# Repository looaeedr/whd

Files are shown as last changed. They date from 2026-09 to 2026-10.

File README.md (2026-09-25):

---
whd_doc_role: REFERENCE
whd_contract: repo-overview
whd_canonical: null
whd_schema: WHD_DOC_META_V1
---
<!-- WHD_DOC_ROLE role=REFERENCE contract=repo-overview -->
> **[REFERENCE]** 本 README 只提供專案概覽；其中既有架構描述保留作歷史背景，不擁有 current manufacturing contract。
> Current authority pointers：
- `個人AI檔案庫/第二層_專案與SOP/09_WHD_Canonical_Authority_Map.md` — contract/role ownership map。
- `個人AI檔案庫/第二層_專案與SOP/04_WHD鈑金展開幾何引擎規範.md` — 現行 `ae_engine` 製造架構、公開 API 與 Certified Registry boundary。
- `AGENTS.md` — Agent 啟動、Preflight、派工與驗收流程入口。

# WHD 板金展開自動化系統 (Sheet-Metal Unfolding Geometry Engine)

WHD 鈑金展開自動化系統是一套專為鈑金箱體加工設計的 2D 自動展開與 DXF 生成引擎。本系統已全面揚棄傳統「硬編碼頂點陣列 (Hardcoded Vertex Arrays)」與「單一零件獨立座標演算法」的舊式做法，採用現代幾何拓撲 (Topology) 與布林運算 (Shapely Polygon Boolean) 的核心架構。

---

## 💡 核心設計理念與架構宣告

> **「告別『新增零件 = 新寫一套外框公式』的傳統思維！」**

在全新幾何引擎中，所有零件外形皆收斂為以下核心公式：

Material Polygon = Base Polygon - Relief Polygon

1. **Topology (拓撲結構) 與 Factory Policy (製造規範) 徹底分離**：
   - **Topology**：定義板材的物理折彎結構（如四邊折彎 FourSideFlange、連續展開條帶 StripFoldChain）。
   - **Factory Policy**：定義各廠牌或特定箱體類型的裝配退讓（Relief）、過切 clearance 與缺角規則（如金庫型封頭尾裝配插入退讓）。
2. **新增零件極簡化**：
   - 未來新增任何新零件類型時，**嚴禁**重新手算 12 點、16 點或 17 點頂點陣列。
   - 只要既有的 Topology 與 Factory Policy 能描述該結構，新零件**僅需傳入折邊尺寸與裝配扣量**即可自動計算出 100% 精準的 2D 展開幾何。
3. **Geometry 是唯一真相來源 (Single Source of Truth)**：
   - GUI 預覽（Canvas）與 DXF 檔案導出統一呼叫 sheetmetal_geometry.py 幾何結果，確保「畫面所見即為 DXF 所出」。

---

## 🛠️ 系統分層架構

- **Layer A (sheetmetal_geometry.py)**：純 2D 板金幾何引擎。獨立於 DXF 與 GUI，只負責 Polygon 算術與 Bend 計算。
- **Layer B (ae.py)**：參數轉接層。讀取 config.ini / CSV 並呼叫幾何引擎生成各加工圖層（CUTTING, BEND, MARKING, CHECK 等）。
- **Layer C (gui.py / batch_unfolder.py)**：GUI 操作介面與自動化批次處理產線。

---

## 📦 目前已涵蓋的零件拓撲

- Door / Stretched Door (門板 / 延伸門板)
- Box Body / Stretched Box Body (箱身 / 延伸箱身)
- End Cap / Tail (金庫型封頭 / 封尾)
- Indicator Box (指示燈盒子 / 小門)
- Base Plate (底板)

---

## 🚀 快速開始

### 環境需求
- Python 3.8+
- Shapely
- ezdxf

### 安裝依賴
`ash
pip install -r requirements.txt
`

### 執行 GUI 計算器
`ash
python gui.py
`

### 執行完整測試套件 (TDD Baseline)
`ash
pytest
`

---

## 📖 系統文件與交接指南

更詳細的開發規格與金庫型製造規範請參考專案文件：

- AGENTS.md — 專案核心精神與 AI 開發總覽。
- handoff/ 目錄：
  - 00_AI_HANDOFF_README.md — 快速接手說明
  - 01_ARCHITECTURE.md — 幾何與拓撲分層架構
  - 02_VAULT_FACTORY_RULES.md — 金庫型製造規範細節
  - 03_PART_TOPOLOGY_MAP.md — 零件與拓撲對照表
  - 04_DEVELOPMENT_RULES.md — 開發規範與 TDD 驗證

---

## 📄 授權與維護
© WHD Sheet Metal Automation System. All rights reserved.

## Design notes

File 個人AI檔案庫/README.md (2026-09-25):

---
whd_doc_role: REFERENCE
whd_contract: ai-library-reference
whd_canonical: null
whd_schema: WHD_DOC_META_V1
---

# 個人 AI 檔案庫

本 README 是 **AI Library 的導覽入口**，不是 WHD production、幾何、UI、release、remote QA 或 executable process 的 CURRENT authority。

AI Library 的用途是保存長期背景、協作偏好、專案 SOP、canonical authority 導覽，以及事故／踩坑 REFERENCE。任何規則若已有 CURRENT owner，README 只指向該 owner，不複製第二份 current prose。

## 目錄導航

目前頂層結構：

```text
個人AI檔案庫/
├── README.md
├── 第一層_核心檔案/
├── 第二層_專案與SOP/
└── 踩坑庫/
```

### 第一層_核心檔案

- `01_個人背景與身份.md`：長期背景與角色資訊。
- `02_溝通風格與輸出偏好.md`：溝通與輸出偏好。
- `03_核心目標與近期重點.md`：核心目標與近期重點。
- `04_全域AI協作規則.md`：跨任務 AI 協作 REFERENCE；不擁有 executable/process/domain CURRENT authority。
- `05_反饋學習與自我演化機制.md`：反饋與知識沉澱機制。

### 第二層_專案與SOP

主要入口包含：

- `01_DXF與CAD自動化全域規範.md`
- `02_通用任務SOP模板.md`
- `03_常用Prompt指令庫.md`
- `04_WHD鈑金展開幾何引擎規範.md`
- `05_CAD批次拆圖與特徵萃取規範.md`
- `06_踩坑記錄與防錯經驗庫.md`
- `07_Phase6尺寸語意與標準截角母規則.md`
- `07_WHD技能發現與掃描深模組規則.md`
- `08_WHD截角資料與2D入口收斂規則.md`
- `08_WHD技能建立與修改規則.md`
- `09_WHD_Canonical_Authority_Map.md`

第二層也可能包含日期化 verification、專案交接或其他 REFERENCE 文件；**檔名看起來較新不代表它是 CURRENT owner**。

### 踩坑庫

`踩坑庫/` 保存事故、反例、踩坑與復原經驗。這些資料可協助診斷與避免重犯，但不得因內容較詳細就覆蓋 CURRENT spec、Skill、registry 或 executable authority。

## Authority 規則

唯一的 canonical authority 導覽入口是：

`個人AI檔案庫/第二層_專案與SOP/09_WHD_Canonical_Authority_Map.md`

使用順序固定為：

```text
先找 Authority Map
→ 找到該 contract 的 CURRENT owner
→ 讀 CURRENT owner
→ 再用 REFERENCE / pitfall / historical evidence 補充背景
```

角色語意：

- `CURRENT`：該 contract 唯一現行 owner。
- `REFERENCE`：背景、方法、事故或延伸說明；不得覆蓋 CURRENT。
- `MIRROR`：相容入口／導覽，只能 pointer 到 canonical owner。
- `HISTORICAL`：歷史證據，不得進 current routing。

若 README、REFERENCE 或歷史文件與 Authority Map 指向的 CURRENT owner 衝突，以 CURRENT owner 為準；不要在 README 裡再建立平行規格。

## 使用方式

開始 WHD 任務時：

1. 先依 `09_WHD_Canonical_Authority_Map.md` 找到 contract owner。
2. 若屬 startup / process routing，依 `AGENTS.md` 與 required Skill 執行。
3. 若屬 manufacturing / geometry / UI / DXF / persistence 等 domain 行為，讀 Authority Map 指向的 CURRENT owner，不從 README 猜規格。
4. 需要事故背景時再讀 `06_踩坑記錄與防錯經驗庫.md` 或 `踩坑庫/`。
5. 驗證結果只能判斷實作是否符合 authority，不能反過來成為 production 或文件真值來源。

一般原始碼與文件修改以 **Git branch / commit** 為主要 rollback authority，不為每個檔案自動建立額外實體備份。只有下列情況才另外建立實體備份：

- 使用者明確要求；
- Git 無法保存或還原的外部資產；
- 高風險二進位資產。

本 README 不保存日期型 UI 狀態、Assembly layout、EndCap positioning、release 細節或其他產品 CURRENT 規格；這些內容應由各自 CURRENT owner、REFERENCE/HISTORICAL 文件、verification、Git history 或 GitHub Issue 保存。

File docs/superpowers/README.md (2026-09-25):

---
whd_doc_role: REFERENCE
whd_contract: superpowers-history-index
whd_canonical: null
whd_schema: WHD_DOC_META_V1
---
<!-- WHD_DOC_ROLE role=REFERENCE contract=superpowers-history-index -->
> **[REFERENCE / HISTORY INDEX]** 本目錄 README 索引 dated Superpowers/spec/verification evidence，不是 current manufacturing 或 project roadmap authority。
> Current authority：`個人AI檔案庫/第二層_專案與SOP/09_WHD_Canonical_Authority_Map.md`；製造架構/API：`個人AI檔案庫/第二層_專案與SOP/04_WHD鈑金展開幾何引擎規範.md`。

# Superpowers 接手說明 — 2026-08-21 截角類型／裝配語意

任何接手這次修改的代理或開發者，請依序閱讀：

1. `specs/2026-08-21-corner-type-semantic-assembly-design.md` — 已確認的工廠規則、資料責任與不可回退決策。
2. `plans/2026-08-21-corner-type-semantic-assembly-implementation.md` — 實作任務、修改檔案、介面與已完成項目。
3. `verification/2026-08-21-corner-type-semantic-assembly-verification.md` — 測試、DXF 製造驗證、原始 renderer 不變與行尾注意事項。
4. `../../修改日誌/20260821.md` — 人員可快速閱讀的修改摘要。

## 語言規則

- **使用者可見介面一律使用繁體中文。**
- 新增或修改的操作說明、錯誤訊息、固定截角摘要與交付文件應優先使用繁體中文。
- **程式內部識別字**（Python 類別、函式、enum、欄位、API 參數與相容代碼）為避免破壞相容性可保留英文，例如 `CornerTypeId`、`CrossCornerMode`、`INSERT_OVERLAY`。
- 文件若必須提到英文識別字，需同時用繁體中文說明其製造意義，不能只留下英文名稱讓操作人員自行猜測。

## 不可回退的關鍵決策

- 截角類型本身就是裝配關係；不要再新增另一套可獨立修改的裝配旗標。
- 新 GUI 禁止回到 `C01~C04` 或 `0°/90°` 的截角操作方式。
- 嵌入貼外型第二級參數在 UI 仍叫「嵌入留肉」，但**正確二級 CUTTING = 側折 + 嵌入留肉量**；`FW - 嵌入留肉量` 只是兩級切線之間剩下的材料寬度，不是切線座標。
- 純嵌入會讓箱身高度由 `H-2T` 變成 `H-T` 或 `H`；孔位與特徵基準必須同步。
- `fold_designer_original.py` 的製造幾何與操作模型保持不動；本次只允許為「全域文字縮放」增加字級倍率。
- 型號 UI 使用「自訂」；它是目前已知資料的可編輯副本，不是另一套空白預設。舊「未知類型」只做相容讀取。
- 指示燈盒與指示燈小門是共享固定板件，截角類型唯讀。

## 2026-08-21 晚間修正

- 已撤銷先前錯誤的 `39mm` 二級截角規格。`側折=15、T=2、嵌入留肉=0.5T` 時，正確二級 CUTTING 為 `16mm`、深度 `4mm`。
- 新增全域 **文字大小：小 / 中 / 大**。現有字級定義為「小」；中為 `1.2×`、大為 `1.4×`。
- 文字縮放只改 Tk/ttk/Canvas/Matplotlib 文字，不改 CAD 幾何、畫布座標、DXF 尺寸或折彎數值。
- 交付與 patch 不覆蓋現場 `config.ini`；使用者切換文字大小時才由程式寫入 `[UI] text_size`。
## 2026-08-23：Phase6 截角／貼外型後續修正

本輪接手時，除上列既有文件外，必須再遵守以下已確認規則：

- **上方 CornerType 是封頭／封尾裝配語意真值。** `assembly_type` 只能作 UI／相容 mirror，不得在載入時反向覆寫上方 CornerType。
- **貼外型（`OVERLAY`）的封頭／封尾沒有左右 X 向折彎。** 因此 2D／3D 不生成這些 X 向 BEND，Fold Designer 的 Head/Tail 不顯示 X 軸折彎頁。
- **OVERLAY 的 X 材料外框同樣沒有舊折邊寬。** Head/Tail flat span = `W`；不得保留 `W-4T+yl1+yr1` 的舊 INSERT 型材料寬。下方 `WIDTH+1.5T` 只屬角落 CUTTING。
- **使用者明確選擇 `OVERLAY` 時，下方截角帶入既有 CROSS 多切預設：`EXTRA_CUT + WIDTH + 1.5T`。** 這只是本次選擇時的初始值；之後使用者仍可改成高、寬＋高或其他既有 CROSS 設定。普通 refresh/load 不得把人工修改洗回預設。
- `CROSS + EXTRA_CUT` 是通用幾何手段，不等同單一機械目的；可用於避讓自身折邊，也可用於避讓組裝後另一片板金。不得因此新增重複 CornerType。
- 自訂模式不載基準 DXF，因此基準檔專屬開孔／固定孔設定不得在自訂模式顯示；也不得從「進階設定」繞路重新出現。
- 箱身「對稱折彎」入口放在 Fold/BEND 編輯區；對稱模式下刪除可刪折段時，鏡像段必須交易式同步刪除。
- 3D Fold Designer 是 modal transaction：開啟期間主 2D 不得同時修改；確定才提交，取消／關閉丟棄草稿。
- 2D CornerType 縮圖方向依 active target：上方維持垂直翻轉，下方恢復原始方向；只改 preview canvas，不改製造幾何。
- UI 數值不得露出 `400.0000000000006` 類浮點尾差；近整數只做文字正規化，合法小數保持。
- **不得碰 `config.ini`，除非使用者明確要求。** 交付固定提供完整包與只含本次變更檔的更新包，FULL/UPDATE 檔名共用 Asia/Taipei `YYYYMMDD_HHMMSS` 時間戳。

詳細截角層級與 OVERLAY 規則見 `specs/2026-08-21-corner-type-semantic-assembly-design.md` 的 2026-08-23 補充。

## 操作員使用說明書

- `../../使用說明書.md` — 使用者操作手冊；現已包含正式截角類型、十字截角模式、方向、xT、封頭／封尾上下截角用途與舊 C01~C04 對照。

- **板件存在狀態全鏈規則**：`existing_parts` 是 physical presence 單一真值；輸出 checkbox 不得決定存在性。刪除板件要同步從左側尺寸、右側 2D、3D、FinalScene、保存/重載與 DXF/NC/批次輸出消失，profile stash 只供重新新增恢復。
- **除錯範圍規則**：修一個症狀必須主動追完整資料鏈，不等待使用者逐層提醒相依問題。

## 2026-08-23：全域專案檔案操作（取代舊 3D Footer 讀／存入口）
- `.p6fold` 是**整個專案**；主視窗左上角固定提供「開啟專案 / 儲存專案 / 另存新檔」。3D 是 modal，因此 3D 視窗左上角也提供同一組全域入口；不得綁在某一板件頁或 3D Footer。
- 各板件頁／3D 編輯器只負責自己的 draft 交易：`套用 / 確定 / 取消`；不得把局部交易按鈕命名或實作成全專案存檔。
- `開啟專案` 與 Windows 雙擊 `.p6fold` / argv 共用主 GUI 的 authoritative `load_phase6_project()`；不得建立第二套 restore 邏輯。
- `儲存專案`：已有目前路徑時直接覆存完整 `.p6fold`；無路徑時轉入「另存新檔」。`另存新檔` 才詢問新路徑。
- GUI 全域「開啟專案」只還原主專案，不強迫跳進 3D；雙擊 `.p6fold` 的啟動流程可依既有 argv 行為開到保存的 active part。
- 讀檔後 `existing_parts`、2D/3D、輸出資格、CornerType/Fold/features 與全域尺寸必須同步來自同一 snapshot。

## 2026-08-23：CornerType 細參數鎖
- CornerType 細參數預設 **鎖定並真正隱藏**；2D/3D 都必須有明確 `參數鎖定 / 參數解鎖` 文字。鎖定時細節 frame 與 `左右相同` 等進階控制零佔位，只保留 CornerType/摘要供辨識。
- 鎖只是 UI 防誤觸，不是製造資料；鎖定／解鎖不得修改 `CornerTypeSelection`，也不保存成 `.p6fold` 機械狀態。載入專案後 UI 一律回到鎖定。
- 自訂盤型：CornerType 類型照既有規則可選；細參數需解鎖才可改。
- 已知盤型：factory CornerType **類型固定不可改**，但同一類型的細參數可解鎖微調；人工細參數必須走完整 Save/Load、2D/3D、baseline manufacturing 鏈而保留。
- 已知盤型細參數覆寫不得讓板件退化成自訂 builder；基準 DXF、固定孔、MARKING 等 secondary entities 必須保留，只替換由 Corner policy 決定的 structural outline / BEND。
- `indicator_box` / `indicator_door` 是固定共享板件：維持真正唯讀，不提供解鎖。

## 2026-08-23：ProjectSession 專案交易所有權
- `phase6_project_session.py` 是 `.p6fold` 專案交易生命週期的唯一協調層，正式區分 `project_path / loaded_baseline / committed / draft`。
- `loaded_baseline` 只代表最近一次成功載入的原始 snapshot；主 GUI 後續修改與 3D 確定不得反向改寫它。
- `committed` 是正式專案 Source of Truth；全域 Save / Save As 只可保存 committed 機械狀態。
- `draft` 是 3D transaction 的隔離種子／生命週期標記，不是每個 Tk 欄位的 live mirror。Fold Designer 在自己的 defensive copy 編輯；取消丟棄，確定後先套回 main GUI，再以 canonical main snapshot commit。
- active draft 存在時 `capture_committed()` 必須拒絕，防止 caller 繞過 transaction；明確的 `load_project()` 才能取代舊交易並清除 draft。
- main-connected 3D `儲存專案 / 另存新檔` 必須委派 main GUI committed save；不得由 Bridge 把 staged 3D workspace 直接寫成正式 `.p6fold`。
- `active_part` 是純導航 metadata：3D Save 時可保存目前板件位置，但僅限該板件已存在於 committed `existing_parts`；尺寸、CornerType、Fold Profile、開孔與板件增刪仍不得從未確定 draft 滲入。
- `_runtime_project_path` 只屬執行期資訊，不得持久化進 `.p6fold`。
- 詳細設計：`specs/2026-08-23-phase6-project-session-design.md`；驗證：`verification/2026-08-23-phase6-project-session-verification.md`。

## 2026-08-23：Settings 單一 Runtime 狀態來源
- `phase6_settings_center.py` 的 `SettingsService` 是 Phase6 **已確認 Runtime Settings** 唯一所有者；`Phase6Settings` 提供 immutable / defensive snapshot。
- `config.ini` 只代表**下次啟動的 persisted defaults**，不是目前 Runtime Source of Truth；寫入預設值不得順便提交目前 Runtime。
- `ae.default_config` 繼續是「還原初始值」唯一 Factory Defaults 來源，不受目前 Runtime 或 `config.ini` 後續變更影響。
- Main GUI 的 Tk 變數只是 UI mirror；主畫面設定變更必須經 `SettingsService.update()` 正規化並同步 AE compatibility globals。
- Fold Designer `_settings_values` 保留為 3D transaction-local draft；取消不提交，確定後才由 main GUI 經 `SettingsService.update()` 成為 committed runtime。
- 3D「儲存為預設值」使用 `SettingsService.persist_defaults(...)`：可把 draft 寫入 `config.ini` 供下次啟動使用，但當下 service 與 AE runtime 必須保持原 committed 值。
- `save_defaults_to_ini(..., apply_runtime=True)` 僅保留舊 caller 相容；新 production ownership 路徑由 service 以 `apply_runtime=False` 呼叫。
- 詳細設計：`specs/2026-08-23-phase6-settings-single-source-design.md`；驗證：`verification/2026-08-23-phase6-settings-single-source-verification.md`。

## 2026-08-23：GUI Project Controller seam
- `phase6_project_controller.py` 是主 GUI 的**專案 use-case Controller**；它隱藏 `.p6fold` 持久化與 ProjectSession ordering，GUI 不得重新實作 active-draft Save 判斷。
- `ProjectSession` 仍是交易 Source of Truth；Controller 不得保存另一份 committed/draft/path mirror。
- GUI 是 View adapter：`_compose_phase6_project_snapshot_from_main_gui()` 負責 View → canonical snapshot，`_apply_phase6_project_snapshot()` 負責 snapshot → View；不要把 Tk widget 或 renderer 搬進 Controller。
- Controller 的 `snapshot_provider` 是刻意的 interface：active draft Save 時 provider 不會被呼叫，讓「未確認資料不得進正式檔」成為模組 invariant，而不是 caller 默契。
- `active_part` 仍是導航 metadata，只有 committed `existing_parts` 內既有板件可覆寫；不得擴張成提交機械 draft 的旁路。
- 詳細設計：`specs/2026-08-23-phase6-gui-project-controller-design.md`；驗證：`verification/2026-08-23-phase6-gui-project-controller-verification.md`。

## 2026-08-23：Workspace Controller seam
- `phase6_workspace_controller.py` 是主 GUI committed workspace 的唯一狀態模組，擁有 `existing_parts / active_part / part_profiles / box_body_profile` 與其 invariant。
- `box_body` 永遠存在；authoritative workspace 建立後，export checkbox 或 legacy indicator fallback 只能影響顯示／輸出選擇，不能反向改寫 physical presence。
- 刪除板件只改 presence，不刪除 profile stash；重新新增可復用原 profile。若刪到 active part，Controller 自動回退到合法板件。
- `fold_designer_part_bundle / _phase6_existing_parts / _fold_designer_last_part_key / fold_designer_box_body_profile` 只保留 compatibility property，不能再有 backing state；production method 不得依賴這些 alias。
- Head/Tail linked profile 的幾何推導仍在既有 geometry resolver；Workspace Controller 只保存最終結果，不得 import Tk 或 AE。
- 專案 workspace replacement 要區分：`box_body_profile` 欄位存在且為 `None` = 明確清除舊 Fold Chain；欄位不存在 = partial update，保留現況。
- 詳細設計：`specs/2026-08-23-phase6-workspace-controller-design.md`；驗證：`verification/2026-08-23-phase6-workspace-controller-verification.md`。

## 2026-08-23：Fold Designer Bridge domain ownership seam
- `phase6_endcap_semantics.py` 是 EndCap assembly/FW/raw CornerType 狀態的 owner；`assembly_type` 仍只是由 Head/Tail 上方 CornerType 推導出的相容／顯示 mirror。
- `phase6_fold_profiles.py` 是 BoxBody/EndCap Fold Profile 與 linked mating chain 的 owner；profile build/read/merge 與 outside-dimension compensation 不再實作在 Bridge。
- `fold_designer_bridge.py` 保留 Fold Designer/Tk transaction、View/Scene adapter 與 compatibility re-export；不得重新實作已移出的 domain 規則。
- `gui.py` 直接 import 真正 owner，不能把 Bridge 當成 domain facade 再把所有規則集中回同一大檔。
- Compatibility re-export 必須是同一 function object，不可新增 wrapper 或 alternate branch。
- 詳細設計：`specs/2026-08-23-phase6-fold-designer-bridge-slim-design.md`；驗證：`verification/2026-08-23-phase6-fold-designer-bridge-slim-verification.md`。

- 2026-08-23：FinalScene 3D View ownership → `phase6_final_scene_view.py`；Bridge 只保留 query/request adapter。詳見 `specs/2026-08-23-phase6-final-scene-view-design.md`。

## 2026-08-23：診斷快照所有權接縫
- `phase6_diagnostics.py` 是 Phase6 診斷 schema、JSON-safe、Scene／Material／FoldGuide 序列化與 all-part Final Geometry diagnostics 的 owner。
- `fold_designer_bridge.py` 只保留 Designer state → diagnostic context、manufacturing payload/provider adapter 與 Tk 檔案對話框；不得重新實作 diagnostics serializer。
- standalone diagnostic 與 `.p6fold.final_geometry` 共用同一序列化規則，避免 schema／error handling 雙軌漂移。
- Diagnostics 不擁有 ProjectSession、Settings、CornerType、Fold Profile 或 manufacturing build；診斷資料不能反向成為機械 Source of Truth。
- 詳細設計：`specs/2026-08-23-phase6-diagnostic-snapshot-design.md`；驗證：`verification/2026-08-23-phase6-diagnostic-snapshot-verification.md`。

## 2026-08-23：3D Designer 草稿工作區所有權
- `phase6_designer_workspace.py` 是 Fold Designer 內部草稿工作區的唯一生命週期 owner，集中管理板件 presence、active/selected、profile/feature stash、dirty 與 switching 狀態。
- `fold_designer_bridge.py` 保留 Tk／Editor／manufacturing adapter：從 Bend UI、孔位 editor 與 Settings draft 收集資料後寫入 Workspace；Workspace 不得 import Tk、AE、renderer、ProjectSession 或 SettingsService。
- `available_parts / active_part_key / selected_part_key / _phase6_part_profiles / _phase6_part_features / _phase6_part_face_features / _phase6_workspace_dirty / _phase6_switching_part` 僅保留 compatibility property，禁止形成第二份 backing state。
- 板件切換 ordering 固定為：先保存 outgoing draft，再 `begin_switch(target)`，最後完成 target UI／holes／settings／FinalScene 同步後 `finish_switch()`；Workspace 不負責任何 UI 副作用。
- 刪除板件只移除 presence，不刪 profile／feature stash；重新加入時優先恢復 stash。`box_body` 永遠不可刪。
- Project snapshot、Diagnostics 與 Scene query 的 presence／active／profile／features 必須從同一 `designer_workspace.snapshot()` 或同一 owner 取得，不可重新手拼 legacy state。
- 詳細設計：`specs/2026-08-23-phase6-designer-workspace-design.md`；驗證：`verification/2026-08-23-phase6-designer-workspace-verification.md`。

## 2026-08-23：統一開孔編輯器交易狀態機
- `phase6_hole_editor_session.py` 的 `Phase6HoleEditorSession` 是統一開孔編輯器 transaction state 的唯一 owner，集中管理 context、selection、active edit before snapshot、Undo 與 Confirm/Cancel ordering。
- Tk/Canvas 仍只負責事件、顯示與幾何 candidate 計算；孔位 surface、hit-test、reference distance、round-fill、Indicator geometry 仍由既有幾何 owner 負責。
- transient edit 使用整個 active context 的 before snapshot，因此插入、拖曳、旋轉、十字基準、reference distance、圓孔排列 preview 共用同一 Cancel/Undo 語意。
- process toggle、delete 是 immediate committed action；Session 先處理未完成 active edit，再推 Undo snapshot，禁止 caller 各自維護第二份 `active_snapshot / undo_history`。
- context switch 一律先取消未確認 transient edit，切換後 selection 與 Undo scope 重置；Cancel All 恢復所有已登錄 context 的 original snapshot，Confirm All 保留現況。
- `_open_unified_hole_editor()` 不得再直接 `append/del/item assignment` 修改 `feature_list`；mutation 必須經 Session action。
- 詳細設計：`specs/2026-08-23-phase6-unified-hole-editor-session-design.md`；驗證：`verification/2026-08-23-phase6-unified-hole-editor-session-verification.md`。

## 2026-08-23：統一開孔編輯器 Canvas View ownership
- `phase6_hole_editor_canvas_view.py` 的 `Phase6HoleEditorCanvasView` 是統一開孔編輯器 Canvas transform、resolved-feature cache、hit-test 與浮動參考框 placement 的唯一 View owner。
- `Phase6HoleEditorSession` 仍是開孔 transaction Source of Truth；Canvas View 只讀 feature list，不得修改孔位資料。
- `_open_unified_hole_editor()` 保留 Tk 組裝、domain adapter、Door/Indicator extension 與 event orchestration，但不得再自行維護 `transform_box`、重做 `resolve_surface_features()` 或 hit-test。
- Door enclosure／indicator manufacturing preview 透過 `draw_extra` callback 注入，View 不 import `manufacturing_api`，避免顯示層變成第二個製造幾何 owner。
- mouse event 固定走 `canvas_view.canvas_to_world()`／`canvas_view.hit_test()`，因此 redraw 與點擊命中共用同一 transform／resolved cache。
- 詳細設計：`specs/2026-08-23-phase6-hole-editor-canvas-view-design.md`；驗證：`verification/2026-08-23-phase6-hole-editor-canvas-view-verification.md`。

## 2026-08-27：Shared Assembly World Geometry 與最新 3D Designer 導航
- `ae_engine/assembly_geometry.py` 是 Folded Mesh 與 Assembly Placement 的共同 Source of Truth；`phase6_final_scene_view.py` 與 `ae_engine/assembly_collision.py` 都委派同一套 world geometry。
- 第一階段 assembly scene 僅包含 `box_body / head / tail`，不混入 door / base plate。
- 最新 UI 不再使用獨立 `單件 / 組合體` 模式按鈕：`組合體` 直接是左側 `板件選擇` 第一項，第一次進 3D 預設顯示組合體；選實際板件自動切 single-part editor。
- 最上列固定：檔案、3D 顯示（文字大小/折彎透視/面板透視）、全螢幕、還原初始值/取消/確定。全域設定固定兩行：基準型號/參數鎖定/儲存預設值；W/H/D/T/結構/組合方式。
- 右側不再有 duplicate control bar；只保留解鎖後板件設定／組合體診斷與 3D canvas。組合體模式不顯示一般板件設定；解鎖時顯示組合體診斷。
- UI 驗收使用真 Tk，檢查 menu 第 0 項、初始 assembly mode、widget master/grid row 與切換實際板件後 single mode。
- 詳細驗證：`verification/2026-08-27-3d-layout-assembly-entry-verification.md`。
- 2026-08-28 組合體接合／實體板最新語意：assembly placement 必須消費 `組合方式 -> CornerType -> resolved Fold Profile`；EndCap local `z=0` 是板厚**中心面**、local `+z` 是折邊朝箱內方向。Head +Z 向下；Tail 保持 authoritative native X/Y orientation（禁止二次上下鏡射），+Z 向上。組合體以真實 `T` 將 mid-surface 生成內外兩個 skin；中心面向箱外偏移 T/2，使內側 skin 貼箱身、外側成型面位於箱外。`OVERLAY` X flat、`INSERT / INSERT_OVERLAY` X folded。viewer 與 collision 共用 `ae_engine.assembly_geometry` physical-sheet geometry；不得再把零厚度 z=0 中心皮當 mating face。另保留 `組合體 -> 箱身` 不得 early-return 的 UI 切換規則。詳細驗證：`verification/2026-08-27-assembly-semantic-mating-and-switch-verification.md`、`verification/2026-08-28-endcap-physical-sheet-assembly-verification.md`。

- 2026-08-28：EndCap physical-sheet 組合體孔／折彎稜線顯示回歸已修正；closed solid 不再被誤當唯一 edge source，孔輪廓與真實 crease 從 folded mid-surface 抽取。驗證：`verification/2026-08-28-endcap-assembly-edge-visibility-verification.md`。
- 2026-08-28 06:49：EndCap 孔口顯示再修正：mid-surface hole outline 會被 physical skin 遮蔽，因此組合體改由 thickened solid 的非共面 physical feature edges 顯示真正位於 ±T/2 skin 的 through-hole rim；3D BEND guide 全部改為 solid `-`。同一 verification 文件已追加 RED/GREEN 與真 GUI 驗證。

- 2026-08-28 08:00：組合體參數解鎖新增診斷面板；固定截角診斷的碰撞 probe 已收斂為 `restored - production` relief delta，禁止整片 EndCap surface crossing，避免正常 mating seam 整圈誤紅。標準金庫型由早期無效的 947 段整圈交線收斂為 454 段局部角落交線（Head/Tail 各 227）；命中的 delta triangles 可畫半透明紅面並疊紅色實線。關閉忽略固定截角時不執行此 probe。正式 CUTTING/DXF 暫不刪固定截角；renderer 不得依賴 `assembly_collision` solver，純診斷 geometry 位於既有 `assembly_geometry.py`。AI 交付前須自行檢查 Head/Tail 視角。驗證：`verification/2026-08-28-assembly-interference-diagnostic-verification.md`。

## 2026-08-28：3D 干涉反投影正式截角
- 設計：`specs/2026-08-28-assembly-relief-backprojection-design.md`
- 實作計畫：`plans/2026-08-28-assembly-relief-backprojection.md`
- 驗證：`verification/2026-08-28-assembly-relief-backprojection-verification.md`
- 固化結論：固定截角只保留作 corner topology/search domain；正式 Head/Tail CUTTING 尺寸由 world-space physical interference 反投影 flat UV 後求得，加入 A 後再折回 3D，零材料穿透才可 verified。verified cut 進 `EndCapPartSpec` / Manufacturing API，2D/3D/DXF 共用；BEND 依新 material 重新 clip。

## 2026-08-28 19:00 組合體介面同步修正
- Verification: `docs/superpowers/verification/2026-08-28-assembly-scene-contract-sync-verification.md`
- 重點：UPDATE 必須成對同步 `fold_designer_bridge.py` caller 與 `phase6_final_scene_view.py` 的 `AssemblySceneRenderData` contract；交付前必須用舊 FULL 疊 UPDATE 的真主 GUI 路徑驗證。

## 2026-08-28 參數解鎖面板可見性
- 組合體/單件右側可切換設定面板必須透過 `_phase6_pack_right_panel_above_canvas()` 插在 Matplotlib canvas 前方；`winfo_manager()==pack` 不足以證明可見。
- 真 Tk 回歸必須 `parameter_lock_button.invoke()` 後驗 `winfo_viewable()==1` 且高度 > 1。
- 驗證：`verification/2026-08-28-parameter-lock-panel-visibility-verification.md`。

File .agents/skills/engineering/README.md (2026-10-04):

---
whd_doc_role: REFERENCE
whd_contract: skill-navigation
whd_canonical: null
whd_schema: WHD_DOC_META_V1
---
# Engineering

Engineering skills used for code, design, QA, specs and delivery.

> Navigation only. This README is not Skill existence or active-status authority. Filesystem scanning provides inventory evidence; `.agents/skills/skill_catalog.json` provides WHD classification. Only `canonical` entries are active WHD canonical Skills.

## User-invoked navigation

- **[flow-v2-execution](./flow-v2-execution/SKILL.md)**: WHD execution/control-plane 唯一 CURRENT runtime contract；ExecutionRecord、atomic transaction、lease/YIELD、scheduler、handoff、recovery 與 closure 都以此為準。
- **[root-local-first](./root-local-first/SKILL.md)**: 互動式／預設 repository content work 的 root-first gate；root 測綠與 diff freeze 後才解鎖 Git work branch。

- **[ask-matt](./ask-matt/SKILL.md)**: Router over engineering/productivity flows.
- **[拷問邊建立文件](./拷問邊建立文件/SKILL.md)**: 深度質詢並同步維護 `CONTEXT.md` / ADR。
- **[triage](./triage/SKILL.md)**: Move issues through triage roles.
- **[掃描深模組](./掃描深模組/SKILL.md)**: WHD 深層架構掃描；使用者點名時讀此 Skill。
- **[驗證板件與DXF](./驗證板件與DXF/SKILL.md)**: 驗 current/resolved physical parts、DXF reopen、multipart、Save→Reload 與 remote QA。
- **[setup-matt-pocock-skills](./setup-matt-pocock-skills/SKILL.md)**: Upstream/reference setup material；classification 由 catalog 決定，不是 WHD governance owner。
- **[寫成規格書](./寫成規格書/SKILL.md)**: 從 grounded conversation/code/AI Library 產生工程規格。
- **[拆解任務工單](./拆解任務工單/SKILL.md)**: Requirement RED-first，經核准後拆 tracer-bullet tickets。
- **[執行開發任務](./執行開發任務/SKILL.md)**: 依核准 spec/ticket 實作，遵守 TDD、checkpoint、派工與 QA gate。
- **[寫技能](./寫技能/SKILL.md)**: 建立、修改、驗證與改善 Skill。
- **[派工](./派工/SKILL.md)**: Flow v2 dispatch bridge；explicit READY ingress → native ExecutionRecord。
- **[工作槽](./工作槽/SKILL.md)**: Flow v2 slot projection/routing bridge；固定 /工作0～/工作3，/工作0 為預設互動入口；無獨立 slot state。
- **[wayfinder](./wayfinder/SKILL.md)**: Plan large multi-session work as decision tickets。

## Model- or user-reachable navigation

- **[prototype](./prototype/SKILL.md)**
- **[monitoring-remote-qa](./monitoring-remote-qa/SKILL.md)**
- **[deterministic-repo-migration](./deterministic-repo-migration/SKILL.md)**: authority-driven repository migration；先 inventory，再 deterministic apply、strict validation、idempotence 與 drift audit，validator 不得成為 authority。
- **[long-log-context-safe-execution](./long-log-context-safe-execution/SKILL.md)**: 超長 pytest/Xvfb/remote CI 輸出的落檔、bounded tail、failure slice、cursor 與 Runtime-cut 續接規則。
- **[diagnosing-bugs](./diagnosing-bugs/SKILL.md)**
- **[research](./research/SKILL.md)**
- **[tdd](./tdd/SKILL.md)**
- **[Python測試實務](./Python測試實務/SKILL.md)**
- **[性質導向測試](./性質導向測試/SKILL.md)**
- **[尺寸語意分析](./尺寸語意分析/SKILL.md)**
- **[UI設計與去AI味](./UI設計與去AI味/SKILL.md)**
- **[領域建模](./領域建模/SKILL.md)**
- **[程式碼庫設計](./程式碼庫設計/SKILL.md)**
- **[code-review](./code-review/SKILL.md)**
- **[resolving-merge-conflicts](./resolving-merge-conflicts/SKILL.md)**
- **[wizard](./wizard/SKILL.md)**
- **[截角資料入口收斂](./截角資料入口收斂/SKILL.md)**
- **[issue-closure-gate](./issue-closure-gate/SKILL.md)**
- **[phase6-corner-3d-model-integrity](./phase6-corner-3d-model-integrity/SKILL.md)**
- **[phase6-release-packaging](./phase6-release-packaging/SKILL.md)**
- 其他 internal Phase6 Skills 即使本 navigation 未逐一列出，也不因此消失；以 filesystem inventory + catalog classification 判定。

## Canonical identity rule

中文 Skill 資料夾的 frontmatter `name` 必須與資料夾 basename 完全相同。舊英文 identity 只能作 migration/history；是否 active 仍由 `skill_catalog.json` classification 決定。

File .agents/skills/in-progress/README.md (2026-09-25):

---
whd_doc_role: REFERENCE
whd_contract: skill-navigation
whd_canonical: null
whd_schema: WHD_DOC_META_V1
---
# In Progress — upstream-beta

Classification: `upstream-beta`.

These Skills are intentionally experimental/upstream Beta. Their `SKILL.md` files remain repository inventory, but **file presence does not make them active WHD canonical Skills**. They may change or disappear without warning and are excluded from WHD current routing unless explicitly reclassified through `.agents/skills/skill_catalog.json`.

Examples currently kept in this bucket include `loop-me`, `writing-beats`, `writing-fragments`, `writing-shape`, `claude-handoff`, `setup-ts-deep-modules`, and `implement-spec`.

Promotion rule: moving or copying a Skill into a stable bucket is not enough by itself. Graduation requires an explicit catalog classification change plus the normal WHD Skill governance, Preflight and regression checks.

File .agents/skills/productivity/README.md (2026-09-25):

---
whd_doc_role: REFERENCE
whd_contract: skill-navigation
whd_canonical: null
whd_schema: WHD_DOC_META_V1
---
# Productivity

General workflow tools, not code-specific.

> Navigation only. Filesystem `SKILL.md` proves inventory; `.agents/skills/skill_catalog.json` decides WHD classification. Only `canonical` is active WHD canonical.

## User-invoked navigation

- **[handoff](./handoff/SKILL.md)**: Compact the current conversation into a handoff document.
- **[teach](./teach/SKILL.md)**: Teach a skill or concept over multiple sessions using the current directory as state.
- **[to-questionnaire](./to-questionnaire/SKILL.md)**: Turn an external decision gap into a Markdown questionnaire.
- **[wait-what](./wait-what/SKILL.md)**: Re-pitch a message with missing context in plain language.
- **[深度質詢](./深度質詢/SKILL.md)**: canonical WHD deep-interview / design-tree Skill. Legacy `grill-me` 已 retired，不再是 current invocation entry。

## Model- or user-reachable navigation

- **[MCP工具操作](./MCP工具操作/SKILL.md)**: 依目前 runtime 真實能力操作 MCP。
- **[找技能](./找技能/SKILL.md)**: 搜尋、驗證、比較外部 Skill；外部 Skill 不會自動納入 WHD。
- **[深度質詢](./深度質詢/SKILL.md)**: 逐輪釐清 plan / decision / idea。
- **[writing-for-agents](./writing-for-agents/SKILL.md)**: Writing documents for agents。

## Canonical identity rule

中文 Skill 資料夾的 frontmatter `name` 必須等於資料夾 basename。`grill-me` / `grilling` 只保留 retired/history mapping，不得再競爭 routing；replacement 是 `深度質詢`。

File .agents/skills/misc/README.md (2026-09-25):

---
whd_doc_role: REFERENCE
whd_contract: skill-navigation
whd_canonical: null
whd_schema: WHD_DOC_META_V1
---
# Misc

Tool-specific or rarely used helpers.

> Navigation only. `.agents/skills/skill_catalog.json` owns classification. `misc/**` defaults to `tool-specific`; an explicit higher-priority catalog rule is required to promote a WHD canonical exception.

## tool-specific navigation

- **[git-guardrails-claude-code](./git-guardrails-claude-code/SKILL.md)**: Claude Code-specific git hooks; not WHD canonical governance.
- **[migrate-to-shoehorn](./migrate-to-shoehorn/SKILL.md)**: TypeScript migration helper.
- **[scaffold-exercises](./scaffold-exercises/SKILL.md)**: Exercise scaffolding helper.
- **[setup-pre-commit](./setup-pre-commit/SKILL.md)**: JS/Husky pre-commit setup helper.

## WHD canonical override

- **[git-remote-sync-fallback](./git-remote-sync-fallback/SKILL.md)**: WHD project-local remote sync fallback；catalog 明確 override 為 `canonical`。

檔案存在不代表 active canonical；以 catalog classification 為準。

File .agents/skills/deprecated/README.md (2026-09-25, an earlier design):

---
whd_doc_role: HISTORICAL
whd_contract: retired-skill-provenance
whd_canonical: null
whd_schema: WHD_DOC_META_V1
---
# Deprecated — retired

Classification: `retired`.

Skills in this bucket are not active WHD canonical and must not participate in current routing. Historical identity/replacement mapping belongs in `.agents/skills/skill_catalog.json` under `retired_aliases` when a retired name still matters for migration or audit.

A retired Skill may be physically deleted while its catalog alias record remains, so historical names stay explainable without remaining invokable.

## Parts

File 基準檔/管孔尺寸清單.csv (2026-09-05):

圖塊代號 | 加工孔徑尺寸
*D1 | Ø 116.0000
*D2 | Ø 92.0000
*D3 | Ø 77.0000
*D4 | Ø 63.0000
*D5 | Ø 51.0000
*D6 | Ø 45.0000
*D7 | Ø 35.5000
*D8 | Ø 27.5000
*D9 | Ø 23.0000
*D10 | Ø 20.0000
*D11 | Ø 26.0000
*D12 | Ø 34.0000
*D13 | Ø 40.0000
*D14 | Ø 52.5000
*D15 | Ø 64.5000

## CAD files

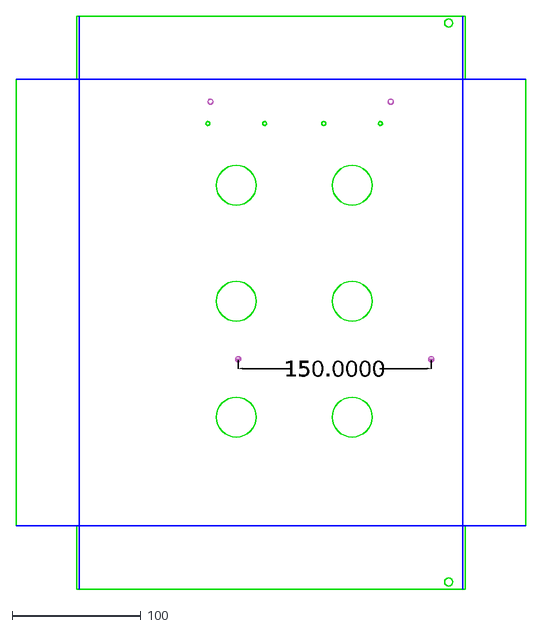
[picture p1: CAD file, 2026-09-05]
基準檔/指示燈/盒子.dxf
150.0000

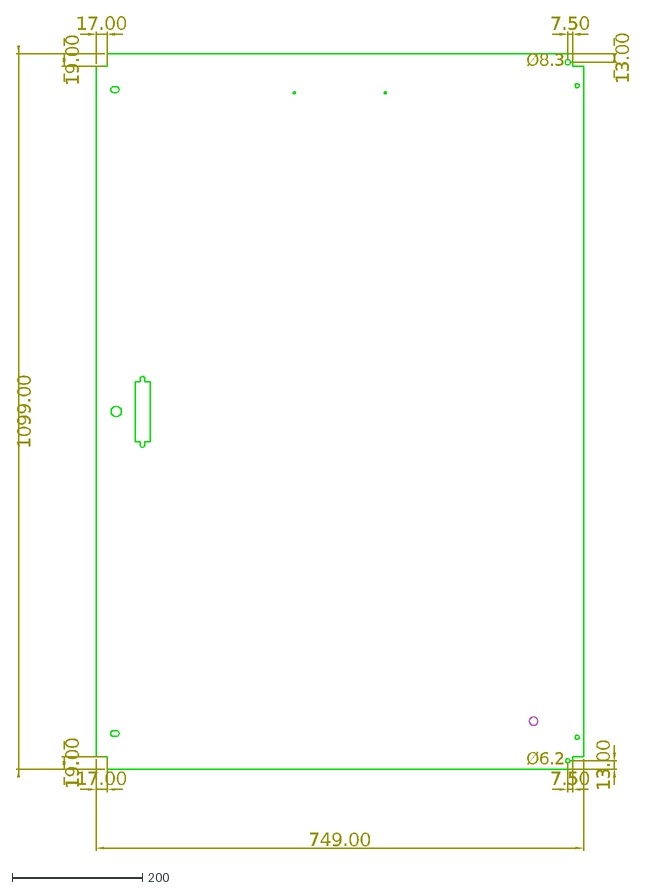
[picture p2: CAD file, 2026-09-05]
基準檔/通用/19門.dxf
1099.00
749.00
17.00
19.00
7.50
13.00
Ø8.3
Ø6.2

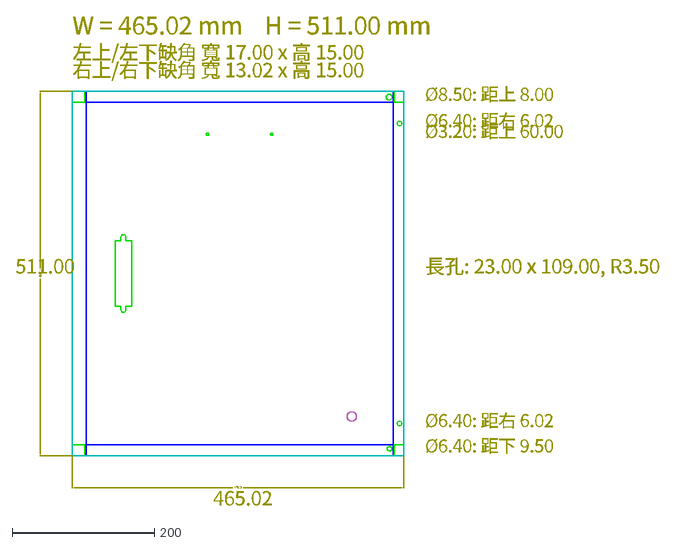
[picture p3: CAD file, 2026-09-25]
基準檔/金庫型/門.dxf
465.02
511.00
W = 465.02 mm H = 511.00 mm
左上/左下缺角 寬 17.00 x 高 15.00
右上/右下缺角 寬 13.02 x 高 15.00
長孔: 23.00 x 109.00, R3.50
Ø6.40: 距下 9.50
Ø6.40: 距右 6.02
Ø3.20: 距上 60.00
Ø8.50: 距上 8.00

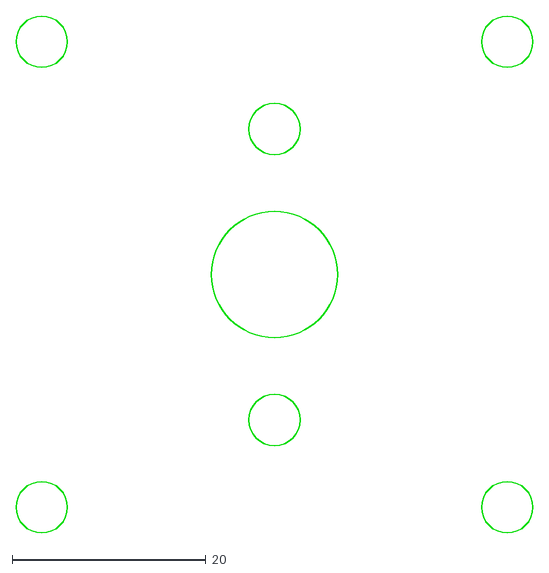
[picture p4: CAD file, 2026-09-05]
基準檔/開孔/AS&VS.dxf
53.3 x 53.3

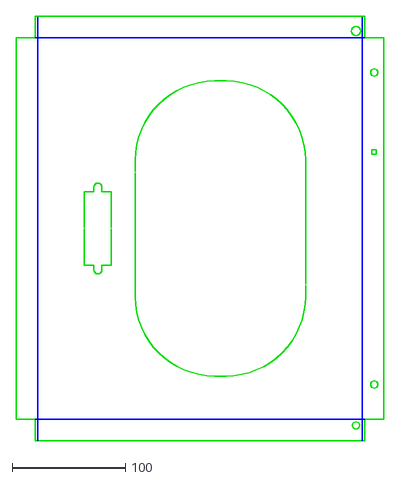
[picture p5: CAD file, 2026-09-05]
基準檔/指示燈/小門 - 複製.dxf
324.0 x 374.0

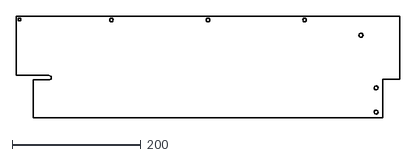
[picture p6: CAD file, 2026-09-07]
基準檔/金庫型/中隔.dxf
596.0 x 158.0

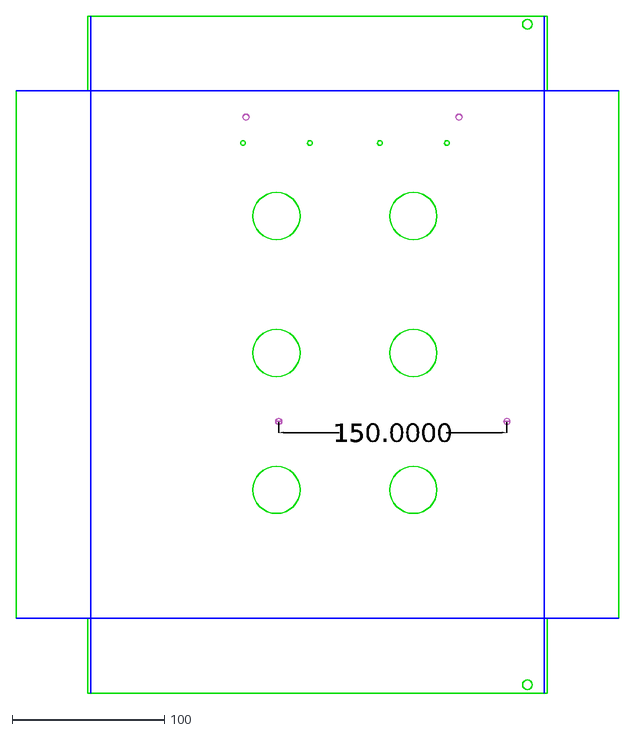
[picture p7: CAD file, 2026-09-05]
基準檔/指示燈/123.dxf
150.0000

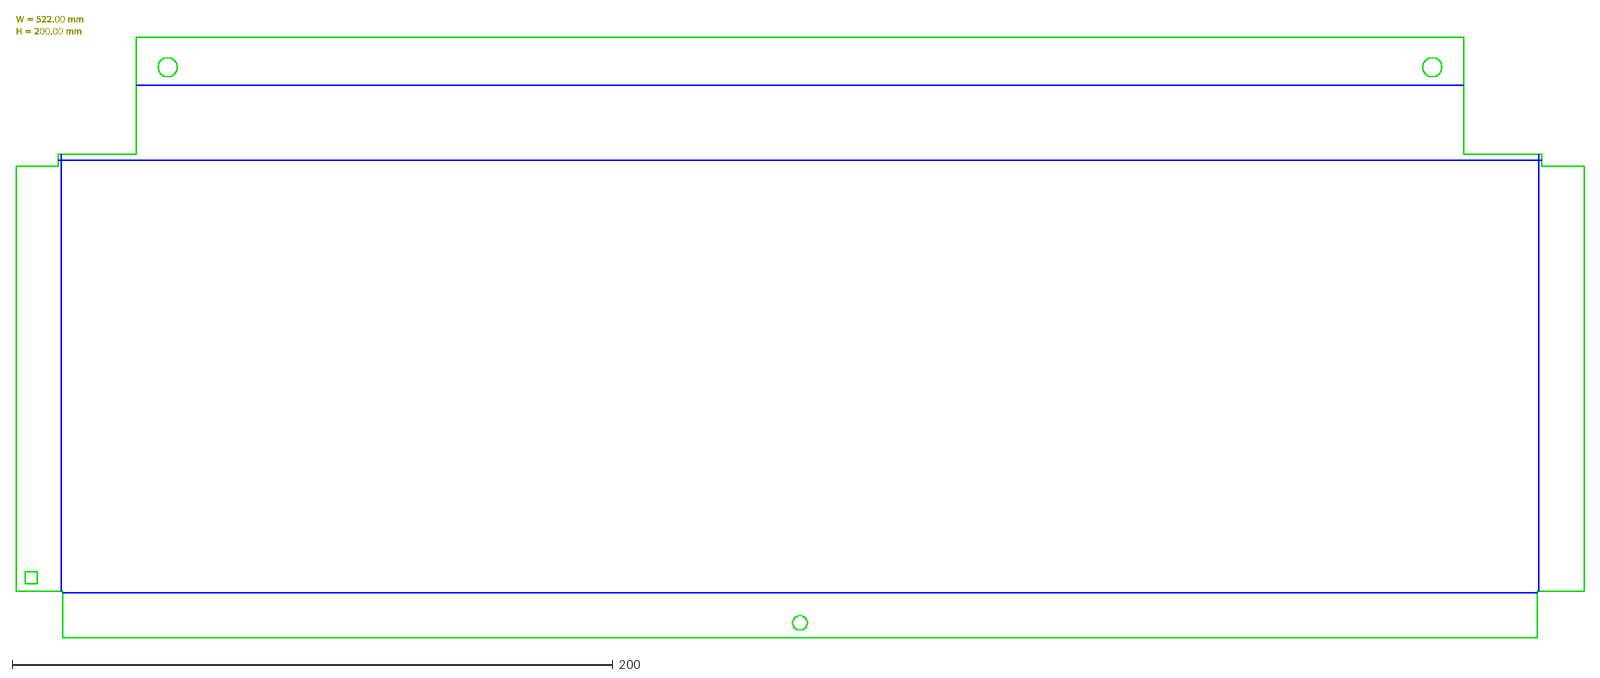
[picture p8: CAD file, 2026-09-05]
基準檔/金庫型/封頭尾.dxf
W = 522.00 mm
H = 200.00 mm

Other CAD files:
基準檔/金庫型/箱身.dxf

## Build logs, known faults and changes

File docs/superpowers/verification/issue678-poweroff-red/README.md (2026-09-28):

---
whd_doc_role: HISTORICAL
whd_contract: verification-provenance
whd_canonical: null
whd_schema: WHD_DOC_META_V1
---
# Issue #678 — Power-Off Requirement RED Durable Anchor

Status: repository-owned evidence candidate for WI-0.

Baseline authority:
`cleanup/2d-3d-sync @ 87eb35b3f5ae5211673c941cb56c4c4343fa5405`

This directory preserves the exact approved local probe sources/raw outputs/manifests from the
human-approved RED gate and adds a portable reproduction wrapper.

Approved surface:
- v4 gap characterization: R0, R0A, R1, R2, R7, R8, R9, R11.
- v5 behavioral coverage: 28 nodeids covering T3=5, T4=6, T5=3, T6=8, T10=6.
- Adversarial sentinels: always-SAFE and always-NOT-SAFE.

The files under `approved/` are preserved evidence bytes. Their original hashes are recorded in
`provenance.json`.

Portable replay:

```bash
python docs/superpowers/verification/issue678-poweroff-red/reproduce.py
```

Optional explicit repository root:

```bash
python docs/superpowers/verification/issue678-poweroff-red/reproduce.py --repo-root /path/to/whd
```

`reproduce.py` runs only against the immutable baseline SHA embedded in the approved probes. It
copies the preserved probes into a temporary directory, patches only machine-local path bindings,
runs the v4/v5 matrix runners, and exits non-zero unless all intended RED and adversarial failures
are reproduced. It performs no production mutation.

WI-0 changes evidence only; it must not change WHD production behavior.

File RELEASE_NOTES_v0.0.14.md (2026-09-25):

---
whd_doc_role: REFERENCE
whd_contract: project-reference
whd_canonical: null
whd_schema: WHD_DOC_META_V1
---
# WHD 板金展開自動化系統 Release Notes (v0.0.14)

**發布日期**：2026-08-11
**版本號**：`v0.0.14`
**Git 標籤**：`v0.0.14`
**分支**：`new-engine`

---

## 🌟 核心更新重點 (Highlights)

### 1. 幾何引擎與拓撲拆分 (`sheetmetal_geometry.py`)
- **全面淘汰硬編碼 12/16/17 點主外框**：轉為 Shapely 2D Polygon 布林運算（Base Polygon − Relief Polygon = Material CUTTING）。
- **Topology 與 Factory Policy 徹底分離**：
  - `FourSideFlange` 通用四折邊拓撲：適用於 Door、Indicator Box、Base Plate、End Cap / Tail。
  - `StripFoldChain` 單向連續折彎拓撲：適用於 Box Body。
  - 金庫型封頭尾裝配退讓（Assembly Insertion Relief）收斂為專用 Factory Policy，不污染宇宙通則。
- **幾何成為唯一真相來源**：GUI 預覽與 DXF 匯出統一存取同份 Geometry Result。

---

### 2. GUI 結構預覽與畫布繪圖重構 (`sheetmetal_drawing.py`, `gui.py`)
- **DrawingScene 繪圖語意層**：建構 `DrawingScene` 與 `SceneData`，將 `CUTTING`、`BEND`、`CHECK`、`STOCK`、`DATUM` 幾何圖元統一封裝。
- **完全同步**：畫布看到的 2D 展開形狀與最終輸出的 DXF 檔案 100% 精確對齊。
- **支援全螢幕模式**：新增 `F11` 鍵與 ToolBar 按鈕無縫切換原生全螢幕/視窗還原。

---

### 3. 統一開孔編輯器與圖冊升級 (`hole_catalog.py`, `sheetmetal_features.py`)
- **跨 7 大零件統一編輯器**：Box Body、Door、Base Plate、Indicator Box、Indicator Door、Head、Tail 統一採用此編輯器介面。
- **雙目錄載入**：同時支援 `一般開孔`（`開孔.csv`）與 `管孔清單`（`管孔尺寸清單.csv`，自動解析 `Ø` 圓形規格）。
- **九宮格參考基準點 (Crosshair Anchor)**：
  - 支援 `中心`、`中上`、`中下`、`中左`、`中右`、`左上`、`左下`、`右上`、`右下` 九位基準。
  - 右鍵選單精確定位，懸浮面板緊隨游標避讓外框。
- **成品邊界參考 (Finished Boundary)**：
  - 外框測量顯示真實成型/裝配尺寸（非純展開折彎線距），直覺提供工程師依據裝配邊界定位孔位。
- **圓孔陣列與對齊工具 (Round Hole Pattern)**：
  - 提供 6 方向延伸、`孔心距` 與 `間距` 動態雙向同步。
  - 支援多孔時 `孔心齊`、`管頂齊`、`管底齊` 等快速對齊功能。
- **復原與撤銷 (Undo/Redo)**：
  - 內建 `EditorUndoHistory` 支援最多 50 步撤銷 (`Ctrl+Z` / `↶ 回上一步`)。

---

### 4. 專案工程化與測試套件 (`tests/`)
- **測試架構遷移**：所有 `test_*.py` 單元測試檔收合至 `tests/` 目錄並建立 `conftest.py`。
- **測試全數通過**：全套 211 項測試通過驗證（`211 passed in 2.29s`）。
- **正式建立自動發布腳本**：新增 `deploy_release.bat`，內建單元測試自動驗證與發布。

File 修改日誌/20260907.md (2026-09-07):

# 2026-09-07

## Receiving Door FW semantic correction

- Root cause: Receiving `FW=29` is already the formed outside occupation, but the shared Door engine treated it as material FW and added `2T` again, producing a false 33 mm frame occupation at `T=2`.
- Fix: Cabinet Family policy converts Receiving Door FW from formed occupation to material space before entering shared Door geometry. Vault / 金庫型 keeps material `FW=25`, so its existing `25+2T=29` behavior is unchanged.
- Unified consumers: outer Door manufacturing/render/export, GUI legacy Door seams, Receiving inner-door derivation, and assembly placement now consume the same family-aware FW semantic.
- Correct default Receiving results:
  - upper Door 800×1100 -> finished 735×1064 -> blank 769×1098
  - lower Door 800×500 -> finished 735×435 -> blank 769×469
- TDD RED evidence: GitHub Actions run `34066578746` at `cc230fd68a568b49ff0e29fd969a4a750ea38274`: 30 passed / 3 failed / 4 skipped; all three failures were the expected old Receiving 2T double-compensation values.

- GREEN evidence: GitHub Actions run `34067119430` at `966b79f01916093978434054038844d8a431959c`: **38 passed / 7 skipped / 0 failed**.
- `config.ini` SHA256 before/after QA remained `980eab68d4a1732a5313b22329852dfc9691c83e4e2a64cccd18022afae4ee67`.
- 3D evidence artifact `9999289925` (`door_fw_3d_check.png`) was generated from authoritative outer/inner Door placement and manually inspected; inner panel is smaller and inward from the corrected outer Door plane as expected.
- One-shot QA workflow was removed after terminal GREEN; cleanup commit `a4b10dfc8191524ca00b93777c07540d35ed1412`.

## Receiving Door projection/snapshot single-source follow-up

- Root cause follow-up: Fold Designer still had two independent Door dimension calculations, and main GUI snapshot creation had a third. All accepted operator `FW=29` as if it were material FW and therefore re-created the false 33 mm frame occupation.
- RED run `34083065751`: 1 passed / 2 failed. Receiving upper/lower projections were 727×1060 and 727×427 instead of 735×1064 and 735×435; Vault guard passed.
- Fix: `fold_designer_bridge.py` and `gui.py` now resolve family-aware material FW and call the shared Door finished-size resolver rather than hand-writing `FW+2T`.
- GREEN run `34083409925` at `38dd8a4b2d76df82d7e7830503be53beaae506e0`: focused projection 3 passed; T25 Combined Acceptance 1 passed.
- `config.ini` before/after: `980eab68d4a1732a5313b22329852dfc9691c83e4e2a64cccd18022afae4ee67`.
- Production scan found no remaining caller-level Door `fw+2T` formula in `gui.py` or `fold_designer_bridge.py`; the remaining `frame_span = fw + 2T` is the generic material-space engine contract.

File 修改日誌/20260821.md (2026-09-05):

# 2026-08-21 修改日誌

## 截角類型／裝配語意整合

本次不是單純改 GUI 名稱，而是把截角類型提升成製造與裝配尺寸鏈的唯一來源。

### 幾何引擎

- 新增正式截角類型：十字截角、貼外型、嵌入型、嵌入貼外型。
- 十字截角支援標準／單邊留肉／多切與方向、`xT` 參數。
- 貼外型固定高方向留肉。
- 嵌入型固定高方向多切，預設 `1T`。
- 嵌入貼外固定二級截角：貼外留肉＋嵌入留肉＋深度。
- **修正先前誤判：** `C04`／嵌入貼外的實際二級 CUTTING 必須維持 `側折 + 0.5T`；先前把二級位置誤算成 `39mm` 的版本已撤銷。UI 仍顯示「嵌入留肉 0.5T」，兩級之間剩餘材料由程式推導。
- `C01~C04` 僅保留相容讀取，進入引擎後轉換成新的製造語意。

### 箱身裝配尺寸鏈

- 箱身高度不再永久寫死 `H-2T`。
- 封頭／封尾有貼外關係時各佔 `1T`；純嵌入佔 `0T`。
- 因此支援 `H-2T / H-T / H`。
- 箱身孔位、固定特徵與面特徵的 Y 基準同步使用相同封頭／封尾偏移。

### 資料契約與製造 API

- `BoxBodyPartSpec` 新增內部欄位 `head_corner_policy` / `tail_corner_policy`。
- 製造 API 與 AE exporter／場景建立器全程傳遞同一份 policy，不另外重算裝配狀態。

### GUI／3D 折彎設計器

- 新操作流程移除 `C01~C05` 與 `0°/90°` 截角 UI。
- 使用者畫面改用繁體中文製造語意名稱與參數欄位。
- 修正十字截角切到「多切」時沿用舊方向的問題：預設回到「寬＋高、0.5T」。
- 截角快照、Bridge 原始狀態、`config.ini` 來回保存全部保留參數。
- 已知固定板件以繁體中文顯示截角摘要但不可修改。
- 指示燈盒／指示燈小門維持共享固定板件，即使切到「自訂」也不可修改截角類型。
- `fold_designer_original.py` 的製造幾何／操作模型維持原版；因新增全域字級，僅加入文字倍率。

### 繁體中文規則

- 使用者可見介面一律使用繁體中文。
- Superpowers 規格、實作計畫、驗證紀錄、交付說明與修改日誌使用繁體中文。
- Python 類別、函式、enum、欄位名稱與舊相容代碼屬程式內部識別字，為避免破壞 API 保留英文；文件會附上繁體中文製造意義。
- 新增 `tests/test_traditional_chinese_handoff.py`，防止新截角 UI 與接手文件再退回英文操作名稱。

### 測試

- `tests/test_corner_semantics.py`
- `tests/test_corner_ui_integration.py`
- `tests/test_traditional_chinese_handoff.py`

完整設計與執行紀錄見：

- `docs/superpowers/specs/2026-08-21-corner-type-semantic-assembly-design.md`
- `docs/superpowers/plans/2026-08-21-corner-type-semantic-assembly-implementation.md`
- `docs/superpowers/verification/2026-08-21-corner-type-semantic-assembly-verification.md`

### 封頭尾截角修正

- `FW=25、T=2、側折=15、嵌入留肉=0.5T` 時，正確二級 CUTTING 為 `16mm`，深度 `4mm`。
- 新增回歸測試，禁止文件與測試重新把 `39mm` 當正確答案。

### 全域文字大小

- 新增 **文字大小：小 / 中 / 大**。
- 小為現有字級 `1.0×`，中 `1.2×`，大 `1.4×`。
- 主 GUI 與 3D 折彎設計器皆可選擇，切換後即時套用。
- Tk/ttk/Canvas/Matplotlib 文字共用同一倍率；CAD/DXF 幾何不縮放。
- 選擇保存於 `config.ini` 的 `[UI] text_size`，下次啟動沿用。
- 新增 `ui_text_scale.py` 作為 GUI 文字縮放單一責任模組。

### 自訂模式（原未知類型）

- 使用者可見名稱由「未知類型」改為 **「自訂」**。
- 舊資料／舊字串 `未知類型` 保留相容讀取，自動視為「自訂」。
- 修正原本切入手動模式會使用另一份預設截角狀態的問題。
- 現在從已知型號切到「自訂」時，尺寸、折彎、使用者孔位資料保持原狀，只把目前固定截角規則複製成可編輯狀態。
- 金庫型封頭／封尾複製後：上方嵌入貼外、下方十字多切 `0.5T`，因此箱身高度鏈不再因上方十字預設而拋出 GeometryError。
- 3D 折彎設計器使用相同繼承規則，不再恢復舊自訂截角草稿。

## 截角類型回退防護
- 修正後續 FIX13 四檔 overlay 將 semantic CornerType 降回 C01~C04 UI 的問題。
- 恢復已知→自訂時封頭尾固定截角繼承，避免封頭尾退回 CROSS/STANDARD。
- 恢復 BoxBody `head_corner_policy` / `tail_corner_policy` 資料鏈。
- 新增 `tests/test_corner_semantic_overlay_guard.py` 與 baseline resolver guard，實際驗證封頭 DXF 二級截角。

## 3D 首頁與指示燈盒狀態防護
- 指示燈盒／小門尺寸只在實際 `indicator_box` 模式顯示；未使用或直接指示燈模式顯示 `-`。
- 多門結果只跟目前選取 cell 的模式與 `layer_groups`。
- 盒體／小門 export 預設關閉，實際輸出再次檢查是否真的存在指示燈盒。
- 零件存在狀態與 export checkbox 分離；有盒子但未勾輸出時，3D 仍保留盒體／小門。
- 3D 板件列新增永久「首頁」，板件可回全域首頁而不等於確定／取消。
- 「進階設定」恢復為板件製造參數；RELIEF／舊 NOTCH 改列「截角底層相容參數」。
- 新增 `tests/test_phase6_ui_state_regressions.py`，包含實際 Tk smoke。

## 3D 視圖與截角來源整理

- 3D 首頁移除 RELIEF／舊 NOTCH 可編輯相容面板，避免和每角 CornerType 形成兩套截角參數來源。
- 下方舊 CAD 展開標註圖不再顯示，3D 視圖使用原本下方空間。
- 新增 3D 滑鼠滾輪縮放；只改視圖倍率，不改任何製造設定。
- 各板件設定標題列顯示真正展開尺寸；箱身寬度包含補料，高度依 CornerType 裝配語意優先計算。
- 新增 `tests/test_phase6_3d_view_regressions.py`。

## 三維真實開孔截角與視野填滿

- 三維預覽改用正式 `DrawingScene.CUTTING` 建立 material polygon，不再以完整矩形板面冒充製造輪廓。
- 圓孔、封閉 Profile 孔、指示燈孔、指示燈盒開口、盒體固定孔與小門視窗會在三維 mesh 中真正挖空。
- CornerType 截角直接使用現有製造引擎結果；三維層不另建截角公式。
- FoldChain 將同一份展開 CUTTING 分區後映射到折彎三維位置，保留實際缺料／孔洞。
- 視野由 mesh 實際 X/Y/Z bbox 各自 fit，移除舊 `max_b` 立方體限制。
- 只在 Phase6 bridge 的三維 axes 實例解除 Matplotlib `apply_aspect()` 強制正方形 viewport，避免左右大面積留白；不修改 Matplotlib 全域行為。
- 直接指示燈與指示燈盒模式所產生的 Door CUTTING 也帶入三維預覽。
- 新增 `tests/test_phase6_3d_cutting_mesh.py` 防止真洞、截角、折彎映射、非 cube fit 與寬 viewport 回歸。

## 三維留肉與基準檔孔修正

- 修正 `CROSS / 留肉` 小段材料在三維被 X/Y 兩個折彎同時帶走的錯誤。
- 留肉方向「寬」只跟上／下板面；留肉方向「高」只跟左／右板面，三維 mesh 以 fold-exemption region 決定折面歸屬。
- 三維 material 新增目前選定型號基準檔 secondary `CUTTING` 孔，基準孔不再只出現在二維預覽。
- 基準 `CIRCLE`、封閉輪廓與炸開 LINE 迴路都可成為三維真洞。
- 排除 stretched baseline scene 中重複的結構外框，避免誤判成超大孔。
- 新增 `tests/test_phase6_3d_retain_and_baseline.py`。

## 3D 基準孔定位與打標製程修正

- 修正門板基準 Ø13 MARKING 圓被誤當 CUTTING 真孔。
- 明確 operation layer 優先於 color；211 僅保留舊檔 fallback。
- MARKING / BLIND_HOLE 不再進 3D material subtraction，改為折後表面線條。
- 基準 secondary geometry 依目前 BEND anchors 重定位，孔徑/輪廓尺寸不縮放。
- 門板 blank bounds 不再被板外 MARKING 污染。
- 封頭 3D baseline 改用方向正規化 scene。
- 新增 tests/test_phase6_baseline_operation_alignment.py。

## 3D 單一製造來源重構（取代前述 3D 二次開孔／baseline 解析方案）

- 確認前一版架構錯誤：Phase6 3D 曾重新解析 baseline、重判孔、重建 CornerType CUTTING，造成孔位偏移、MARKING 被挖穿、把手孔漏失與開啟延遲。
- 新增 `manufacturing_api.PartRenderData(scene, material)` 與 `build_part_render_data()`；材料面在製造邊界一次定案。
- 3D bridge 不再讀 baseline、不再判孔、不再重算截角，也不再 polygonize CUTTING 推測材料。
- 已直接刪除 `_phase6_current_cutting_scene`、`_phase6_current_baseline_cutting_scene`、`_phase6_material_with_baseline_holes`、`_phase6_align_baseline_scene_to_current`、`_phase6_retained_fold_exemptions`、`_phase6_cutting_contours_from_scene`、`_phase6_cutting_polygon_from_scene` 等第二套製造 helper。
- 3D render path 只消費 `render_data.material` 與同一份 `render_data.scene`，做 triangulate、fold 與 BEND/MARKING 投影。
- GUI 對相同 PartSpec payload 快取 render data，避免單純 redraw 重跑製造／基準載入。
- 新增 `tests/test_phase6_3d_single_source_renderer.py`，並將既有 3D 測試遷移到單一來源契約。

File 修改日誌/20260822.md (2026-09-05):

# 2026-08-22

## 3D Final Part Geometry direct render

- 移除 Phase6 3D 對 legacy Renderer 的執行與 fallback。
- 移除 3D 由 scene BEND 二次反推 fold profile 的路徑。
- 3D 直接折疊 authoritative PartRenderData.material，折向/角度使用 Fold Designer 現有 X/Y profile。
- Final geometry 失敗時顯示錯誤，不再顯示另一套舊模型。
- display mesh 採 0.05 mm topology-preserving simplify，降低高密度圓弧 triangulation 成本，不修改 authoritative material。
- 新增 3 個 regression tests。

## 封尾 native orientation / 門把 baseline / 折彎診斷存檔

- 修正 head/tail 只應共用製造尺寸，不應直接複製同一 Y profile；封尾改用 native `ybottom1 -> D core -> FW -> ytop1`。
- 標準四段的舊封尾工作區會安全遷移；含額外自訂折段時不強制重排。
- 門基準 LWPOLYLINE 不再以 `len(points) > 10` 判定舊外框；只排除真的跨整張板材 bounds 的結構輪廓。
- 門基準 `INSERT` 會展開 virtual entities，再按原 operation layer 規則映射，避免 block 內把手 CUTTING 消失。
- 3D 設定 footer 新增「存檔」，輸出 `phase6-fold-diagnostic-v1` JSON；不等同主 GUI 確定。
- JSON 保存全部 fold profiles / settings / CornerType / active payload，以及目前 Final Part Geometry scene/material。
- 新增 `tests/test_phase6_tail_native_orientation_and_save.py`。
- 完整 Xvfb pytest：109 passed。

## 3D core 主面 / 有限 BEND ownership / 操作尺寸 / `.p6fold` 專案檔

- 3D 折疊主面不再用 profile 中間索引猜測；改以 segment 的 `core` 語意選擇主面。箱身多個 core 取中央 W core，封頭/封尾均以 `endcap_d_core` 為主面。
- `PartRenderData` 新增 `fold_guides`；由 final scene 的 BEND LinePrimitive 產生有限長度 FoldGuide，包含 axis / position / span_start / span_end。
- 3D 每一道折只作用於實際 BEND 線覆蓋範圍；留肉若位於某條 BEND span 外，只略過該一道折，後續有效折彎仍正常套用。
- 使用使用者提供的封頭/封尾診斷 JSON 驗證：修正後兩者外部折疊 span 均為 392 × 244 × 25，差值為 0；原生 CUTTING/孔位差異保留。
- 3D 關閉 X/Y/Z 軸、ticks、grid、pane，改顯示操作員成品尺寸與折邊摘要；門顯示成品 335 × 535，而非引擎補償 core 331 × 531。
- 預設相機改為 W 水平、H 垂直的操作視角，避免門看起來寬高顛倒；使用者旋轉後維持其視角。
- 3D 開窗不再重新對整個主 GUI 執行 TextScaleController.apply()。
- 第一個板件預覽先完成 Tk/Matplotlib viewport resize，再進行 authoritative model render；抑制 resize 的空/舊畫面 repaint，使首次選門由 3 次 draw 降為 1 次。
- 同環境實測：上一包 open 0.2477 s / activate door 0.2056 s / draw 3；本版 open 0.1306 s / activate door 0.0742 s / draw 1。
- 新增 `phase6_project_file.py` 與 `.p6fold` 專案格式（UTF-8 JSON，schema `phase6-fold-project-v1`）。一次保存全域設定、全部現有板件、全部 X/Y profiles、CornerType、features、face features、workspace，以及每片 authoritative scene/material/fold_guides 診斷資料。
- 主 GUI 可從 `.p6fold` 還原工作區並自動開啟存檔時 active part 的 3D 工作區。
- Windows 使用 HKCU `Software\\Classes` 註冊 `.p6fold` 開啟命令，不需管理員權限；frozen EXE 使用 `"<exe>" "%1"`，script 模式使用 `"<python>" "<gui.py>" "%1"`。
- 使用使用者閉合後的門診斷 JSON 驗證 material `interior_count=7`，門把已成為 material 真孔。
- 新增 `tests/test_phase6_core_fold_ownership.py`、`tests/test_phase6_3d_operator_view.py`、`tests/test_phase6_project_file.py`。
- 完整 Xvfb pytest：124 passed。
- `fold_designer_original.py` SHA256 維持 `f30b5e790efe2b4bd91d689735ce4fd2dd8f59f276c299f71043ef8ee93cb4de`。

## 箱身 Fold Chain / 封頭尾連動 / 2D handoff / 板件刪除

- `BoxBodyPartSpec` 新增 authoritative arbitrary `fold_profile`，manufacturing box scene/BEND/material 改直接使用目前 Fold Chain；3D 中新增/刪除折段按「確定」後真正進入主 GUI 2D，不再被舊 9 段公式重建。
- `build_linked_endcap_xy_profiles()` 以 D-W-D semantic core 與外側 ordered chain 推導封頭/封尾 mating 折法；不依賴固定段數，回歸涵蓋 3/5/9/12/20 段。
- `.p6fold` 載入與 3D transaction commit 都以箱身 Fold Chain 為 source of truth，舊 head/tail profile 只作診斷/暫存，不覆蓋 derived mating topology。
- 封尾維持 native orientation；封頭/封尾 2D 與 DXF export 改由相同 Final Scene 的 BEND primitives 輸出。
- 修正自訂/無 baseline 封頭尾 structural outline 未 closed，material resolver 可能把小 CUTTING feature 認成主材料的問題。
- 已知型號箱身在 arbitrary Fold Chain 下仍保留基準固定孔/標記；基準 feature 以 face-local 座標映射到新 D/W/D 核心。
- 主 GUI 箱身結果欄與 face hit-zone 改讀 authoritative Fold Chain；使用上傳 `自訂.p6fold` 驗證 5 段箱身結果為 938.00 × 596.00 mm。
- `existing_parts` 正式控制主 GUI 2D/export presence；箱身不可刪除，其他板件可刪除/加回，2D tab 與 export flag 隨 transaction 同步。
- 刪除非 linked 板件只移除 presence，不清除 stashed local profile；重新加入可恢復原折法。
- 修正 derived 封頭/封尾重新加入後再次「確定」會套用 legacy 四鍵 Y parser 並失敗；任意 linked Y profile 現只保留 end-cap 獨立 X flange 值，Y 永遠重新由箱身 Fold Chain 推導。
- 20 段端蓋 mating span 使用總量守恆整數配額，避免逐段 round 造成 blank size 漂移。
- 新增 `tests/test_phase6_linked_fold_chain_and_parts.py`，包含使用者實際 `自訂.p6fold` 回歸。
- 最終乾淨 ZIP 解壓驗證：149 passed；上傳 `自訂.p6fold` 實檔 delete/add-back transaction smoke 通過。

## 2D/3D 共用 FinalScene / 組合方式 / FW override / 折後包外

- 新增箱體層級 assembly type：INSERT / OVERLAY / INSERT_OVERLAY；同一狀態驅動封頭/封尾上方 CornerType 與箱身 finished-height occupancy。
- 修正 FW 語意：FW 是 Frame Width，不可被 arbitrary fold allocator 合併。5 段 linked end-cap 改為 Head `16 -> FW25 -> D244 -> 15`、Tail native `15 -> D244 -> FW25 -> 16`。
- 封頭/封尾 FW 預設跟隨箱身但可各自解除連動；override 不反寫 global FW，並保存/還原於 `.p6fold`。
- 主 2D 與 Phase6 3D 共用 `_authoritative_render_data` cache；相同 PartSpec/context 返回同一 `PartRenderData`。
- DXF export 新增 `save_part_render_data_dxf()`，直接序列化既有 FinalScene，不再由 GUI 再跑 `generate_part()`。
- 3D 尺寸改量實際折後 triangles 的 outside envelope；`自訂(1).p6fold` 箱身實測 400 × 596 × 250，2D 展開仍為 938 × 596。
- 板件 selection 與 activation 分離；optional part 可選中後直接刪除/Delete，不必先進編輯頁。
- 完整工作目錄 Xvfb pytest：173 passed；實檔 smoke 驗證同一 box-body state 的 2D→3D→DXF manufacturing build 次數為 1。

## Phase6 封頭尾跟隨箱身刪折與 90 度修正
- 修正 5 段 `FW-D-W-D-FW` 箱身時，封頭/封尾仍被硬補 `ytop1` 外側折的錯誤。箱身外側折不存在時，封頭/封尾對應折現在會自動刪除。
- EndCap 2D blank 尺寸改由同一份 Fold Profile 聚合 legacy structural scalar；5 段案例由 422×300 正確縮為 422×284，BEND 由 5 條降為 4 條。
- `read_endcap_xy_profiles()` 不再要求 `ytop1` 必須存在；缺少代表 0，任意額外 mating rows 僅聚合供 legacy adapter 使用，完整 BEND 仍由 Fold Profile authoritative。
- 修正 3D payload 因缺 `ytop1` 讀取失敗而退回舊 300/5-BEND geometry 的問題；2D/3D 現在使用同一 EndCap PartSpec/FinalScene。
- `自訂(2).p6fold` 實檔：Head/ Tail 均為 422×284、4 BEND；Y 相鄰折後夾角 90° / 90°。

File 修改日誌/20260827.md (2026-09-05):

### [20:35:03] 變更紀錄
- **變更檔案**：`docs/superpowers/specs/2026-08-27-boxbody-endcap-collision-relief-design.md`, `修改日誌/20260827.md`
- **備份檔名**：`無（新增檔案）`
- **修改摘要**：新增 Box Body 與 EndCap/Tail 第一階段 3D 干涉退讓設計規格，明確定義 Box Body RETAIN、EndCap/Tail CUT、solver 所屬 module seam、驗證策略與不做事項。

### [20:36:33] 變更紀錄
- **變更檔案**：`docs/superpowers/plans/2026-08-27-boxbody-endcap-collision-relief.md`, `修改日誌/20260827.md`
- **備份檔名**：`BACKUP/20260827-203633-20260827.md`
- **修改摘要**：新增 Box Body 與 EndCap/Tail collision relief 實作計畫，拆分 contracts、relief projection、PartRenderData 套用、manufacturing_api opt-in integration、renderer ownership guard 與驗證紀錄任務。

### [20:36:33] 變更紀錄
- **變更檔案**：`docs/superpowers/plans/2026-08-27-boxbody-endcap-collision-relief.md`, `修改日誌/20260827.md`
- **備份檔名**：`BACKUP/20260827-203633-2026-08-27-boxbody-endcap-collision-relief.md`, `BACKUP/20260827-203633-20260827-plan-fix.md`
- **修改摘要**：修正實作計畫 self-review 文字，移除容易被 placeholder 掃描誤判的禁用字樣。
### [20:42:28] 變更紀錄
- **變更檔案**：`.superpowers/sdd/2026-08-27-boxbody-endcap-collision-relief/progress.md`
- **備份檔名**：`BACKUP/20260827-204217-progress.md`
- **修改摘要**：補充 SDD 執行規則，明確記錄 AGENTS 的備份與修改日誌規範優先於單一任務檔案清單。

### [20:43:55] 變更紀錄
- **變更檔案**：`tests/test_assembly_collision.py`, `ae_engine/assembly_collision.py`, `.superpowers/sdd/2026-08-27-boxbody-endcap-collision-relief/task-1-report.md`, `修改日誌/20260827.md`
- **備份檔名**：`BACKUP/20260827-204355-20260827.md`
- **修改摘要**：依 SDD Task 1 以 TDD 新增 Box Body / EndCap assembly collision contracts、預設 RETAIN/CUT ownership 與 planar intersection detection；指定測試 3 項通過，完整 suite 受既有 pytest import mismatch 阻擋。

### [20:44:52] 變更紀錄
- **變更檔案**：`.superpowers/sdd/2026-08-27-boxbody-endcap-collision-relief/task-1-report.md`, `修改日誌/20260827.md`
- **備份檔名**：`BACKUP/20260827-204440-task-1-report.md`, `BACKUP/20260827-204452-20260827.md`
- **修改摘要**：補充任務報告的 commit 嘗試結果；Git 因無法建立 `.git/index.lock` 而未產生 commit。

### [20:46:05] 變更紀錄
- **變更檔案**：`ae_engine/assembly_collision.py`, `tests/test_assembly_collision.py`, `.superpowers/sdd/2026-08-27-boxbody-endcap-collision-relief/progress.md`
- **備份檔名**：`BACKUP/20260827-204528-assembly_collision.py`, `BACKUP/20260827-204528-test_assembly_collision.py`, `BACKUP/20260827-204528-progress.md`, `BACKUP/20260827-204528-20260827.md`
- **修改摘要**：完成 Task 2 Relief Candidate Projection，新增 ownership 驅動的 EndCap relief candidate 反投影與對應測試，並更新 SDD 進度。

### [20:48:15] 變更紀錄
- **變更檔案**：`ae_engine/assembly_collision.py`, `tests/test_assembly_collision.py`, `.superpowers/sdd/2026-08-27-boxbody-endcap-collision-relief/progress.md`
- **備份檔名**：`BACKUP/20260827-204633-assembly_collision.py`, `BACKUP/20260827-204633-test_assembly_collision.py`, `BACKUP/20260827-204633-progress.md`, `BACKUP/20260827-204633-20260827.md`
- **修改摘要**：完成 Task 3 Relief Candidate 套用流程，將 collision candidate 從 EndCap material 移除、重建主要 CUTTING polyline，保留 fold guides；並修正測試期望為真實 collision 最小切除面積。

### [20:50:10] 變更紀錄
- **變更檔案**：`ae_engine/assembly_collision.py`, `tests/test_assembly_collision.py`, `.superpowers/sdd/2026-08-27-boxbody-endcap-collision-relief/progress.md`
- **備份檔名**：`BACKUP/20260827-204747-assembly_collision.py`, `BACKUP/20260827-204747-test_assembly_collision.py`, `BACKUP/20260827-204747-progress.md`, `BACKUP/20260827-204747-20260827.md`
- **修改摘要**：完成 Task 4 端到端 BoxBody/EndCap relief solver，串接 collision detection、ownership projection、EndCap material cutting 與二次干涉驗證。

### [20:51:45] 變更紀錄
- **變更檔案**：`ae_engine/contracts.py`, `ae_engine/manufacturing_api.py`, `tests/test_assembly_collision_integration.py`, `.superpowers/sdd/2026-08-27-boxbody-endcap-collision-relief/progress.md`
- **備份檔名**：`BACKUP/20260827-204937-contracts.py`, `BACKUP/20260827-204937-manufacturing_api.py`, `BACKUP/20260827-204937-test_assembly_collision.py`, `BACKUP/20260827-204937-progress.md`, `BACKUP/20260827-204937-20260827.md`
- **修改摘要**：完成 Task 5 manufacturing API opt-in integration，新增 EndCapAssemblyReliefRequest，讓 EndCapPartSpec 可選擇以 BoxBody PartRenderData 進行 assembly relief solver，未啟用時維持既有 render data。

### [20:52:20] 變更紀錄
- **變更檔案**：`tests/test_phase6_final_scene_view_ownership.py`, `.superpowers/sdd/2026-08-27-boxbody-endcap-collision-relief/progress.md`
- **備份檔名**：`BACKUP/20260827-205132-test_phase6_final_scene_view_ownership.py`, `BACKUP/20260827-205132-progress.md`, `BACKUP/20260827-205132-20260827.md`
- **修改摘要**：完成 Task 6 renderer ownership guard，新增 final scene view 不得引用 assembly collision solver 的測試，確保 assembly relief 留在 AE/manufacturing boundary。

### [20:54:05] 變更紀錄
- **變更檔案**：`docs/superpowers/verification/2026-08-27-boxbody-endcap-collision-relief-verification.md`, `.superpowers/sdd/2026-08-27-boxbody-endcap-collision-relief/progress.md`
- **備份檔名**：`BACKUP/20260827-205301-progress.md`, `BACKUP/20260827-205301-20260827.md`
- **修改摘要**：完成 Task 7 驗證與文件化，記錄 focused verification、py_compile、focused baseline slice 通過結果，以及 broader legacy slice 的既有環境/測試失敗。

### [20:58:20] 變更紀錄
- **變更檔案**：`個人AI檔案庫/第二層_專案與SOP/04_WHD鈑金展開幾何引擎規範.md`, `個人AI檔案庫/第二層_專案與SOP/06_踩坑記錄與防錯經驗庫.md`
- **備份檔名**：`BACKUP/20260827-205756-04_WHD鈑金展開幾何引擎規範.md`, `BACKUP/20260827-205756-06_踩坑記錄與防錯經驗庫.md`, `BACKUP/20260827-205756-20260827.md`
- **修改摘要**：依個人 AI 檔案庫規則補寫 Box Body / EndCap assembly collision relief 正式規範與踩坑防錯條目，固化先由真實 Collision Region 與 ownership 反投影 2D CUTTING 的架構。

### [21:52:26] 變更紀錄
- **變更檔案**：`fold_designer_bridge.py`, `tests/test_phase6_assembly_3d_view.py`
- **備份檔名**：`BACKUP/20260827-215226-fold_designer_bridge.py`, `BACKUP/20260827-215226-test_phase6_assembly_3d_view.py`
- **修改摘要**：修正「底層已有 assembly mode 但使用者看不到組合體入口」的 UI 交付缺口。依 TDD 先新增會失敗的可見控制測試，再將 3D 顯示模式由 Menubutton 改為置頂列固定可見的 `單件 / 組合體` 兩顆按鈕，並加入目前模式 disabled 狀態與即時 preview refresh。真 Tk 驗證兩顆按鈕均 `winfo_viewable()==1`，invoke 組合體後 mode 為 `assembly`。

### [21:55:23] 變更紀錄
- **變更檔案**：`個人AI檔案庫/README.md`, `個人AI檔案庫/第二層_專案與SOP/04_WHD鈑金展開幾何引擎規範.md`, `個人AI檔案庫/第二層_專案與SOP/06_踩坑記錄與防錯經驗庫.md`, `docs/superpowers/README.md`, `docs/superpowers/verification/2026-08-27-shared-assembly-world-geometry-verification.md`
- **備份檔名**：`BACKUP/20260827-215523-README.md`, `BACKUP/20260827-215523-04_WHD鈑金展開幾何引擎規範.md`, `BACKUP/20260827-215523-06_踩坑記錄與防錯經驗庫.md`, `BACKUP/20260827-215523-20260827.md`
- **修改摘要**：同步 AI 檔案庫與 Superpowers 文件，固化 shared assembly world geometry、組合體 UI 必須直接可見、第一階段只組箱身+封頭+封尾，以及 ZIP 中文路徑不得被打成 literal `#Uxxxx` 的防錯規則。

### [21:58:00] 變更紀錄
- **變更檔案**：`BACKUP/20260819-205910-FIX13_折彎尺寸與封頭尾定義_20260818.md`, `BACKUP/20260819-205910-更新說明_FIX13_20260818.md`
- **原錯誤檔名**：`BACKUP/20260819-205910-FIX13_#U6298#U5f4e#U5c3a#U5bf8#U8207#U5c01#U982d#U5c3e#U5b9a#U7fa9_20260818.md`, `BACKUP/20260819-205910-#U66f4#U65b0#U8aaa#U660e_FIX13_20260818.md`
- **修改摘要**：依使用者「不要有亂碼」要求，將專案內僅存的兩個 literal `#Uxxxx` 舊備份檔名還原為真正繁體中文檔名；內容未改。

### [22:03:27] 變更紀錄
- **變更檔案**：`tests/test_phase6_assembly_3d_view.py`, `docs/superpowers/verification/2026-08-27-shared-assembly-world-geometry-verification.md`
- **既有備份**：`BACKUP/20260827-215226-test_phase6_assembly_3d_view.py`
- **修改摘要**：補上真 Tk 組合體可見性回歸測試，驗證 `單件` / `組合體` 兩顆按鈕均實際 viewable，且按下組合體後切成 `assembly`。另外暫時還原使用者原始 `fold_designer_bridge.py` 進行 regression RED 驗證，測試如預期因只有 `display_3d_choice_button` 而失敗；恢復修正版後 PASS。

### [22:44:01] 變更紀錄
- **變更檔案**：`fold_designer_bridge.py`, `phase6_settings_panel.py`, `tests/test_phase6_latest_layout_contract.py`, `tests/test_phase6_assembly_3d_view.py`, `個人AI檔案庫/README.md`, `個人AI檔案庫/第二層_專案與SOP/04_WHD鈑金展開幾何引擎規範.md`, `個人AI檔案庫/第二層_專案與SOP/06_踩坑記錄與防錯經驗庫.md`, `docs/superpowers/README.md`
- **備份檔名**：`BACKUP/20260827_224400-個人AI檔案庫-README.md`, `BACKUP/20260827_224400-06_踩坑記錄與防錯經驗庫.md`, `BACKUP/20260827_224400-20260827.md`，以及本輪既有 22:20 / 22:32 程式備份。
- **修改摘要**：依最新 3D Designer 版面定稿：最上列加入全螢幕；全域設定固定兩行；`組合體` 改為左側板件選擇第一項且第一次進 3D 直接顯示組合體；選實際板件自動回單件編輯；移除舊的獨立單件/組合體模式入口。同步清理 AI 庫內舊「頂部兩顆模式按鈕」規則，明確標記已廢止，避免後續 AI 回復舊版面。
## 23:00 組合體封頭／封尾方向與貼合基準修正
- `ae_engine/assembly_geometry.py` 新增 `place_endcap_against_box_body()`：保留 EndCap Fold Profile 的 local `z=0` 核心面，不再用整體 Z bbox 中心重置。
- 封頭：組合體內繞 world X 180°，核心面貼箱身實際 world bbox 上緣。
- 封尾：組合體內繞 world Y 180°，核心面貼箱身實際 world bbox 下緣。
- `ae_engine/assembly_collision.py` 與 `phase6_final_scene_view.py` 共用同一 mating transform，確保顯示與後續 collision 座標一致。
- 新增方向與貼合回歸測試，使用非對稱 mesh 防止 180° 方向測試失真。

## 23:34 組合體語意接合與板件切換修正
- `fold_designer_bridge.py`：修正 `組合體 -> 箱身` 真實 Menu 路徑。assembly mode 可保留 `box_body` 作幾何 backing，但 `activate_part()` 先保存 `was_assembly`；只要是 assembly -> single，即使 active part 已同 key 也不得 early-return，必須恢復 Fold Editor/板件設定。
- `ae_engine/assembly_geometry.py`：23:34 曾改成 Tail local Y 反向，但 23:42 實機確認這會與 Tail native Fold Profile 形成二次鏡射。最新規則為 Tail local X / local Y 都保持，local `z=0` 留肉/core 貼 box-body 下緣，local `+z` 折邊往 world-Y 上方插入箱身；Head 維持 `z=0` 貼上緣、`+z` 往下插箱。
- 組合類型語意：`INSERT / INSERT_OVERLAY` 由既有 resolver 產生 folded X（`yl1/endcap_w_core/yr1`）；`OVERLAY` 產生 `endcap_w_flat`，assembly transform 不建立第二份組合類型公式，只消費 authoritative Fold Profile。
- TDD：先確認 Tail 舊方向與真 Tk Menu 切換測試皆 RED，再修 production。新增真 profile 回歸，逐一驗證 `INSERT / OVERLAY / INSERT_OVERLAY` 的留肉/core 接合平面與折邊 inward。
- 備份：`BACKUP/20260827_233033-*`（程式/測試）與 `BACKUP/20260827_233406-*`（AI/Superpowers/日誌）。
## 23:42 組合體封尾上下方向修正
- 根因：Tail Fold Profile 與 AE final scene 本來就是 native orientation；共享 assembly transform 又額外把 local Y 反向，形成二次鏡射，導致組合體封尾上下顛倒。
- 修正：Tail assembly 保留 local X / local Y；僅把 local `z=0` 接合平面貼箱身下緣，local `+z` 映射為 world-Y 向上，使折邊繼續插入箱身內。
- 不影響：封頭方向、單件 2D/3D、DXF、CornerType/Fold Profile Source of Truth。
- 回歸：新增非對稱 Tail 測件，鎖住「native 上下不二次鏡射」行為。

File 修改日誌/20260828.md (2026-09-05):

# 2026-08-28 修改日誌

## EndCap 組合體 3D 實體板成型
- 使用者指出標準金庫型封頭／封尾看起來不是「少折」，而是成型外側板面沒有出來，折邊像由箱內往外插。
- 根因：EndCap assembly 只使用 `folded_mesh_from_polygon()` 的零厚度 mid-surface，`T` 未進入 3D 成型；舊 placement 直接把 z=0 中心面當 mating face。
- 新增 `ae_engine.assembly_geometry.thicken_triangle_surface()`：由折後 mid-surface 建立 ±T/2 內外 skin、材料外周側壁與非共面 fold-edge bridge。
- `place_endcap_against_box_body()` 新增 `sheet_thickness`：Head 中心面向上外移 T/2、Tail 向下外移 T/2，使內側 skin 貼箱身、外側成型面位於箱外，折邊仍朝箱內。
- `phase6_final_scene_view.py` 組合體 Head/Tail 改渲染 physical sheet solid。
- `ae_engine/assembly_collision.py` shared world mesh API 同步支援 physical EndCap sheet，避免 viewer/collision 分叉。
- 標準金庫型 Fold Profile、5 道 BEND、2D、DXF 均不改。
- AI 庫與 Superpowers verification 同步更新。

## EndCap 組合體孔／折彎稜線可視化回歸修正
- 使用者回報 physical-sheet 版本中封頭／封尾孔消失，留肉那條折彎線與上面第一折也看不到。
- 調查確認：標準金庫型 `PartRenderData.material` 仍含 baseline 孔；Head/Tail Fold Profile 仍完整 X 2 + Y 3 = 5 道 BEND；folded mid-surface 亦存在 `ytop1` 第一折 crease。
- 根因為 physical thickening 後 viewer 只畫 closed-solid open boundary。封閉 solid 的孔 tunnel 與折彎 crease 都不是 open boundary，因此視覺消失。
- `phase6_final_scene_view.py` 新增 folded mid-surface edge extraction：保留外輪廓／through-hole 邊界，並以相鄰面法向判斷非共面 formed crease；排除共面 triangulation diagonal。
- Assembly Head/Tail 維持 physical solid 主面，額外疊加 folded mid-surface 的真實特徵線；不改 Fold Profile、CUTTING、CornerType、2D、DXF 或 assembly placement。
- 新增永久回歸：physical EndCap 加厚後孔輪廓仍可見；第一折必須有跨板面的真實 crease，不得只剩板厚側邊。

## 06:49 封頭尾組合體孔口外皮化＋3D 折彎線實線
- 根因：前版 hole/crease overlay 畫在 folded mid-surface；EndCap 加厚後中心面會被 ±T/2 skin 遮住，貼箱身時孔後方又是 BoxBody，造成「孔仍看不到」。
- `phase6_final_scene_view.py` 新增 physical solid feature-edge extraction，從 thickened EndCap 真實非共面稜線顯示 outer/inner hole rim、外周與折彎/miter edge。
- 保留 folded mid-surface crease overlay 作 fallback，但不再作為孔口唯一顯示來源。
- 3D BEND guide 由虛線 `--` 改為固定實線 `-`，linewidth 1.15。
- 不改 CUTTING、Fold Profile、CornerType、Head/Tail assembly transform、2D/DXF。

## 07:07 組合體參數解鎖＋固定截角忽略＋干涉交線診斷
- 修正組合體模式下參數鎖 state 有切換、右側卻被 `assembly_selected` guard 強制隱藏的問題。
- 組合體解鎖後顯示獨立「組合體診斷」，預設勾選 `診斷時忽略固定截角`、`顯示干涉碰撞區`。
- 診斷忽略固定截角只補回 Head/Tail exterior relief，保留 material hole interiors；正式 CUTTING / DXF / CornerType 不動。
- `ae_engine/assembly_geometry.py` 新增純幾何 world-mesh 非共面穿越診斷；共面貼合與單點接觸不標紅。
- 3D 只畫實際 intersection segments 的紅色粗實線，不再整個 coarse triangle 染紅。
- 修正 ownership：FinalSceneView 不直接依賴 `assembly_collision` solver；assembly_collision 僅相容性 re-export shared geometry helper。
- 標準金庫型真 GUI 驗證：947 段干涉交線；單次重算約 0.9 秒。

## 08:00 固定截角干涉診斷收斂為 relief-delta 局部碰撞區
- AI 自行檢查 07:10 版實際組合體畫面後，判定「947 段干涉交線」不合格：紅線沿正常長接縫與插入位置擴散，不是真正局部截角碰撞。
- 根因不是 renderer 顏色，而是碰撞 probe 錯把整片補回後 EndCap 拿去與 BoxBody 做 surface crossing，正常 mating seam 也會被計為相交。
- 新增 `restored_endcap_relief_delta()`：固定截角診斷只取 `restored material - production material`，只折起／加厚這一小塊補回材料後與 BoxBody 求 world-space 穿越。
- 標準金庫型結果由 947 段整圈假紅收斂為 454 段局部交線（Head 227 + Tail 227），166 個命中 delta triangles；AI 已自行檢查 Head/Tail 視角，紅區只在固定截角角落。
- 視覺改為「命中的 relief-delta triangle 半透明紅面 + intersection segment 紅色粗實線」，因 target 已局部化，不會再把整片 EndCap 染紅。
- 關閉 `診斷時忽略固定截角` 時不再退回整片 production EndCap 做碰撞，右側提示先啟用固定截角診斷。
- 此診斷仍不修改正式 CUTTING / DXF / CornerType。

## 13:04 3D 干涉反投影 → 正式 2D 截角尺寸閉環
- 在 `assembly_geometry.py` 的 folded triangle 上保留 flat UV，physical ±T/2 skin 仍保留同一 UV mapping。
- `assembly_collision.py` 新增 world crossing → barycentric flat backprojection、角落 topology-band cut、迭代 refold verification、A clearance 與正式尺寸解析。
- 修正局部 relief probe 曾用自身 bbox 重新置中的問題：局部材料必須沿用完整 EndCap formed reference transform。
- 標準 W500/H600/D200/T2/FW24：A0 Head/Tail = `39×38 + 14×4`；舊固定第二級 `16×4` 實際多切 2 mm。A5 = `44×43 + 19×4`，回折零材料穿透。
- 真主 GUI 目前預設標準金庫型自動求得 Head/Tail = `40×39 + 14×4`，右側顯示 `3D驗證：封頭✓ 封尾✓（零材料穿透）`。
- `EndCapPartSpec` 新增 verified dynamic cut contract；主 GUI commit 後 2D/3D/DXF 由 Manufacturing API 套同一 cut。來源 W/H/D/T、組合方式或 Fold Profile 改變即自動失效。
- 新 CUTTING 後 authoritative BEND 重新依 material clip：標準測件左 X BEND start `42→38`、FW BEND left `16→14`，恢復新留肉，不沿用舊固定截角截短線。
- 修正數值穩定性：近似鏡像 cut 在嚴格 Hausdorff 容差內取 canonical union；A 改為正交軸向精確擴張，消除 `3.992 / 18.997` 類 tessellation/buffer 噪音。

## 19:00 組合體 AssemblySceneRenderData UPDATE 介面同步修正
- 使用者實機回報：組合體第一次進 3D 顯示 `AssemblySceneRenderData.__init__() got an unexpected keyword argument 'show_interference'`，3D 畫布完全無法建立。
- 已以 `065113 FULL + 130705 UPDATE` 重建同一混版狀態，主 GUI 可穩定重現完全相同錯誤。
- 根因：130705 UPDATE 更新了 `fold_designer_bridge.py`，開始傳入 `show_interference / ignore_fixed_corner_relief`，但 UPDATE 沒有同步包含介面擁有者 `phase6_final_scene_view.py`；從較舊 FULL 疊更新時會形成「新 caller + 舊 dataclass constructor」。
- `fold_designer_bridge.py` 新增 `_phase6_make_assembly_scene_render_data()`，依 live constructor signature 只傳支援的 optional fields；混版安裝不再因 unexpected keyword 直接炸掉。
- 新 UPDATE 強制包含最新 `phase6_final_scene_view.py`，不再假設使用者一定從指定中間 FULL 逐版更新。
- 新增 backward-compat regression，模擬 legacy `AssemblySceneRenderData(assembly_parts, warnings=())` 仍可建立組合體 bundle。
- 真主 GUI 混版實測：修正前 `cutting_mesh_error = unexpected keyword...`；修正後 `cutting_mesh_error = None`、`part=組合體`、`mode=assembly`、組合 mesh 1438 triangles。

## 20:11 Dynamic relief 未求解角落誤補角片修正
- 使用者回報組合體封頭／封尾非接合側兩角多出實體片。
- 直接量測 `200245 FULL` 標準金庫型：Head/Tail solved material 各比 original 多 `528 mm²`；其中兩個錯誤角片各 `16×16=256 mm²`，另外兩個 `2×4` 為 3D solver 正確保留的材料。
- 根因：3D solver 最終直接採 `restored blank - dynamic cut`，把為探測而補回的四角全部當成 production material；但實際只重算其中兩個 mating corners。
- 修正：production solved material 改從 original EndCap material 出發，只 union 回本輪有 `raw_cut` 的 corner delta，再 subtract verified cut；未求解 legacy corners 維持原 CUTTING。
- 新增 regression：Head/Tail A=0 最終新增材料只允許總計 `16 mm²`，不得再出現對側 `16×16` tabs。

## 組合體箱身折彎線實線顯示修正
- 使用者回報：組合體中的箱身折彎線沒有像封頭／封尾一樣以實線顯示。
- 根因：assembly renderer 對 Box Body 只畫 folded mesh 外框，沒有將 authoritative `scene.BEND` 疊入組合 world-space。
- `ae_engine/assembly_geometry.py` 新增 `place_assembly_points()`，與 `place_assembly_triangles()` 共用完全相同的 reference-mesh placement。
- `phase6_final_scene_view.py` 新增 Box Body assembly BEND overlay：BEND 端點依 Fold Profile 折後，以完整箱身 local mesh 為 reference 放入 world-space，固定藍色實線。
- 真主 GUI 標準金庫型自檢：第一次進組合體時 `part=組合體`、`mode=assembly`，Box Body 可見 8 條 `#2563eb` 實線 BEND。
- focused regression：59 passed。

## 參數解鎖右側面板實際可見性修正
- 使用者回報 `參數鎖定` 仍無法打開。真 Tk `parameter_lock_button.invoke()` 調查確認：state 會切成 unlocked，diagnostics/settings 也被 pack，但因 3D canvas 先 `fill=BOTH, expand=True`，後 pack 的 panel 實際只有 1×1，肉眼等同沒反應。
- 新增 `_phase6_pack_right_panel_above_canvas()`，右側 diagnostics/settings 一律以 `pack(before=canvas)` 插到 3D canvas 前方。
- 修正 assembly -> box_body 解鎖切換時同樣使用共用 helper。
- 永久回歸改驗真按鈕 `invoke()`、`winfo_viewable()==1`、`winfo_height()>1`，不再只驗 `winfo_manager()==pack`。
- 驗證過程另抓到一處 helper 名稱 typo，已在回歸中修正；不使用截圖/mainloop 作驗收，避免 Tk/Matplotlib 在 headless 環境阻塞。

## 21:34 2D / 3D Live Canonical 同步＋Head/Tail 原子截角提交
- 依使用者決策移除 3D Fold Designer 頂列 `確定 / 取消`；不再建立 ProjectSession draft，3D production edit 即時同步主 GUI canonical state。
- 新增 `on_live_sync(payload)` 與 `_phase6_publish_live_state()`；沿用完整 transaction payload，不建立第二套欄位 mapping。W/H/D/T、基準型號、組合方式、Fold/Corner、結構、板件新增刪除、reset 都會即時 publish。
- 主 GUI 新增 `_apply_fold_designer_live_snapshot()`：一次套用 settings/corner/assembly/FW/workspace/relief，re-entrancy guard 後重建 main 2D Manufacturing state；關閉 3D 只 flush + force publish，不 rollback。
- Dynamic relief 改成 Head/Tail 原子提交：兩片都 verified 才 publish；任一失敗，兩片 3D 都重新 query canonical provider，禁止半套 solved material。
- 3D verified 後不再直接採 solver 私有 `solved_render_data`；將 verified cuts 回寫 canonical relief，再由主 2D/DXF 同一 Manufacturing provider replay。
- `apply_verified_endcap_relief_material()` 成為 solver/replay 共用 material helper，只 restore 本輪實際被 dynamic cut 取代的 legacy corner component，避免 512 mm² 角料復活。
- stale relief 加入 fingerprint 驗證／清除。使用者 `自訂(6).p6fold` 實測：當下 `INSERT_OVERLAY` 對舊 `INSERT` relief 自動失效；assembly Head/Tail material 與主 2D authoritative material symmetric difference <= 1e-6。
- 核心 live-sync / real-file / project save / assembly regression：77 passed / 0 failure。擴大 3D suite 106 passed，3 個既有紅燈與未修改 204426 FULL 相同；Manufacturing/Corner 舊批 58 passed + 18 個既有紅燈，未修改 204426 同樣 18 個。

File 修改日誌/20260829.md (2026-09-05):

# 2026-08-29 修改日誌

## 組合圖 Joint 診斷雜訊與 UPDATE 漏包修正（更正版）

### 根因
1. WRAP / Joint Registry 完成版把開發診斷資料直接接進正式組合圖，新增了 Joint selector、Registry 長狀態字串與診斷 overlay。
2. `金庫型.p6fold` 的 4 筆 `LEGACY_MIGRATED` Joint 是內部組合語意，不是板件，也不應成為操作員圖層。
3. 前一個 21:11 UPDATE 又錯用「上一版 FULL」做窄差異，只帶本輪少量檔案；若套在使用者既定基準上，就會缺少前面累積功能／依賴。
4. Door / Base Plate 單板若被強制拖進整櫃 assembly solve，會破壞單板 3D canonical FinalScene gate；因此此真值鏈修正保留，但與 Joint 畫面雜訊分開驗證。

### 更正修正
- 正式組合圖不傳 `joint_diagnostics` / `selected_joint_id`，Joint/WRAP 診斷仍留在 canonical resolved geometry。
- 移除本輪新加的正式操作畫面 Joint debug selector 與 debug status suffix，恢復到新增 Joint debug 前的操作 layout。
- `_phase6_query_final_render_data()`：箱身／封頭尾／USER_ADDED Joint 參與板件走 resolved assembly；Door / Base Plate 等獨立板件直接讀自身 canonical manufacturing FinalScene。撤回此修正會讓單板 3D gate 重現既有失敗，因此列為正式回歸修正。
- UPDATE 改為相對唯一累積基準 `PHASE6_FW_LINK_BUGFIX_FULL_20260823_212355(3).zip` 收集全部差異。
- `個人AI檔案庫/**` 每次 UPDATE 強制全收，即使未變；`config.ini` 永遠禁止進 UPDATE；`BACKUP/**` 與快取不進 UPDATE。
- 新增 `.agents/skills/engineering/phase6-release-packaging/SKILL.md` 與 machine-readable release policy，讓出包器自動 enforce，不再靠手工記憶。

### 防退化
- `test_public_assembly_adapter_keeps_joint_diagnostics_out_of_operator_scene`：正式組合 bundle 不得帶 Joint debug layer。
- `test_operator_assembly_diagnostics_does_not_expose_joint_debug_selector`：正式操作 layout 不得再長出本輪新加的 Joint selector。
- `test_phase6_release_packaging_policy.py`：鎖住累積基準、AI 全樹、禁止 `config.ini`。

## EndCap/Tail 單級 INSERT 上方截角 38×27 校正

### 使用者回報
- 同一封頭／封尾：單板 3D 顯示 `40×27`，組合圖／2D 顯示約 `39×27`；使用者確認正確製造尺寸是 `38×27`。

### 根因
1. 單板 3D 某些路徑會因 canonical relief source 驗證失效而退回 legacy fixed relief，形成 `40×27`。
2. backprojection solver 將 ±T/2 physical skins 的正常 mating contact 帶納入 crossing envelope，取到外側約 `38.98`，形成 `39×27`。
3. 真實折後 mating boundary 投回 EndCap flat UV 為 `38.00`；contact 不是 penetration。

### 程式修正
- `ae_engine/assembly_collision.py`
  - 單級 `INSERT` 維持單級 topology；迭代只收斂 primary 尺寸。
  - 排除正常 skin contact band，以實際 mating boundary 取得 relief。
  - 不對 `INSERT_OVERLAY` 等真正二級 topology 套單級規則。
- `fold_designer_bridge.py` / `gui.py` / `phase6_final_scene_view.py`
  - 延續上一輪 canonical 2D/3D/assembly 尺寸同步與板件 visibility UI。
  - 單板 3D、組合圖、2D 尺寸均消費 authoritative final material。
- 測試新增／更新：
  - `tests/test_assembly_collision_integration.py`
  - `tests/test_phase6_assembly_3d_view.py`
  - `tests/test_phase6_corner_dimension_controls.py`
  - `tests/test_phase6_latest_layout_contract.py`
  - `tests/test_phase6_return_2d_corner.py`

### 實檔驗證
`自訂(9).p6fold`：
- Head/Tail `verified=True`，`errors={}`。
- Head 左右角 = `38×27`；Tail 左右角 = `38×27`。
- 無 secondary stage。
- 組合診斷 = `封頭：38×27；封尾：38×27`。
- main 2D vs assembly material symmetric difference：Head `0.0`、Tail `0.0`。

### Focused regression
`46 passed / 0 failed`。

## 文件缺漏修正
上一個 `002730` 交付包雖已有程式／測試修正，但文件未跟同版更新，違反個人 AI 檔案庫的「程式修改即同步文件」規則。本輪把文件同步列為交付 completion gate，並將此失誤寫入踩坑庫，避免再犯。

## 組合碰撞顯示／OVERLAY／Registry 驗收閘門修正

### 使用者回報
- 組合圖顯示「未偵測到碰撞」，但實際 assembly solver 已經有切除結果。
- `INSERT_OVERLAY` 與 `OVERLAY` 都可遇到同類問題；不能再逐一由使用者人工試每一種組合。

### 根因
1. 組合圖的碰撞 overlay 拿「已完成 relief 的 final material」再做碰撞診斷，因此求解前真正的碰撞證據已被切掉，UI 會誤顯示 0 段。
2. `projection_has_material_penetration()` 對 inward tolerance 後已完全消失的微小薄片又 fallback 回原 material，會把純數值薄片重新判成穿透。
3. `OVERLAY` X profile 為 flat 時曾跳過 corner topology normalization，triangle-skin 交線會把合法單級角解成 `25×11.332 + 24.231×0.15` 之類假二級。
4. 對稱幾何的左右 raw crossing 可能因三角化漏採樣變成不同尺寸；不能把 tessellation 非對稱當成機械非對稱。

### 程式修正
- `fold_designer_bridge.py`
  - 組合 bundle 額外保存 `pre_solve_probe_parts`；display material 與 collision probe material 分離。
- `phase6_final_scene_view.py`
  - 組合圖紅色碰撞區改用求解前 EndCap probe，不再拿已切完的 final material 假裝重新偵測。
- `ae_engine/assembly_collision.py`
  - tolerance inward-buffer 已消失即視為 sub-tolerance sliver，不得復活原 material。
  - final refold 對 topology-normalized edge 只有同時符合「邊界帶 <= topology tolerance」且 semantic mid-surface 無 penetration 才可判為合法 contact。
  - 所有 assembly intent 都維持原合法 corner topology stage count；3D 只決定尺寸，不能憑空新增／刪除級數。
  - 若 Box Body X、EndCap X 與左右 corner component 都真正鏡像對稱，左右 collision evidence 取 canonical mirror union，消除 triangle tessellation 漏採樣；非對稱 profile 不強制對稱。

### Registry 驗收閘門
- 新增 `tests/test_phase6_assembly_intent_registry_matrix.py`：直接 parametrized `BOX_ASSEMBLY_TYPE_IDS`。
- 新增 `tests/test_phase6_assembly_registry_gui_matrix.py`：每個已註冊 assembly intent 必須自動驗證：
  - Head + Tail 都有求解前 collision evidence；
  - 求解後 `verified=True`；
  - corner topology stage count 不被 solver 改寫；
  - 對稱測件左右結果必須 mirror-equal；
  - 2D / 單板 3D / 組合圖 material 一致；
  - collision overlay 實際有紅區段；
  - Save / Reload 後 material 不變。
- 未來新增新的 `BOX_ASSEMBLY_TYPE_IDS` 項目會自動增加測試案例；沒有通過 registry gate 不得交付。

### 實檔驗證
- `自訂(9).p6fold` / INSERT：Head/Tail verified；碰撞顯示 170 段；38×27 保持；2D=single3D=assembly；reload diff=0。
- `自訂(10).p6fold` / INSERT_OVERLAY：Head/Tail verified；碰撞顯示 198 段；`40×23 + 16×4` 保持；2D=single3D=assembly；reload diff=0。
- OVERLAY 對稱 GUI 測件：Head/Tail verified；碰撞顯示 122 段；假二級已消失；左右單級尺寸一致為 `25×11.482`（此數字僅為該測件 3D regression evidence）。

### 驗證結果
- collision / backprojection / registry core：`80 passed, 2 skipped`。
- registry GUI matrix：`3 passed`（INSERT / OVERLAY / INSERT_OVERLAY）。
- shared assembly + dimension：`33 passed`。
- corner dimension controls：`7 passed`。
- return-to-2D：`1 passed`。
- 3D cutting mesh：`8 passed`。
- 3D view regressions：`5 passed`。
- 專案舊完整 tests 仍含既有 stale tests；已抽查 `test_gui_production_imports_ae_engine_not_legacy_core_modules` 與舊 corner-lock test，在 `064513` 基準包同樣失敗，未為湊綠燈而修改既有正確 UI/幾何。

### 最終封包
- FULL：`PHASE6_ASSEMBLY_COLLISION_REGISTRY_GATE_FULL_20260829_075946.zip`
- UPDATE：`PHASE6_ASSEMBLY_COLLISION_REGISTRY_GATE_UPDATE_20260829_075946.zip`
- Fresh gate：core `80 passed, 2 skipped`；dimension/3D `51 passed, 2 skipped`；return-to-2D `1 passed`；registry GUI 三種 intent 獨立 xvfb smoke 全部 PASS。
- UPDATE 僅收錄相對 `064513` 基準差異檔，且不得包含 `config.ini`。

### [07:56] 已認證截角資料庫第一階段實作
- 新增 `ae_engine/certified_relief_registry.py`，建立 CERTIFIED / PROVISIONAL_3D / CERTIFIED_FROM_3D / ENGINE_CONFLICT / FAILED 信任狀態。
- 新增首筆已認證規則 `ENDCAP_TOP_INSERT_STRUCTURAL_CONTACT_V1`。
- 規則保存公式，不保存單一輸出尺寸：`X = EndCap side fold + (effective FW - T)`、`Y = EndCap FW + INSERT amount_t*T`。
- 限定適用於已確認的 linked-FW INSERT 拓撲；仍有獨立 `ytop1` row 的拓撲不套用本公式，避免把 38×27 錯套到未認證幾何。
- `solve_world_backprojected_endcap_relief()` 新增 `assembly_intent`，先查 CERTIFIED registry；命中後 3D 只做 shadow validation，不得覆蓋公式結果。
- `fold_designer_bridge.py` 已把目前組合方式傳入 solver。
- 新增 `tests/test_certified_relief_registry.py`，並通過相關 user8/user10/registry 回歸。

## [12:50+] 已認證截角資料庫完整化

### 架構完成
- `ae_engine/certified_relief_registry.py` 升級為正式 Certified Relief Registry owner。
- 金庫型固定 EndCap / Door / Indicator Box / Indicator Door / Base Plate 皆由 family-aware registry 供應。
- 受電箱固定 EndCap / Door / Indicator Box / Indicator Door / Base Plate 明列 family-specific rule，禁止靜默借用金庫型。
- Assembly Intent active formulas：
  - `ENDCAP_TOP_INSERT_STRUCTURAL_CONTACT_V1`：linked-FW INSERT；`自訂(9)` 38×27 regression。
  - `ENDCAP_TOP_INSERT_STANDARD_V1`：標準 `ytop1` INSERT。
  - `ENDCAP_TOP_OVERLAY_STANDARD_V1`：flat-X 標準 OVERLAY。
  - `ENDCAP_TOP_INSERT_OVERLAY_STANDARD_V1`：標準二級 INSERT_OVERLAY。
  - `ENDCAP_TOP_INSERT_OVERLAY_LINKED_FW_V1`：linked-FW 二級 INSERT_OVERLAY，`CERTIFIED`；公式為 `primary_u=side_fold+FW`、`primary_v=FW-1T`、`secondary_u=side_fold+0.5T`、`secondary_depth=2T`，沒有硬寫 16/23/14/4。

### 安全契約
- CERTIFIED / CERTIFIED_FROM_3D 命中後，3D 僅 shadow validate；`ENGINE_CONFLICT` 不得改 canonical formula。
- fallback 開關改為「未知組合允許3D求截角」；關閉時仍必須查 certified registry。
- `REGISTRY_AMBIGUOUS` 直接阻止自動決策，禁止吞例外後改走 3D。
- Save/Reload 保存 `rule_id / rule_revision / trust_level / canonical_accepted / shadow_validation`；stale revision 不 replay。
- Promotion UI 只建立 `PROMOTION_CANDIDATE` manifest，`mutates_registry=False`，不能 runtime 一鍵寫入正式 registry。
- Head 2D canonical scene 最後做 Y mirror，所以 semantic TOP joint 在 Head physical bottom；Tail 保持 native，semantic TOP 在 physical top。Registry evaluator 必須依此放置 cut。

### 自動驗收
- `tests/test_phase6_assembly_registry_gui_matrix.py` 改由 active Certified Relief Registry 自動列舉 Assembly Intent，不再依手工白名單。
- 每筆 active registry rule 自動驗證 ID/revision 唯一、evidence/公式存在、fixed policy 四角完整。
- 新 intent / new active rule 若未通過 registry-driven matrix，不得視為可交付。

### 實檔
- `自訂(9).p6fold`：Head/Tail `ENDCAP_TOP_INSERT_STRUCTURAL_CONTACT_V1@1`，`CERTIFIED`，38×27，collision 170 segments，2D=single3D=assembly，reload diff=0。
- `自訂(10).p6fold`：Head/Tail `ENDCAP_TOP_INSERT_OVERLAY_LINKED_FW_V1@1`，`CERTIFIED`，40×23 + 16×4，collision 198 segments，2D=single3D=assembly，reload diff=0。

## [13:39] Certified Relief Registry 最終 Fresh Gate
- compileall PASS。
- Registry/collision/backprojection：87 passed。
- Registry 真 Tk GUI matrix：3 passed。
- Assembly 3D / dimensions / FinalScene / return-to-2D：38 passed。
- Project / receiving：29 passed；2 條 stale GUI test 經 082214 基準 fresh 比對為既有失敗。
- `自訂(9)`：CERTIFIED 38×27，Head/Tail、Save/Reload、canonical diff=0。
- `自訂(10)`：CERTIFIED 40×23 + 16×4，Head/Tail、Save/Reload、canonical diff=0。
- 最終封包時間戳：20260829_133925。

- 封包第一輪實解驗證：FULL 681/681、UPDATE 28/28 SHA256 全一致；0 missing / mismatch / extra；`config.ini` 未變。

## 2026-08-29 15:xx — INSERT 單級拓撲與 linked-FW C04 修正

- 純 `INSERT` 與 `OVERLAY` 是**單級截角**；資料模型現在會強制清除任何殘留 `secondary_retain_t` / `secondary_depth_t`。
- Certified Registry 增加 topology boundary validation：`INSERT` / `OVERLAY` 規則若回傳二級 geometry，直接拒絕，不得成為 canonical material。
- 撤銷錯誤的 linked-FW `INSERT_OVERLAY` 推導 `16×23 + 14×4`。既有 2026-08-21 C04 製造契約明確規定第二級 CUTTING = `side_fold + 0.5T`；第一級 X = `side_fold + FW`。
- 因此 T=2、side_fold=15、FW=25、無獨立 ytop1 的 linked-FW fixture 正確為 **`40×23 + 16×4`**。有 ytop1=16 的標準 C04 fixture 為 **`40×39 + 16×4`**。
- `ENDCAP_TOP_INSERT_OVERLAY_LINKED_FW_V1` 信任等級改為 `CERTIFIED`，證據來源改為既有 C04 製造規格，不再以錯誤 3D 候選升格。
- 實際 `自訂(10)` 切換為純 INSERT 後：Head/Tail = **38×27，secondary=None**；Save/Reload 後仍保持單級。

## [SUPERSEDED] 2026-08-29 15:xx — OVERLAY flat-X 名義側折中間修正
- 根因：`OVERLAY` 正確要求 X topology 為 flat、無左右 X BEND；但 EndCap builder 與 Certified Registry 又把此「有效折彎=0」直接拿去當截角公式的 `fold_u=0`，因此標準 `side=15/FW=25/ytop1=16/T2` 被錯算成 `25×39`。
- 正確契約：flat-X 只移除 BEND；截角仍使用原始 `yl1/yr1` 作名義側折基底。標準 OVERLAY 為 `primary_u=nominal_side+FW`、`primary_v=ytop1+FW-1T`，因此此 fixture = **40×39，單級**。
- Source of Truth 修正：`build_unknown_endcap_result()` 分離「實體 fold topology」與「relief nominal fold basis」；manufacturing request 保存 nominal fold；PartRenderData metadata 傳遞給 Certified Registry；solver rebuild 保留 metadata。
- TDD：新增 `tests/test_overlay_nominal_side_fold_contract.py`，先確認 2D builder 與 Registry 都 RED=25×39，再修成 GREEN=40×39。
- 真 GUI：Head/Tail 均命中 `ENDCAP_TOP_OVERLAY_STANDARD_V1`，40×39，secondary=None，2D vs assembly diff=0。
- 反向回歸：`自訂(9)` INSERT 仍 38×27；`自訂(10)` INSERT_OVERLAY 仍 40×23+16×4，兩者 Save/Reload metadata 一致。

## 2026-08-29 — UPDATE 驗收工件缺檔修正

- 發現既有交付規則「UPDATE 僅收錄相對基準的差異檔」存在安全漏洞：若使用者將較新的 UPDATE 套在未包含早期新增測試的舊工作目錄，可能出現交付日誌已聲稱新增 registry gate 測試，但本機實際沒有該測試檔。
- 實際核對：`tests/test_phase6_assembly_intent_registry_matrix.py` 與 `tests/test_phase6_assembly_registry_gui_matrix.py` 在 FULL 075946 之後皆存在；但 082214 / 152212 / 160848 等 UPDATE 因兩檔未再次修改而未重複收錄。
- 新增 `release_required_artifacts.json` 與 `tools/phase6_release.py`。新規則：UPDATE = 真實差異檔 + mandatory verification artifacts。
- mandatory artifacts 至少包含兩支 Assembly Registry Gate 測試、Joint registry matrix、Certified registry completion、release integrity gate 與 registry verification 文件。
- 打包前若 mandatory artifact 不存在，release collector 直接失敗，不得產出 UPDATE。
- 新增 `tests/test_release_integrity_gate.py`，驗證即使 mandatory gate 檔案與 baseline 完全相同，也必須被 UPDATE 收錄；缺任一 mandatory 檔則 fail closed。
- Fresh 執行：`test_phase6_assembly_intent_registry_matrix.py` = 18 passed；`test_phase6_assembly_registry_gui_matrix.py` = 3 passed；release integrity gate = 3 passed。

## [SUPERSEDED AS COMPLETE CONTRACT] 2026-08-29 22:xx — 金庫型 OVERLAY 下方截角 364→394 basis 修正
- 實檔 `金庫型貼外.p6fold`：W=400、T=2、nominal side=15、FW=25、下方 `CROSS + EXTRA_CUT + WIDTH + 1.5T`。
- 錯誤根因：flat-X 時把 nominal side=15 當成四角共用 relief X basis；下方被算成 `15+3=18`/側，剩寬 364。
- 正確語意：上方 OVERLAY 裝配截角仍用 nominal side basis；下方 CROSS 用 physical X bend basis。OVERLAY 無左右 X BEND，因此下方 basis=0。
- 修後：上方每側 40、剩寬 320；下方每側 3、剩寬 394。
- 2D / 單板3D / 組合圖 / Save→Reload 實檔材料完全一致，symmetric difference=0。
- 新增 Skill `.agents/skills/engineering/phase6-overlay-relief-basis/SKILL.md` 與 regression `tests/test_overlay_nominal_side_fold_contract.py`。

## [SUPERSEDED] 22:xx OVERLAY flat-X nominal-FW 中間更正
- 使用者實檔 `金庫型貼外.p6fold` 證明先前上方 `40/320` 契約錯誤。
- 正確：W400/T2/FW25 時，上方每側 U CUT=FW=25、單側未截長375，`25+375=400`；左右都截後中央350。下方 1.5T 每側3、中央394。
- 根因：legacy nominal yl1/yr1=15 被錯用為 flat-X manufacturing X fold basis。
- `sheetmetal_part_adapters` 與 Certified Registry flat-X basis 統一為0；nominal yl1/yr1僅保留 metadata。
- Skill / CONTEXT / AI_HANDOFF / SOP / pitfall / verification 同步撤銷 40/320 錯規則。

## 2026-08-29 23:xx — OVERLAY formed FW Registry / 3D Relief 正式化
- 使用者再次確認物理驗收：`FW成型29你不截29怎麼插進去？`。因此前兩個中間答案 40/320 與 25/350 都撤銷。
- 正式區分：EndCap nominal/material FW=25；Box Body Fold Profile 折後 formed FW occupation=29。上方 OVERLAY X CUT 必須避讓 formed occupation，不能只看 EndCap nominal FW。
- `金庫型貼外.p6fold` 現行真值：上方每側 29、中央342、單側 `29+371=W400`；V 仍由 EndCap FW25 算 39。下方每側3、中央394。
- Certified Registry：`ENDCAP_TOP_OVERLAY_STANDARD_V1` 升 revision 2，`geometry_inputs` 包含 `BOX_BODY_FORMED_FW`，X formula=`primary_u=mating_width`；不得硬寫29。
- Registry evaluator 直接共用 `phase6_fold_profiles.formed_box_body_fw_widths()`；UI/2D/3D 不得各自重算 formed FW。
- 3D solver certified shadow 保存 geometry_inputs / formed_fw_by_corner evidence；Head/Tail post-solve residual pair count=0；`ResolvedReliefRuleTrace` 同步保存 revision/evidence。
- persistence 升 `relief_contract_version=2`，source 保存 formed-FW fingerprint 與 per-part registry rule revision。原始實檔 versionless/revision-1 的 40-mm committed relief fresh load 即失效，不再重播。
- 真實 fixture `tests/fixtures/vault_overlay_w400_t2_fw25.p6fold` 為使用者上傳檔的 byte-identical copy。
- 回歸：affected core 165 passed；INSERT/OVERLAY/INSERT_OVERLAY GUI matrix 3 passed；實檔 2D/single3D/assembly/shared dimensions/Tail/Save-Reload 81 passed。
- 現行 Skill / AI_HANDOFF / CONTEXT / SOP / pitfall / verification 已統一為 formed-FW Source of Truth。

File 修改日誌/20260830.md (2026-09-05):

# 2026-08-30 修改日誌

## 受電箱封頭／封尾下方外側包覆（WRAP）

- `WRAP` 不再視為箱身／封頭尾的第四種高階組合方式；它是**受電箱封頭／封尾下方專屬接合條件**。
- 箱身仍固定使用側背分離結構；封頭／封尾本身仍可各自使用 `INSERT / OVERLAY / INSERT_OVERLAY`，下方 WRAP 與這三種高階組合方式正交。
- WRAP 開啟時，下方截角使用 WRAP 專屬 Registry 規則，不直接沿用 INSERT、OVERLAY 或 INSERT_OVERLAY 的截角／展開結果。
- Head/Tail 的 WRAP 設定加入既有「先連動、再可分離」語意：通常上下相同；設定連動不代表直接複製另一端 Polygon/Blank。

### 可調預留

受電箱下方 WRAP 的兩個預留量改成獨立 mm 參數，放在「參數鎖定」解鎖區：

- `reserve_u`：X 預留，預設 2 mm。
- `reserve_v`：Y 預留，預設 1 mm。

正式幾何式：

- 第一級 X = 封頭／尾該側折 + 側板後折 - `reserve_u`
- 第一級 Y = `ybottom1` - `reserve_v`
- 第二級 X = 封頭／尾該側折
- 第二級深度 = `reserve_v`

預設 `側折=15、側板後折=15、ybottom1=15、reserve_u=2、reserve_v=1` 時為 `28×14 + 15×1`。

## 3D placement / piece-level solver

- 受電箱側背分離後面板改為獨立 piece-level 3D 幾何，Joint solver 可解析 `box_body:left_side / box_body:back / box_body:right_side`。
- 受電箱 EndCap 使用 Fold Profile core datum 進行 assembly-depth placement；此 core-origin 行為**只限受電箱**，金庫型／自訂既有 placement 契約維持不變，避免既有 INSERT/OVERLAY/INSERT_OVERLAY 回歸。
- Viewer 與 Collision Solver 現在由同一個 Family scope 決定是否使用 core-origin，避免畫面與求解位置分歧。

## 展開料（Blank）

- 每片板金的展開料資訊由 canonical final material 直接量測，不另建第二套 Fold 長度公式。
- 單片零件顯示自己的展開尺寸／面積；多片箱身逐片回傳左側板、後面板、右側板等各自 Blank。
- Head/Tail 即使 WRAP 設定通常連動，也各自以自己的 final material 算展開料；兩者相同只能是幾何結果相同，不是互抄。

## Skills 搬移與 3D 完整性 Gate

- 專案 Skills 已由根目錄 `skills/` 全部搬到 `.agents/skills/`。
- 新增 `.agents/skills/engineering/phase6-corner-3d-model-integrity/SKILL.md`。
- 只要修改截角、Joint、Collision、Fold/placement 或 3D 圖，交付前必須同步驗證：true-thickness、求解前碰撞、求解後零非法穿透、Head/Tail、piece-level、2D/單板3D/組合3D、展開料與 Save/Reload。
- UPDATE 增加 `skills/` cleanup 契約與 `APPLY_PHASE6_UPDATE_CLEANUP.bat`，確保從 canonical baseline 更新後不殘留舊 Skills 路徑。

## GUI / 2D / 3D 完整性收尾

- 動態切換受電箱後，常駐「結構」列與 canonical Family state 同步為「三件式（側背分離）」，不再顯示 stale「一體成型」。
- 封頭／封尾切換貼外時，active editor 與 workspace 同步替換 flat-X profile；左右 X BEND 一起消失。
- 二件式／三件式箱身逐 physical piece 顯示自己的 canonical 展開尺寸；操作員畫面移除淨面積與 raw English part ID。
- 單板 3D 與組合 3D 圖面本身新增 canonical 展開尺寸文字，與側邊資訊使用同一 Source of Truth。
- 組合板件區加入 Canvas + 垂直捲軸與內容列滑鼠滾輪。
- 截角資料庫／Joint 操作員介面完成繁中映射；stable Rule ID、enum、formula token 留在資料層，不直接顯示。
- 主 2D 預覽改用共用上方標註帶與右側尺寸 lane；真 Tk Canvas bbox regression 驗證說明／截角尺寸／開孔提示彼此不重疊，也不覆蓋材料。
- 新增 `tests/test_phase6_gui_3d_integrity_20260830.py`，並列入 cumulative UPDATE mandatory artifact。

## 20260830_131634 正式 Release Gate

- 修正 `test_phase6_3d_single_source_renderer.py` 無 DISPLAY skip 分支缺少 `pytest` import 的測試 harness 假紅燈；production 未變。
- canonical FULL config SHA256：`5947c847ab96a6d739d464d75f50457300ac2cd240e232eb0f2fe1d53c41683d`；UPDATE 禁止包含 config。
- cumulative UPDATE baseline：`PHASE6_FW_LINK_BUGFIX_FULL_20260823_212355(3).zip`。
- 第一輪包：FULL 743 檔、UPDATE 460 檔；ZIP CRC 通過。
- UPDATE 疊 baseline + cleanup 後，production payload 563/563：0 missing / 0 extra / 0 SHA mismatch。
- FULL-only 180 個歷史檔全部位於 release policy 明確排除於 UPDATE 的 `BACKUP*` 目錄。
- freshly extracted FULL 責任 gate：118 core + 9 GUI integrity + 3 Registry GUI + 3 OVERLAY + 20 headless/5 Tk structure + 81 headless/3 Tk 3D + 19 Save/Reload 全部通過。
- 驗證文件回寫後以相同 `20260830_131634` 時間戳重封，再做最終 CRC/SHA/fresh smoke。

## 受電箱 Family / WRAP / 展開料漂移 Follow-up

- 切換「受電箱」現在是完整 Family transaction，立即帶入 `W=800 / H=1600 / D=350`，同步 3D 全域欄位、snapshot 與箱身 profile。
- 封頭／封尾的「下方外側包覆」啟用選擇改為常駐可見；X/Y 預留仍只在參數解鎖區顯示。
- 修正 Head/Tail 每切換一次展開料約 +2 mm：Receiving EndCap D 核心的 `D-2T` compensation 現在由 Family policy 單一派送到 profile read、derived-core propagation 與 live W/H/D sync，禁止 Vault `D-3T` 回寫全域 D。
- Receiving Family profile merge 後再次套 topology transform，避免 Vault `zr1` 從舊 vault profile 滲回。
- 組合體左側板件／輸入區取消固定高度切片，改用全部剩餘空間並維持既有捲動功能。
- 新增 `tests/test_phase6_receiving_followup_20260830.py`；Receiving / WRAP 40 passed、3D/OVERLAY 45 passed、結構 20 headless + 5 Tk、Registry/Collision 101 passed、Save→Reload 19 passed。

## 組合體左側旗標框移除
- 使用者回報組合圖旗標仍存在。
- 根因：組合板件區雖已 `fill=BOTH + expand=True`，外層仍使用 `ttk.LabelFrame(text="組合圖板件 / 截角尺寸 / 展開料")`，因此仍有獨立標題與框線。
- 修正：外層改為普通 `ttk.Frame`，保留同一可捲 Canvas 與內容列，組合體模式直接吃滿左側剩餘空間。
- 新增 `test_assembly_mode_has_no_separate_labeled_flag_frame` 防回歸。

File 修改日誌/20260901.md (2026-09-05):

# 2026-09-01 修改日誌

## Joint Graph / STANDARD / Certified Relief 收斂

- 新增 Assembly Intent Registry 與 explicit four-edge Joint Map。
- Joint serialization 升級 v2；補 schema-1 side-only legacy migration，graph-first 保留 user/explicit overrides。
- UI / Fold Designer 拆開 preset mirror 與 resolved graph ownership，移除正常流程 Top CornerType 反推覆寫。
- Corner resolver 改讀 nearby AssemblyJoint；Certified Registry 支援 edge-aware signature、2-stage OVERLAY、完整 rule metadata/diagnostics。
- OVERLAY runtime 正式收斂到 `ENDCAP_TOP_OVERLAY_STANDARD_V1@3`：STANDARD `40×41` → `40×39 + 15×2`。formed FW=29 只作 shadow/historical evidence。
- blank/piece dimensions 改讀 material segment chain / physical piece topology，不讀 relief 後 polygon bbox 當採購/展開 W×H。
- Receiving BOTTOM WRAP 改由 Joint Graph/Registry 擁有，Family 只供 geometry/reserve；修正舊 family-owned bottom policy。
- replay fingerprint 納入 Joint mechanical semantics、family structure、registry revision，修正 provenance/legacy region alias 導致合法 canonical cut 被誤判 stale。
- diagnostics 改為 joint-local；BOTTOM Certified trace 不再串到 TOP。
- 修正 Indicator Box → direct door-indicator 切換後 stale workspace presence 汙染 Save/Reload。
- 修正 part switch outgoing idle callback 導致重複 redraw、以及 shared corner measurement formatter NameError。

## T8 測試與文件遷移

- 將多個 legacy side-only intent、Top CornerType ownership、首頁/button UI、confirm/cancel、formed-FW 29、OVERLAY single-stage、Receiving bottom INSERT_OVERLAY 等歷史 oracle 改為目前正式契約。
- 外部 `/mnt/data/自訂*.p6fold` 缺失時只 skip 明確依賴該實檔的 cases。
- 更新 `phase6-overlay-relief-basis` Skill，舊 2026-08-29 formed-FW 文件標示為 superseded historical evidence。
- 新增 Joint Graph migration verification，並更新 release mandatory artifacts。

## 保護項

`config.ini` 未修改；正式 FULL/UPDATE 仍須依 `phase6-release-packaging` 完成 canonical baseline、CRC/SHA/Unicode、fresh extraction 與 packaged FULL regression gate。

## Final QA / Packaging

- 完成 #126～#166 fresh module QA；修正數個 stale test oracle（Hole Editor layout owner、schema-driven settings hidden keys、3D Menubutton UI、繁中板厚錯誤訊息），production 不倒退舊 ownership。
- 完成 Registry/Joint/WRAP/3D/blank/Save-Reload 高風險 release matrix。
- canonical baseline 經 CRC、root layout、config SHA 驗證；UPDATE 覆蓋 + cleanup 後與目前 source 逐檔 SHA 完全一致（missing/mismatch/extra = 0/0/0）。
- 完成 packaged FULL fresh extraction 功能 gate；正式封包以最後一次 Asia/Taipei timestamp 重建。
### [19:44:50] 變更紀錄
- **變更檔案**：$_, $_, $_, $_, $_, $_, $_, $_, $_
- **備份檔名**：$_, $_, $_, $_, $_, $_, $_, $_, $_
- **修改摘要**：清理 基準檔 內錯置的 Python 程式與測試副本；正式程式入口仍使用專案根目錄 gui.py、
old_designer_bridge.py、phase6_fold_profiles.py 與根目錄 e_engine package，並保留 基準檔\gui.py 相容啟動器。

### [19:51:08] 變更紀錄
- **變更檔案**：.agents/skills/engineering/派工/SKILL.md, docs/superpowers/verification/2026-09-01-dispatching-skill-frontmatter-verification.md
- **備份檔名**：BACKUP/20260901-194916-SKILL-派工.md, BACKUP/20260901-195108-20260901.md
- **修改摘要**：補上派工 skill 的標準 frontmatter，設定 
ame: dispatching、人工指定用 description 與 disable-model-invocation: true；新增 verification evidence，並確認本地 41 個 SKILL.md 已無 missing name、重覆 name 或內容重覆。

### [Receiving EndCap D-2T 回歸修正]
- 修正 `ae_engine/cabinet_types/receiving.py:endcap_depth_comp_t()` 被誤改成 `3T` 的回歸；受電箱封頭／封尾 D 材料核心恢復 canonical `D - 2T`，金庫型仍維持既有 `D - 3T`。
- `gui.py:_end_cap_part_spec_from_values()` 不再以 `3T` 作所有 Family 的隱含預設；caller 未明傳時會依 `model_name` 取得 Receiving Family policy，堵住靜態/重建路徑回落 Vault 公式。
- 更新 Receiving 2D/Profile/Save-Reload 測試 oracle：D350/T2 的 EndCap D material core = 346；補 GUI adapter family-policy regression。
- 清理 `PROGRESS_README_20260831.md` 殘留的 Receiving `D-3T` 敘述，避免後續維護再次誤套金庫型公式。

### [Receiving EndCap Y Fold Chain canonical topology 修正]
- 根因：`phase6_fold_profiles.py` 只把金庫型 9 段 `zl1/zl2/FW/D/W/D/FW/zr2/zr1` 視為 canonical；受電箱 Family 正規 transform 移除 `zr1` 後成為 8 段，卻被誤判為 user-custom topology。
- 錯誤 generic mating mapper 因此把箱身 `zl1`、`zl2` 各自複製為 EndCap Y 的 `box_mating:zl1`、`box_mating:zl2`，造成封頭／封尾 Y 軸多一折，並使 Certified Registry 誤走 `ytop1_absent` 的 linked-FW 規則，出現 `40×23 + 16×4`。
- 修正 canonical 判定改為比對「目前 Cabinet Family 自己的 `build_box_body_profile(snapshot)` topology signature」；忽略尺寸值，只比對 segment key/core/BEND ownership/angle。金庫型 9 段與受電箱 8 段因此各自辨識正確，真正增刪折／改角度的自訂 topology 仍走 generic mapper。
- 受電箱 canonical Head Y 恢復 `ytop1 → FW → D-core → ybottom1`；Tail native Y 恢復 `ybottom1 → D-core → FW → ytop1`。不再生成 `box_mating:zl1/zl2`。
- 上方 `INSERT_OVERLAY` 因 `ytop1` 正確存在，Certified Registry 改命中 `ENDCAP_TOP_INSERT_OVERLAY_STANDARD_V1`；T=2、side fold=15、material FW=25、ytop1=16 時恢復 `40×39 + 16×4`，不再誤用 linked-FW `40×23 + 16×4`。
- 新增 Receiving family regression，並保留既有五段 `FW-D-W-D-FW` 的合法 `ytop1_absent` 行為與任意自訂多段 mating chain 行為。

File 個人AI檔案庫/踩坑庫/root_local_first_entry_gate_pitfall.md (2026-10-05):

---
whd_doc_role: REFERENCE
whd_contract: pitfall-ledger
whd_canonical: null
whd_schema: WHD_DOC_META_V1
---
# Root-local-first 入口硬閘門踩坑

## CURRENT workspace-first 覆寫規則 — 2026-10

- repository-content normal route 固定為 `WORKSPACE_DEFAULT`：使用 **executor-local repo workspace** + fresh `cleanup/2d-3d-sync` baseline 完成 author/test/exact diff，再進 delivery。
- Drive/shared-zero 已退役；有無 historical drift 都固定 WORKSPACE_DEFAULT，不得啟動 shared-zero fallback、merge/freeze 或 /推推 前置。 repository-content 修改先在 executor-local repo workspace + fresh cleanup/2d-3d-sync baseline 完成 author/test，再以 exact tested diff delivery。
- Codex 常見 workspace 為 `/workspace/whd`；missing Drive mount 不是 `WORKSPACE_DEFAULT` blocker。
- 本檔較早的 Drive/shared-0 順序只保留 **HISTORICAL/SUPERSEDED** 事故脈絡，不得再作 CURRENT execution instruction。
- Git phase 仍禁止直接寫 `cleanup/2d-3d-sync` / `main`；只允許 exact-tested-diff 的 dedicated delivery path。

## 2026-09-29 — workspace-first 與 branch-before-write 衝突（HISTORICAL/SUPERSEDED）

- **歷史事故摘要**：舊流程曾同時存在 Drive-first 與 branch-first 兩種互斥施工順序，造成同一任務出現兩套 authority。
- **CURRENT 規則**：只接受 executor-local repo workspace + fresh `cleanup/2d-3d-sync` baseline；Drive snapshot 僅可作 recovery material，不能成為施工 baseline。
- **Git phase invariant**：禁止直接寫 `cleanup/2d-3d-sync` / `main`；tested exact diff 只能經 dedicated delivery branch → PR/checks → trusted merge/readback。
- **remote scope**：`SCHEDULER_LANE / GITHUB_ONLY / REMOTE_ACTION` 仍依 Flow v2 remote authority；不得拿 remote mode 當 interactive content-work bypass。
- **machine owner**：`tools/root_local_first_gate.py` + `tests/process/test_root_local_first_entry_hard_gate.py`。
## 2026-10-03 — 入口 contract 已存在，但 agent 先做 generic discovery

- **事故模式**：使用者要求直接修改 WHD 流程時，agent 沒有先讀 canonical root entry contract / root-local-first Skill，而先做 Remote Desktop、generic Drive search、工具 discovery；即使後來回到正確 root，前段仍屬錯序。
- **根因**：舊規則只規範「進入 root-local-first 之後怎麼做」，沒有 machine-enforce「找到入口本身必須是第一個 routing sequence」。
- **永久規則**：每個 WHD repository-content invocation 固定先 `READ canonical entry contract → READ root-local-first Skill → ENTRY_ROUTER_READY`；READY 前 generic discovery、Remote Desktop/local search、GitHub content discovery、claim/Flow v2 discovery 全部 fail closed。
- **錯序處置**：任何 READY 前取得的 generic discovery 只能標記為 non-execution evidence；固定 `FAIL_CLOSED_RETURN_TO_CANONICAL_ENTRY`，不得沿錯路續做。
- **防回歸 owner**：`tools/root_local_first_gate.py`、`WHD_ROOT_SHARED_UNPUSHED_ENTRY_HARD_GATE_V1.json`、`AGENTS.md`、`tests/test_root_entry_router_hard_gate.py`。

## 2026-10-03 — 歷史 Drive/shared-zero authority 被 generic search 重播（HISTORICAL/SUPERSEDED）

<!-- ROOT_PARENT_CHAIN_AND_LATEST_ZERO_PITFALL_V1 -->
- **歷史事故摘要**：舊文件把 Drive/shared-zero 描述成可執行施工 authority；agent 透過 generic search 讀到舊文件後，會把歷史資料誤當 CURRENT 流程。
- **CURRENT 規則**：repository-content baseline 只取 fresh Git production X，施工與測試只在 executor-local repo workspace；任何 Drive Skill、snapshot、generation、lane 或 historical receipt 都不能改變 route。
- **禁止重播**：不得從歷史文件重建 parent-chain、latest-generation、shared lane reconcile、freeze 或 cleanup 作為 CURRENT startup/delivery gate。
- **錯路處置**：若已引用歷史 authority，該 routing evidence 立即失效；回 CURRENT entry contract + root-local-first Skill，重新以 executor-local workspace + fresh X 建立 candidate。
- **delivery boundary**：tested exact diff → dedicated delivery branch → PR/required checks → trusted merge/readback；target drift 先做 GREEN reuse impact revalidation，有影響才回 workspace 重測。
- **machine owner**：`tools/root_local_first_gate.py`；legacy shared-unpushed utilities只可作 HISTORICAL parser，不擁有 CURRENT routing/finalization。

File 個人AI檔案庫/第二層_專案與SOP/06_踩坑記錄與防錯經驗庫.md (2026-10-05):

---
whd_doc_role: REFERENCE
whd_contract: pitfall-ledger
whd_canonical: null
whd_schema: WHD_DOC_META_V1
---
<!-- WHD_DOC_ROLE role=REFERENCE contract=pitfall-ledger -->
> **[REFERENCE / INCIDENT LEDGER]** 本檔保存踩坑、事故、歷史修正與跨域索引；**不是 CURRENT domain authority**，也不得因內容較長就覆蓋 focused spec / Registry / Skill。
> Current owner 查找一律先讀 `個人AI檔案庫/第二層_專案與SOP/09_WHD_Canonical_Authority_Map.md`；manufacturing 架構/API 讀 `個人AI檔案庫/第二層_專案與SOP/04_WHD鈑金展開幾何引擎規範.md`。若本檔段落與 CURRENT owner 衝突，以 CURRENT owner 為準，並在舊段落原位置標 `HISTORICAL / SUPERSEDED`。

# ⚠️ 06. 踩坑記錄與防錯經驗庫 (Bad Patterns & Lessons Learned)
## 執行／監控踩坑索引 — LONG_LOG_CONTEXT_SAFE_EXECUTION_V1

超長 pytest / Xvfb / Combined Acceptance / GitHub Actions Log 不得反覆整包灌入 context；canonical 規則見 `.agents/skills/engineering/long-log-context-safe-execution/SKILL.md`，事故與復原細節見 `個人AI檔案庫/踩坑庫/long_log_context_safe_execution.md`。

> 本文件記錄 ㄚ凱 在 CAD/CAM、WHD 幾何展開與 Ollama 拆圖實戰中「踩過的坑」與「反面教材」。
> 所有 AI 在進行架構設計或代碼修改前，**必須先檢核本清單，嚴禁重蹈覆轍**。

---

## 🚫 幾何與演算法避坑指南

### 1. 視圖裁切範圍 (crop_bbox) vs 主箱體幾何範圍 (geometry_bbox) 混淆
- **踩坑情境**：將正視圖的裁圖範圍（含標註、PANEL 文字）直接拿來當成箱體實體幾何計算，導致幾何中心偏移（如 1385.27 vs 正確實體 1432.02）。
- **正確做法**：嚴格區分 `crop_bbox`（裁圖區）與 `geometry_bbox`（實體幾何），驗證尺寸只對準主幾何。

### 2. 箱體總高含底座導致展開尺寸錯誤
- **踩坑情境**：來源總外高為 2200（含 50mm 底座），若未扣除底座直接計算，會導致門板與箱身高度過大（如門算成 2161 而非正確 2111）。
- **正確做法**：使用 `detect_child_bottom_base()` 做幾何交叉驗證，確認底座後，箱體實際高扣除底座高，底座獨立輸出。

### 3. 硬編碼 12/16/17 點主外框陣列
- **踩坑情境**：為每個新零件手推頂點陣列，導致維護困難且無法通用。
- **正確做法**：全面使用 Shapely 布林運算（`Base Polygon - Relief Polygon`），新零件只需傳入折邊尺寸與扣量。

### 4. 任意把金庫型規則推廣為宇宙通則
- **踩坑情境**：直接將金庫型的 `0.5T` / `2T` 插入退讓套用到其他箱型（如戶外箱、落地盤）。
- **正確做法**：Topology（折彎結構）可共用，Factory Policy（退讓規則）必須依箱型獨立配置。

### 5. 把 `FW` 當成一般 Fold Segment，導致框寬被重新分配
- **踩坑情境**：箱身 `FW=25`，封頭／封尾旁邊另有 16mm 折邊；推導 arbitrary Fold Chain 時把兩者合併成 `16 + 25 = 41`，最後專案檔竟儲存成 `fw=41`，造成封頭尾與箱身門框基準失去一致。
- **根本原因**：混淆「成品框寬尺寸語意」與「展開折彎鏈 segment/span」。
- **正確做法**：`FW` 永遠是邊框寬度／框寬的獨立 Source of Truth；Fold Chain 可以引用 FW，但不得重新分配、合併後再冒充 FW。相鄰的 16mm、15mm 等折邊必須保留自己的語意。

### 6. 把 2D 展開 `bbox` 當成 3D 折後包外尺寸
- **踩坑情境**：箱身 2D 展開 material bounds 為約 `938 × 596`，3D 尺寸標註直接沿用該範圍，導致把展開寬 938 誤標成成品寬；或直接用 core `396 / 246` 當成成品 `W / D`。
- **根本原因**：未區分「展開板尺寸」、「core 尺寸」、「單件折後包外」與「整箱組裝包外」四種不同尺寸空間。
- **正確做法**：3D 尺寸從折後實際外表面 envelope 計算並包含板厚；單件視圖標單件折後包外，整箱視圖標組裝後 `W / H / D`。

### 7. 忽略組合方式，錯把箱身單件高度永遠等同整箱 `H`
- **踩坑情境**：設定箱體 `H=600, T=2` 時，不論封頭／封尾是嵌入、貼外或嵌入貼外，都把箱身單件高度硬寫成 600；或反過來看到箱身 596 就誤認整箱成品高只有 596。
- **根本原因**：混淆「完整箱體包外 H」與「箱身單件折後高度」，沒有把封頭／封尾在外部占用的板厚納入尺寸鏈。
- **正確做法**：`INSERT=0T`、`OVERLAY=1T`、`INSERT_OVERLAY=1T`（每一端）。`BoxBodyFinishedHeight = H - HeadOutsideOccupancy - TailOutsideOccupancy`；完整組裝後仍回到輸入 `H`。下方 `CROSS / extra_cut` 不參與此高度扣量。

### 8. 封頭／封尾各自保存一份折法，與箱身 Fold Chain 漂移
- **踩坑情境**：箱身由 9 段改為 5 段後，專案檔仍保留舊封頭／封尾 profile；3D、2D、DXF 甚至可能各自看到不同 BEND 數量。
- **根本原因**：把 derived end-cap mating profile 當成與箱身同等的獨立 Source of Truth。
- **正確做法**：箱身 Fold Chain 為折法權威來源；封頭／封尾接合 profile 依箱身拓撲、FW 與組合方式即時推導。按「確定」後同一份狀態必須回到 2D 與 DXF。

### 9. 用固定段數判斷 Fold Chain
- **踩坑情境**：為 5 段、9 段各寫一套 if/else，新增 6、7、12、20 段時立刻失效。
- **根本原因**：把實例的段數誤當成拓撲規格。
- **正確做法**：以 ordered Fold Chain + semantic dimensions/core/assembly policy 驅動；測試可覆蓋 3/5/9/12/20 段，但 production code 不得依賴固定段數。

### 10. 板件「刪除」只做 UI 隱藏或要求先進入板件頁
- **踩坑情境**：沒有的板件必須先切進該頁才可刪除，或畫面看似刪除但 `existing_parts`、2D tab、DXF export、`.p6fold` 仍把它當存在。
- **根本原因**：把「目前選中頁面」與「板件存在狀態」綁在一起。
- **正確做法**：板件選擇區選中即可刪除；`existing_parts` 是正式狀態並同步 2D/3D/export/project。箱身為主體不可刪；其他板件可刪除與加回。

### 11. 把 FW 連動做成「永久鎖死」或「兩端各自 override」
- **踩坑情境**：為避免 FW 漂移，直接把封頭／封尾 FW 欄位設成唯讀；或反過來讓封頭、封尾一開始就各自獨立 override，導致實際操作時無法符合「先改一端就帶另一端、再改另一端才分離」的習慣。
- **根本原因**：只用兩個 `follow_box` 布林值描述控制權，無法表達「箱身主導 → 封頭主導／封尾主導 → 兩端獨立」的操作歷程。
- **正確做法**：使用四態 `FOLLOW_BODY / FOLLOW_HEAD / FOLLOW_TAIL / INDEPENDENT`。初始箱身主導；先改封頭則封尾跟封頭，先改封尾則封頭跟封尾；之後再改原 follower 才解除連動。任何狀態下，只要使用者重新提交箱身 FW（即使同值），箱身立即重新接管兩端。
- **UI 要求**：封頭／封尾 FW 欄位保持可直接輸入，不靠 disabled/readonly 來維持資料一致性；一般 redraw/refresh 不得偷偷切換控制權。
- **一致性要求**：2D、3D、CornerPolicy、FinalScene、DXF export、`.p6fold` 必須使用同一個有效 FW 解析結果，禁止 UI 顯示一套、加工端使用另一套。

### 12. 箱身已刪外側折，封頭／封尾卻仍硬補舊折段
- **踩坑情境**：箱身 Fold Chain 從原本較多段改成 `FW → D → W → D → FW` 後，封頭／封尾 2D 仍保留舊 `ytop1=16` 類外側折，使用者必須手動刪掉才看起來正確。
- **根本原因**：end-cap derivation 把舊固定 profile 當 fallback，而不是把「該折段是否存在」直接由箱身 topology 決定。
- **正確做法**：箱身刪折就自動刪除封頭／封尾對應折；新增/改角度亦同步。可選 segment 缺席是合法狀態，不得自行補回 legacy fold。

### 13. 只刪 BEND，沒有同步縮短 2D blank / material 外框
- **踩坑情境**：封頭／封尾視覺上少了一條 BEND，但 2D 外框仍沿用舊 fold_top 尺寸，導致板件尺寸沒有真正跟箱身對齊。
- **根本原因**：BEND profile 與 Base Polygon / structural dimensions 分開計算，形成兩套幾何。
- **正確做法**：Fold Profile 改變時，BEND、Base Polygon、material bounds、blank size 與 DXF 必須從同一份 derived profile 一次重建。

### 14. 沒有 `angle` 的 boundary 仍被畫成 BEND，造成 2D/3D 分叉
- **踩坑情境**：2D 因 cumulative boundary 存在而畫出一條 BEND，但該 segment 沒有 angle；3D 因沒有 angle 不會折，最後出現「2D 有折線、3D 卻共線 180°」的怪圖。
- **根本原因**：BEND 生成只看 segment 邊界，不看是否真的存在折彎指令。
- **正確做法**：只有明確具 `angle` 的 segment boundary 才能生成 BEND；Final 2D BEND 與 3D fold 必須 1:1。90° 是否正確要直接驗證相鄰折後面的夾角。

### 15. 封尾 native order 反轉時遺失／錯置折彎角度
- **踩坑情境**：封尾本身沒有被使用者修改，但反向 profile 中某個 FW segment 失去 angle，造成最後兩段折後共線或折向錯誤。
- **根本原因**：直接拿已經 native/reversed 的 tail profile 再當 canonical 模板，反轉 segment 順序時沒有保留「angle 屬於哪一道 boundary」的語意。
- **正確做法**：先從箱身建立 canonical mating chain，再轉換成封頭/封尾 local/native order；轉換時以 bend boundary 為單位搬移 angle，不以 list index 或 terminal segment 猜測。

### 16. 合法缺少可選折段，reader 卻判成「資料不完整」並 fallback 舊幾何
- **踩坑情境**：2D 已正確刪除 `ytop1` 對應折段，但 3D payload reader 因找不到 `ytop1` 就拋錯，最後退回舊固定 profile，造成 2D 正確、3D 又回到舊尺寸／舊 BEND。
- **根本原因**：把 legacy 固定欄位當成必要欄位，沒有支援任意 topology 的「segment 可以不存在」。
- **正確做法**：缺少可選 segment 應解析為 absent/0，而不是資料損壞；3D 必須直接使用同一 FinalScene / derived profile，不得 silent fallback 成舊 topology。

---

## 💻 程式開發與環境避坑指南

### 1. 硬編碼絕對路徑或暫存目錄
- **踩坑情境**：程式中寫死 `C:/Users/looae/.../my_debug.txt` 或固定輸出至特定專案目錄，換環境即崩潰。
- **正確做法**：輸出路徑一律跟隨使用者在 GUI 指定的「輸出根目錄」；臨時檔案放 `tmp/`。

### 2. 測試斷言未經真圖/真 CSV 驗證
- **踩坑情境**：單靠腦補或修改測試碼讓它表面通過，實際上線處理真實 DXF 時出錯。
- **正確做法**：嚴格遵守 TDD，先跑真圖 regression，確認尺寸與 DXF 圖元無誤。

### 3. 未備份直接覆寫目標檔案
- **踩坑情境**：手滑改錯造成原始圖檔或關鍵代碼損壞。
- **正確做法**：修改前必須強制備份至 `BACKUP/YYYYMMDD-HHMMSS-檔名`。

### 4. 程式已改規則，卻等使用者再次提醒才更新 SOP
- **踩坑情境**：程式已新增/修正幾何、資料契約或 UI 行為，但規範仍停留在舊版本；後續 AI 讀到舊 SOP 又把已修好的行為改回去，或使用者必須重複提醒「把這條寫進文件」。
- **根本原因**：把文件更新當成額外任務，而不是程式修改的完成條件。
- **正確做法**：凡新增/修改正式行為或解掉可重現 Bug，本輪交付時直接同步對應 SOP 與本踩坑庫；**不等待使用者再次要求**。程式、測試、README/SOP 必須同版。

---

## 🔄 經驗追加範本
每次遇到新 Bug 解決後，依此格式追加：
```markdown
### [YYYY-MM-DD] 問題簡述
- **錯誤現象**：...
- **根本原因**：...
- **防錯規則**：...
```

### 17. 為避免 ZIP 中文問題擅自把原始檔名改成 ASCII
- **踩坑情境**：遇到 Windows / ZIP 中文 entry 相容性問題時，為求方便把 `04_WHD鈑金展開幾何引擎規範.md` 等使用者原始檔名改成英文 ASCII 名稱，導致檔案庫結構與使用者既有命名不一致。
- **根本原因**：把「封裝／編碼問題」錯當成「檔名問題」，用改名規避真正的 UTF-8/ZIP 相容性問題。
- **正確做法**：保留原始中文檔名與資料夾結構；ZIP entry 明確使用 UTF-8，完成後實際解壓並逐檔比對 SHA256。只有使用者明確要求時才重新命名。

### 18. 封頭／封尾折角被硬寫成 90°，忽略 Fold Chain 輸入
- **踩坑情境**：箱身 Fold Chain 已輸入 45°、60° 或其他角度，但 linked EndCap derivation 只因「常見鈑金折彎」就把所有 angle 強制改成 `-90`，導致 3D 與操作員輸入不一致。
- **根本原因**：把「常見預設值」誤當成「製造規則」，derived topology 越權改寫 angle。
- **正確做法**：輸入幾度就折幾度；derived profile 只搬移 bend boundary 的 angle ownership，不得重設 angle magnitude/value。UI/engine 內部表示轉換必須 round-trip 無損。

### 19. 用相機投影設定掩蓋折彎角度 Bug
- **踩坑情境**：3D 看起來不像直角時，先改成 orthographic projection，希望畫面「看起來比較 90°」，但真正 Fold Chain/derived angle 仍然錯。
- **根本原因**：混淆 view/render policy 與 geometry。
- **正確做法**：視角只管顯示；角度只由 Fold Chain 輸入與折彎幾何決定。除非是獨立的顯示需求，不得修改 projection 來修幾何問題。

### 20. Phase6 已 commit 正確 FinalScene，主 2D 卻變成 `-` 或仍顯示舊尺寸
- **踩坑情境**：Phase6 封頭／封尾已是新 profile，但主 GUI `update_calculations()` 某分支沒有初始化後續共用變數，例外又被最外層 catch 吃掉，結果所有尺寸顯示 `-`；或仍走 legacy 尺寸公式。
- **根本原因**：主 2D 沒有完全沿用 committed FinalScene，且 silent exception 隱藏資料鏈斷點。
- **正確做法**：commit 後主 2D 尺寸直接量 authoritative RenderData/FinalScene；共用狀態在分支前初始化，真檔 GUI regression 必須驗證實際顯示值而不只 helper。

### 21. 板件按鈕要求雙擊／再按編輯，刪除動作位置不符合操作流程
- **踩坑情境**：單擊只選中，還要雙擊或再按一次「編輯」才進板件；刪除按鈕又藏在板件頁內，增加不必要操作。
- **根本原因**：把 selection 與 navigation 過度拆開，沒有依實際操作習慣設計。
- **正確做法**：板件按鈕**單擊一次直接進入**；不另設 Edit。刪除按鈕固定在板件按鈕區下方，箱身 disabled，其餘板件依存在狀態啟用。
### 22. AI 把「沒有重新驗證」誤判成「已確認機械規則可能是錯的」
- **錯誤現象**：使用者指出 AI 其實沒有真正理解「箱身＋封頭／封尾」組合關係後，AI 雖然正確承認先前有瞎猜，但接著又過度修正，把下列已經確認的正確規則一起說成「應撤回、不能當已知事實」：
  1. 箱身刪除組合接合鏈上的外側一折時，封頭／封尾對應折也要同步刪除。
  2. 封頭／封尾上方截角本身就是組合方式／裝配語意。
  3. 貼外關係每端占用 `1T`：`INSERT=0T`、`OVERLAY=1T`、`INSERT_OVERLAY=1T`。
  4. 五段箱身 `FW-D-W-D-FW` 時，封頭為 `FW-D-後折`，封尾 native orientation 為 `後折-D-FW`，不得補回舊 `ytop1` 外側折。
- **這次 AI 犯的真正錯誤**：
  - 把「我之前沒有親自重新證明這條」偷換成「這條本身可能是錯的」。
  - 看到程式存在 `assembly_type`，就武斷解讀成它和上方 CornerType 是兩套互相競爭的機械真值，沒有先確認它是否只是 UI／保存／映射層。
  - 因為 ZIP 當下沒有真 DXF／實體案例，就錯誤認為不能維持先前已由使用者確認的機械規則。
  - 一度想用「目前程式怎麼寫、測試怎麼斷言」來反推機械關係，形成循環論證：AI 猜規則 → 規則被寫進程式／測試 → AI 再拿程式／測試證明自己的猜法。
  - 沒有先區分「已確認的機械真值」「目前實作」「AI 尚未理解的部分」三個層次。
- **正確理解**：
  - 上述四條是使用者已確認的箱身 ↔ 封頭／封尾組合基準，後續檢查程式要問的是「哪裡沒有遵守」，不是再把四條拿回來猜一次。
  - 「箱身刪一折」必須精確限定在**組合接合鏈的外側可選折**，不能擴張成 D-W-D 核心也可隨意刪除。
  - 上方 CornerType 是機械裝配語意；額外欄位若存在，必須確認只是 representation / persistence，不得先假定為第二套真值。
  - `OVERLAY` 與 `INSERT_OVERLAY` 每端都占 `1T`；箱身單件高度據此從完整箱高 `H` 扣除，但完整組裝包外仍回到 `H`。
  - 5 段箱身的 end-cap mating profile 不得重新長回已被箱身 topology 刪除的 legacy 外側折。
- **防錯規則**：
  1. 使用者已明確確認並固化的機械關係，優先級高於目前程式、測試與舊設計文件。
  2. 缺少新證據只代表「不能再新增推論」，不代表「既有已確認規則失效」。
  3. 程式與規則衝突時，先把程式列為嫌疑對象，沿 Source of Truth → derived profile → FinalScene → 2D/3D/DXF 追資料流。
  4. 只有出現新的直接幾何證據、現場裝配證據或使用者明確更正，才可以提出修改既有機械基準。
  5. 測試通過只能證明「程式符合測試」，不能單獨證明「測試所描述的機械關係真實」。

### 23. AI 把封頭／封尾誤想成箱身「前後折」或單側 Fold Chain 的延伸
- **錯誤現象**：在討論箱身兩側外加折數不對稱時，AI 先問「封頭尾到底跟左邊還是右邊」，甚至把 Head/Tail 想成箱身前後兩側 Fold Chain 的延伸，試圖用單一 `source_front` / canonical chain 解釋整片端板。
- **根本原因**：只盯著 2D 一維 Fold Chain 與陣列順序，沒有先在腦中完成箱身折起後的實體拓撲。`FW-D-W-D-FW` 折起後形成的是背面 `W` + 左右側面 `D`，兩個 `FW` 是正面框邊；真正留下的是正面、上端、下端三個開口。
- **正確理解**：門補正面開口；封頭補上端開口；封尾補下端開口。封頭／封尾是上下端板，不是箱身前折／後折，也不能直接等同箱身某一側 Fold Chain。
- **防錯規則**：
  1. 遇到箱體組合問題，先畫出／描述折後實體的面與開口，再談 2D segment 對應。
  2. 不得由 `rows[:first_D]`、list 左右順序或「front/back」變數名稱直接推斷物理接合關係。
  3. 當左右外加折數不相同時，**在使用者確認前不要回答『跟誰』**；必須保留為待確認機械映射問題。
  4. 不得為了讓現有 helper 看起來合理，就把整個端口四周關係降維成一條 chain。

### 24. `assembly_type` 反向覆寫上方 CornerType，形成第二套機械真值
- **錯誤現象**：資料同時存在 `assembly_type` 與 Head/Tail 上方 CornerType 時，載入流程若優先相信 `assembly_type`，會把原本的上方 CornerType 改掉，連帶造成 2D 截角／組合語意被改寫。
- **根本原因**：把方便 UI／保存的 mirror 欄位提升成 Source of Truth。
- **正確理解**：封頭／封尾上方 CornerType 本身就是組合方式的機械語意；`assembly_type` 若保留，只能是 mirror/compatibility state。
- **防錯規則**：載入時不得以 `assembly_type` 覆寫上方 CornerType；不一致時以上方 CornerType 為準並同步 mirror，或明確報資料不一致。任何 2D 截角生成也必須直接消費 authoritative CornerType。

### 25. 用展開圖左右／折數直接猜封頭尾要跟誰
- **錯誤現象**：面對箱身一側 FW 外多 2 折、另一側多 1 折時，AI 直接回答「左側跟左側、右側跟右側」，或想以 segment 數量決定封頭／封尾對應。
- **根本原因**：仍把 2D Fold Chain 當成機械接合本體，沒有先判斷每一道 Fold 折起後的實體形態。
- **正確理解**：是否需要由封頭／封尾跟隨，必須看折後形態：該段最後落在哪個面、折向、是否形成上／下端口邊界、是否實際與端板搭接／包覆／嵌入。『跟誰』是折後形態分析的結果，不是用左右位置或折數先決定的規則。
- **目前範圍決策**：依折後形態會衍生多個新接合型態，使用者目前明確暫不處理。程式不得先發明新型態或猜配對；先只修既有 `assembly_type` 覆寫 Top CornerType 的資料真值 Bug。
- **防錯規則**：看到非對稱 Fold Chain 時，先標示為尚未建模的形態問題；除非已有使用者確認的形態分類，不得自動衍生 EndCap mapping。

### 26. 組合方式 Combobox 在自己的選擇事件中被重建，造成整頁／控制項消失
- **錯誤現象**：使用者在箱身選擇 `INSERT / OVERLAY / INSERT_OVERLAY` 後，組合方式控制或整個設定頁突然消失。
- **根本原因**：`<<ComboboxSelected>>` callback 裡立即 invalidate + destroy/rebuild 目前 box_body page，Tk 還在 dispatch 原 widget 的事件時就把來源 widget 銷毀。
- **正確做法**：目前 box_body page 保持存活；只 invalidate 依賴組合結果的 Head/Tail cache，derived geometry 即時更新，Head/Tail 等使用者切入時再重建。

### 27. 自訂模式雖隱藏「基準檔開孔資料」，卻又從進階設定把固定孔資料露回來
- **錯誤現象**：選 `自訂` 後表面上沒有基準檔區，但封頭／封尾「進階設定」仍出現掛孔、固定方孔、封尾固定孔等基準檔欄位。
- **根本原因**：同一 Setting group 同時被分類為 baseline-only 與 advanced，UI 分類重疊。
- **正確做法**：`固定孔 / 封尾固定孔` 只能屬於 baseline-only；自訂模式整組不存在，且不得進 advanced_specs。

### 28. 對稱折彎只同步輸入值，刪除卻只刪單側
- **錯誤現象**：勾選「對稱折彎」後改長度／角度會鏡像，但刪折段仍只刪點到的一側，箱身立即變成非對稱。
- **根本原因**：remove path 沒走既有 mirror mapping，只做單一 `pop(idx)`。
- **正確做法**：對稱箱身刪除使用同一 mirror index 規則；先確認兩側都可刪，再由高 index 到低 index 同一交易刪除。任一側不可刪則全部不動。

### 29. 3D draft 與主 2D 可同時編輯，造成 committed state 競爭
- **錯誤現象**：3D Fold Designer 開著時，主 GUI 2D 仍可修改；之後按 3D「確定」可能用較舊 draft 覆蓋剛在 2D 做的修改。
- **根本原因**：3D Toplevel 只是普通視窗，沒有建立 modal transaction 邊界。
- **正確做法**：3D 開啟期間以 modal grab 鎖住主 2D；確定才提交 draft，取消/X 丟棄並釋放 grab。禁止用兩邊同步寫入來掩蓋競爭。

### 30. 把 `OVERLAY` 只當 Corner relief 差異，忘了貼外型本身沒有左右 X 折彎
- **錯誤現象**：選貼外後，封頭／封尾 2D/3D 還保留左右折線，X 軸 Fold editor 也仍可編輯不存在的折彎，因此圖形明顯不符合實際貼外形態。
- **根本原因**：只換 Top CornerType/切口公式，卻沿用 `yl1 - W-core - yr1` 的有折 X profile。
- **正確做法**：`OVERLAY` 的 EndCap X profile 從資料源即表達為無 angle 的 flat span；FinalScene 不得產生 X BEND，3D Fold editor 隱藏 X 軸折彎頁。2D、3D、DXF 必須由同一 topology 得到相同結果。

### 31. 把既有 `CROSS + EXTRA_CUT` 能力誤判成「需要新增 1.5T CornerType」
- **錯誤現象**：AI 看到 `OVERLAY` 沒有左右 X 折彎，就認為十字多切不能用，進而主張為 1.5T 另外新增 CornerType；或把「不能直接改全域 0.5T」誤解成「現有模型無法表示 1.5T」。
- **根本原因**：混淆了 `CornerType`、`cross_mode`、`direction`、`amount_t` 四個層級，也把「多切的幾何手段」和「為什麼需要避讓的機械目的」綁成同一件事。
- **正確理解**：`CROSS + EXTRA_CUT` 本來就能選 `WIDTH / HEIGHT / BOTH`，`amount_t` 也可為任意正值。即使 X Fold 基底為 0，`WIDTH + 1.5T` 仍可合法形成 1.5T 寬向避讓，不需新增 CornerType。
- **OVERLAY 已確認預設**：使用者明確選擇貼外型時，封頭／封尾下方初始帶 `CROSS + EXTRA_CUT + WIDTH + 1.5T`；這只在明確切換組合方式時套用。後續人工修改下方方向／amount 後，普通刷新不可洗回預設。
- **防錯規則**：不得把全域舊預設 `C03 = BOTH + 0.5T` 改成 1.5T；也不得看到另一板金干涉就發明新 CornerType。先確認現有 `CROSS` 參數是否已能精確表達所需幾何。
### 32. 只刪 `OVERLAY` 的 X BEND，卻保留 INSERT 型 422 材料外框
- **錯誤現象**：貼外封頭／封尾畫面看起來已沒有左右 X 折線，Fold editor 也只剩 Y，但主 2D／FinalScene 展開寬仍顯示 `422`（例如 `W=400, T=2, yl1=yr1=15`）。
- **根因**：Bridge 先用舊 INSERT 型 `15 + (W-4T) + 15 = 422` 建 X profile，再只是把三段壓成一段無 angle 的 flat profile；同時 AE `build_unknown_endcap_result()` 的 structural blank 仍用 `W-4T+|yl1|+|yr1|`。也就是 BEND topology 改了，但 CUTTING/material topology 沒改。
- **正確做法**：`OVERLAY` 上方 CornerType 已表示封頭／封尾無左右 X 折彎，因此 X structural blank 必須直接使用 `W`，`left_fold/right_fold=0`，且 structural bends 不得包含 `left/right`。Bridge 的 `endcap_w_flat` 同樣直接取 `W`。
- **重要邊界**：下方 `CROSS + EXTRA_CUT + WIDTH + 1.5T` 是局部角落避讓，不能拿來加減整張封頭／封尾材料寬度。
- **真檔回歸**：`自訂(4).p6fold` 保存了舊 workspace `endcap_w_flat=422`；載入後必須依現在的 OVERLAY topology 重建為 `400`，Head/Tail FinalScene material bounds 為 `400 × 284`。

### 33. 截角縮圖只做全域翻轉，沒有區分上方／下方
- **錯誤現象**：先前為符合操作視角，把所有 CornerType 小圖一起垂直翻轉；當使用者切到下方截角時，小圖方向反而與下方實體閱讀方向相反。
- **根因**：preview transform 沒有接收目前 active corner target，只存在單一全域 Y 翻轉。
- **正確做法**：上方／左上／右上維持翻轉；下方／左下／右下恢復原始方向。小型 CornerType 選擇圖與大型預覽必須使用同一 target orientation。此改動只屬 UI。

### 34. UI 直接輸出 float，讓 `400` 顯示成 `400.0000000000006`
- **錯誤現象**：幾何意義是 400mm，但某些 UI formatter 以 `is_integer()` 精確比較後直接 `str(float)`，因此把二進位浮點尾差完整顯示。
- **根因**：把浮點表示誤差當成有效尺寸差異。
- **正確做法**：只在顯示層以極小容差判定近整數；近整數顯示整數，合法小數保持原值。禁止用顯示需求反向 round 製造幾何或 DXF。

### 35. 刪掉板件只藏 3D／右側 Tab，左側結果與輸出仍殘留
- **錯誤現象**：3D 已刪除 Door/底板等板件，主 GUI 右側 tab 可能已隱藏，但左側「展開尺寸計算結果」仍顯示該板件列、佔空間；輸出零件 checkbox 也仍留著。更危險的是，stashed `part_profiles` 或 stale checkbox 還可能讓不存在板件被重新計算／輸出。
- **根本原因**：只把 `existing_parts` 當成某一個 UI 元件的顯示條件，沒有把它提升成全鏈 physical presence Source of Truth；同時把「是否勾選 DXF」錯當成「板件是否存在」。
- **正確做法**：physical presence 與 export selection 分離。所有 2D/3D UI、結果計算、FinalScene、保存/重載、DXF/NC/批次輸出都先檢查同一份 `existing_parts`；不存在的 UI 元件用 `pack_forget`/hidden 完整移除，不留下空白。stashed profile 只供重新新增恢復，不得觸發 Scene/輸出。
- **防錯驗證**：至少要有三類 regression：不存在板件零佔位；stale checkbox=True 仍不能輸出；stashed profile 存在但 physical presence=false 時不得建 FinalScene。

### 36. 有存檔核心卻沒有讀檔 UI 入口
- **錯誤現象**：3D Fold Designer 右下已有「存檔」可輸出 `.p6fold`，程式核心也已有 `load_phase6_project()`、argv／雙擊副檔名載入能力，但工作區沒有「讀檔」按鈕，使用者在程式內形成「能存不能讀」的操作斷鏈。
- **根本原因**：只驗證 persistence backend，沒有把成對的使用流程（Save / Load）列入同一條驗收鏈。
- **後續更正後的正確做法**：`.p6fold` 是全專案檔，入口應放在主視窗左上角全域 `開啟專案 / 儲存專案 / 另存新檔`；3D Footer 不再承擔專案檔讀／存。所有入口仍共用主 GUI authoritative `load_phase6_project()`／project writer。
- **全鏈要求**：讀檔後 `W/H/D/T/FW`、CornerType、Fold profiles、holes/features、`existing_parts`、2D/3D、輸出選項與 active part 必須來自同一份 snapshot。不得只把檔案讀進記憶體卻漏刷新 UI，亦不得讓刪除板件因舊 checkbox/profile stash 復活。
- **Windows EXE**：`.p6fold` 雙擊開檔與 UI「讀檔」共用同一 authoritative loader；兩種入口不得分叉成兩套還原邏輯。

### 37. 只讓已知盤型 UI 可解鎖，卻沒有把人工參數送完整製造鏈
- **錯誤現象**：已知盤型畫面可以解鎖修改截角細參數，但存檔 snapshot 又用 `known_model_corner_state()` 重建 factory 值，或 PartSpec/manufacturing 只在自訂盤型傳 corner policy，造成「畫面改得到，存檔／2D／3D／DXF 不一定真的用」。
- **根因**：把「可編輯 UI」當成需求終點，沒有沿 Source of Truth → Save/Load → PartSpec → baseline manufacturing 追完整鏈。
- **正確做法**：已知盤型 type_id 固定，只允許同 type 細參數覆寫；實際 `manual_corner_state` 必須序列化並傳到底。baseline DXF 優先，corner policy 只換 structural outline/BEND，固定孔與 MARKING 保留。
- **防錯**：需要 known-model round-trip 測試與 baseline secondary-feature regression，不能只測 input state。

### 38. 把全專案 Save/Load 放進某一個板件／3D Footer
- **錯誤現象**：功能本身能讀寫 `.p6fold`，但按鈕綁在 Fold Designer Footer，造成專案層級能力看起來像 3D 頁面的局部功能，也讓其他頁面操作不對稱。
- **根因**：UI scope 與資料 scope 不一致；`.p6fold` 保存的是整個 project state，卻把入口放進 part-level transaction。
- **正確做法**：主視窗左上角全域提供 `開啟專案 / 儲存專案 / 另存新檔`；因 3D 是 modal、主視窗此時不能按，所以 3D 視窗左上也提供同一組全域入口。3D Footer 只留板件 `確定 / 取消`。雙擊 `.p6fold` 與 GUI/3D 開啟共用同一 loader。

### 39. 測到「鎖定 flag」卻沒測到使用者真的看到鎖、參數真的消失
- **錯誤現象**：自動測試顯示 `_corner_param_unlocked=False`，細部 entry 的某個 frame 也被隱藏，但實際畫面仍攤著大部分上/下、左右相同等編輯控制；鎖按鈕只顯示不明顯的圖示/短文字，使用者感受就是「沒有鎖也沒有隱藏」。
- **根因**：把 state test 當成 visual/layout 驗收，只檢查 helper boolean / widget object，沒有檢查實際 geometry manager 與零佔位。
- **正確做法**：2D 與 3D 鎖定時都必須顯示明確 `參數鎖定` 文字；細部參數 frame、`左右相同` 等進階控制實際 `pack_forget/grid_remove`。解鎖才重新顯示；CornerType 類型/摘要仍可保留辨識。
- **防錯驗證**：Tk regression 必須 assert 鎖鈕 `winfo_manager()` 有值、細節容器鎖定時 `winfo_manager()==''`、解鎖後恢復；不能只測內部 dict。

### 40. 3D draft 與 committed 靠 callback 默契維持，讓全域 Save 可把未確定草稿寫進專案
- **錯誤現象**：主 GUI 原本 W=400，開啟 3D 後把 staged W 改成 500，尚未按「確定」就從 3D 執行「另存新檔」；舊 Bridge 會直接序列化自己的 staged workspace，結果 `.p6fold` 被寫成 W=500。取消 3D 後畫面雖回 400，但檔案已被未確認草稿污染。
- **根本原因**：專案交易所有權分散在 `_phase6_loaded_project_path`、`fold_designer_part_bundle`、`_phase6_existing_parts`、`_fold_designer_last_part_key` 與 Bridge `_phase6_input_snapshot`；「取消就是不呼叫 commit」只是 caller 默契，沒有一個 deep module 能回答目前哪份資料才是 loaded baseline、committed、draft。
- **正確做法**：新增純 Python `ProjectSession`，正式擁有 `project_path / loaded_baseline / committed / draft` 交易生命週期；所有 snapshot crossing interface 做 defensive deepcopy。main-connected 3D project save 一律回委 main GUI，以 `snapshot_for_save()` 保存 committed；active draft 期間 `capture_committed()` 必須拒絕，防止 caller 偷繞過 transaction。
- **3D 編輯邊界**：ProjectSession 的 draft 是隔離種子／交易生命週期，不是每次 Tk 修改都同步的第二份 live state。Fold Designer 編輯自己的 defensive copy；「取消」丟棄 transaction，「確定」先把 payload 套回 main GUI，再以 canonical main snapshot `commit_draft()`。
- **導航 metadata 例外**：既有回歸要求 3D 全域 Save 可記住目前 `active_part`。這不是機械狀態，因此可當 `active_part_hint` 寫入輸出 payload，但只接受已存在於 committed `existing_parts` 的板件；不得藉此提交 draft 新增板件、尺寸、CornerType、Fold Profile 或 features。
- **執行期欄位**：`_runtime_project_path` 只用來讓 3D 知道目前檔案路徑，不能跟著 canonical snapshot 寫入 `.p6fold`。
- **防錯測試**：至少鎖住四條：draft 500 + Cancel → committed 400；draft 500 + Confirm → committed 500；draft 500 + Save → file 400；active draft 時直接 `capture_committed()` 必須拒絕。另驗證既有 committed 板件的 `active_part` 可保存，但未 committed 新板件不能偷渡。

### 41. 把「儲存為預設值」誤當成「提交目前 Runtime」，讓 3D draft 偷改 AE
- **錯誤現象**：主 GUI committed W=400，進 3D 把 draft W 改成 500，尚未按「確定」先按「儲存為預設值」。舊 `save_defaults_to_ini()` 會同時寫 `config.ini` 與呼叫 `apply_settings_to_ae()`，結果 INI=500、AE.W=500；之後即使取消 3D，主 GUI／ProjectSession 仍是 400，但 AE compatibility globals 已漂移成 500，造成不同下游可能各拿到不同答案。
- **根本原因**：把「持久化給下次啟動」和「提交目前 Runtime」綁成同一個 helper side effect；同時 GUI `_settings_state`、Tk vars、AE globals、INI 都可能被當成 current settings owner。
- **正確做法**：`SettingsService` 是 committed runtime 唯一所有者。`update()` 只更新 service + AE compatibility mirror，不寫 INI；`persist_defaults()` 只寫 persisted defaults，不更新 service/AE；`Phase6Settings` 以 immutable/defensive snapshot 跨 interface。
- **3D transaction**：Fold Designer `_settings_values` 是合法 draft，不必消滅。Cancel 不呼叫 committed update；Confirm 才把 payload 套回 main GUI 並經 service commit。「儲存為預設值」可保存 draft 給下次啟動，但不可等同 Confirm。
- **Factory Defaults**：`ae.default_config` 是「還原初始值」來源；不能拿 persisted INI 或目前 service snapshot 假裝 Factory Defaults。
- **相容層**：AE module globals 可暫時保留，但只能作 service 同步出的 compatibility mirror。低階 `save_defaults_to_ini(..., apply_runtime=True)` 只供舊 caller 相容，新 production path 必須經 service。
- **防錯測試**：至少同時斷言 service / AE / INI 三者：runtime update → service/AE 改、INI 不改；persist draft → INI 改、service/AE 不改；3D Cancel → committed/AE 不變；3D Confirm → committed/AE 一起更新；新 service 啟動才讀取新 persisted defaults。

### 42. 把 Controller 化做成「搬方法到新檔」，結果 caller 還是得知道交易順序
- **錯誤現象**：看似新增了 `Controller`，但 GUI 仍要自己判斷 `has_draft`、決定何時 `capture_committed()`、何時 `snapshot_for_save()`、何時更新 path；新類別只是把原方法包一層，刪掉它幾乎沒有複雜度回到 caller，是典型 shallow module / Middle Man。
- **根本原因**：把「拆大檔」誤當成架構目的。真正要收斂的是 interface knowledge，不是單純減少 `gui.py` 行數。
- **正確做法**：建立 `Phase6ProjectController` 深模組，讓 GUI 只提供 canonical `snapshot_provider`。Controller 自己決定：無 draft 才呼叫 provider 並 capture；有 draft Save 完全不呼叫 provider、只讀 committed；load/confirm/cancel/path/write ordering 也集中在同一 seam。
- **為什麼 provider 是重要 interface**：它讓「active draft Save 不得重新 capture View」可以被純 Python 測試直接證明，不需要啟動 Tk，也不靠 caller 自律。
- **Source of Truth 邊界**：Controller 不能再保存一份 committed/draft/path；真正 state 仍由 `ProjectSession` 擁有。`app.project_session` 若為相容性保留，只能指向 `app.project_controller.session` 同一物件。
- **失敗安全**：project writer 成功後才更新 path；寫入失敗不能留下假的新路徑。
- **防錯測試**：至少鎖住 active draft 不呼叫 provider、非法 `active_part_hint` 不生效、load 取代 draft、confirm 提交 canonical snapshot、writer failure 不改 path，以及 GUI 不再直接呼叫 ProjectSession ordering / project read-write。

### 42. 把 Workspace Controller 做成舊 dict 的包裝，或載入新專案時保留上一個 Fold Chain
- **錯誤現象**：表面新增了 Controller，但 `gui.py` 還直接讀寫 `fold_designer_part_bundle / _phase6_existing_parts / _fold_designer_last_part_key / fold_designer_box_body_profile`，實際 Source of Truth 仍散在 caller；另一種更危險的情況是先載入有 `box_body_profile` 的專案，再載入沒有 profile 的專案，舊 Fold Chain 仍留在主 2D/3D 計算中。
- **根本原因**：只把舊欄位搬進新 class，沒有把 invariant 與 replacement 語意一起收斂；同時把 `欄位不存在` 與 `欄位存在但值為 None` 混成同一件事。
- **正確做法**：`Phase6WorkspaceController` 唯一擁有 physical presence、active part、part profile stash 與 box-body Fold Chain。`box_body` 永遠存在；刪除板件只改 presence、不刪 stash；active part 必須指向現存板件。Project/3D workspace replacement 時，`box_body_profile` 欄位存在且為 `None` 代表明確清除舊 profile；欄位完全不存在才代表 partial update、保留現況。
- **相容層規則**：四個舊 GUI 欄位只可保留為直接委派同一 Controller 的 property，不能再有 backing state；production method 不得依賴這些 alias。
- **幾何責任**：Head/Tail linked profile 仍由既有幾何 resolver 產生，Controller 只保存結果，禁止把機械公式搬進 workspace module 形成第二個 AE。
- **防錯測試**：至少鎖住 mandatory box_body、authoritative presence 不受 export/indicator fallback 影響、刪除/重加 profile stash、active fallback、defensive copy、跨專案載入清除 stale Fold Chain、GUI production 不再依賴 legacy aliases。

### 43. Bridge 瘦身只搬函式到新檔，caller 還是從 Bridge 取得 domain 規則
- **錯誤現象**：`fold_designer_bridge.py` 行數看起來下降，但 `gui.py` 與其他 production caller 仍從 Bridge import CornerType、EndCap FW、Fold Profile 規則；新模組只是被 Bridge 包一層轉呼叫。刪掉新模組後複雜度沒有集中回單一 owner，反而多一層 Middle Man。
- **根本原因**：把「縮檔案」誤當成「建立深模組」。真正要移動的是 ownership 與 interface knowledge，而不是程式碼位置。
- **正確做法**：EndCap assembly/FW/raw-corner state 由 `phase6_endcap_semantics.py` 擁有；Fold Profile/linked mating chain 由 `phase6_fold_profiles.py` 擁有；`gui.py` 直接依賴 owner。Bridge 只可用 import alias 保留舊 caller compatibility，不可保留 wrapper body、第二套分支或重新計算。
- **adapter 邊界**：Tk Notebook label、Fold Designer transaction、scene/view wiring 仍屬 Bridge。不要把 `_phase6_resolve_profile_key()` 這類 UI adapter 規則硬塞進 Fold Profile domain module，只為了追求行數下降。
- **防錯測試**：用 AST/identity guard 鎖住：GUI 從 Bridge 只 import `Phase6FoldDesignerApp`；Bridge 不重新 `def` 已移出的 domain function；Bridge compatibility export 與 owner function 必須是同一函式物件；owner module 不 import Tk/GUI/renderer。

### 44. 把 FinalScene View 留在 Bridge，讓 Adapter 同時變成第二套 Renderer
- **錯誤現象**：`fold_designer_bridge.py` 同時負責 manufacturing query、profile folding、Shapely triangulation、BEND/MARKING 投影、operator 尺寸、Matplotlib axis fit、zoom。改任何 3D 顯示細節都必須理解整個 Bridge，也容易在 View 端偷偷重建第二份製造幾何。
- **根本原因**：把「拿到 `PartRenderData`」與「如何顯示 `PartRenderData`」視為同一責任；為了補視覺問題，View 又去解析 BEND/CUTTING/CornerType，破壞 Final Geometry 單一所有權。
- **正確做法**：以 `Phase6FinalSceneView` 建立 deep module。Bridge 只組 `FinalSceneViewRequest`；View 直接消費 manufacturing 已完成的 `material / scene / fold_guides`。CUTTING material 不重建，fold guide 不從 scene 再推一次，CornerType/Settings/ProjectSession 不進 View。
- **operator dimensions 邊界**：尺寸的機械數值解析仍屬 Bridge/domain adapter；View 只負責 folded-mesh outside envelope 與圖形標示。不能因為「尺寸顯示在 3D」就把 CornerPolicy/WHD 規則塞進 View。
- **相容 state**：舊 `_phase6_zoom_scale / _phase6_last_cutting_mesh` 可保留 property，但 backing state 只能在 `final_scene_view` 一份，禁止為相容性再建立 shadow state。
- **防錯測試**：View source 禁止 `build_part_render_data/material_polygon_from_final_scene/fold_guides_from_final_scene`；Bridge ownership guard 禁止 Matplotlib mesh/triangulation 實作；含 CUTTING hole 的 authoritative material 經 3D triangulation 後 hole 不可被填回。

### 45. 診斷序列化散在 Bridge 與 Project Snapshot，造成 schema／錯誤隔離雙軌
- **錯誤現象**：standalone 折彎診斷與 `.p6fold.final_geometry` 都要輸出 Scene、material、FoldGuide，但各自在 Bridge 迴圈裡序列化；之後若只修其中一條，會出現欄位格式、GeoJSON、孔洞數或 error handling 不一致。
- **根本原因**：把「如何取得 Designer state」和「如何把已完成 Final Geometry 轉成診斷資料」混在同一個 Bridge；Project Snapshot 又重複知道相同 serializer 規則。
- **正確做法**：`phase6_diagnostics.py` 統一擁有 diagnostic schema、JSON-safe、Scene／Material／FoldGuide 序列化、active snapshot 與 all-part error isolation。Bridge 只組 plain context、payload provider、render provider 與檔案對話框。
- **所有權邊界**：Diagnostics 只觀測 `PartRenderData`，不得建立／重建 CUTTING material、不得解析 CornerType/Fold Profile、不得讀 ProjectSession 或 SettingsService。`.p6fold` reloadable snapshot 仍由 Project owner 組裝。
- **錯誤隔離**：all-part diagnostics 某一板件 render 失敗，只在該 row 寫 `error`，不得讓其他板件診斷跟著消失；payload adapter 失敗則 fail-fast，不能捏造 payload。
- **相容規則**：Bridge 舊 serializer 名稱若保留，只能 direct re-export 同一 function object，不得 wrapper 或留第二套實作。

### 46. Settings Panel 只搬 Tk widget，卻把 3D draft 或機械 editor 一起搬成第二套 owner
- **錯誤現象**：看似把 `fold_designer_bridge.py` 的設定 UI 拆到新檔，但新 Panel 同時保存 `_settings_values`、重算 profile、判斷 CornerType/assembly/FW，結果只是把原本的 Bridge 巨石換成另一個巨石；取消／確定與 persisted defaults 也容易再度混線。
- **根本原因**：把「UI 元件在哪個檔案」誤當成模組邊界，沒有先分清 UI-only state、transaction draft、domain semantics 與 committed runtime。
- **正確做法**：`Phase6SettingsPanel` 只擁有 Tk vars、page cache、advanced/baseline 展示與左側全域 widgets；真正 `_settings_values` 仍是 3D draft，Panel 只能透過 callback stage/flush/save。CornerType、assembly、EndCap FW 由 extension seam 插入，Panel 不 import AE/Project/manufacturing。
- **防錯驗證**：Panel source 不得出現 `_settings_values`；advanced toggle 不改 draft；baseline query 只在展開時執行；external apply 同步 widget 不得 re-stage；Cancel/Confirm 仍用既有完整交易回歸驗證。

### 47. 只把 3D Workspace 欄位包成 property，卻讓 Bridge 繼續自行管理板件生命週期
- **錯誤現象**：新增 `Workspace` 類別後，`available_parts`、`active_part_key`、`_phase6_part_profiles` 看似都指到同一物件，但 `add/remove/switch/save/home` 仍在 Bridge 直接 `append/remove`、改 dict、切 dirty/switching flag；結果新 owner 只是資料容器，真正 ordering knowledge 仍散在 caller。
- **根本原因**：把「只有一份 backing state」誤當成「已有單一所有權」。深模組除了保存 state，還必須擁有 presence、stash、dirty、switching 的 invariant；否則下次加功能仍會繞過 owner API。
- **正確做法**：`Phase6DesignerWorkspace` 唯一管理板件存在、active/selected、profile/feature stash、dirty 與 switching。Bridge 只負責 UI/domain adapter：先從 outgoing editor 收集資料並 `stash_*`，再 `begin_switch(target)`，完成 UI／holes／settings／render 後 `finish_switch()`。
- **刪除／重加語意**：刪除只移除 presence，不刪 stash；重新加入優先恢復 stash，避免使用者暫時刪除板件後 Fold Profile／feature 資料永久遺失。`box_body` 永遠不可刪。
- **跨輸出規則**：Project snapshot、Diagnostics、Scene query、FinalScene request 都必須從同一 Workspace owner 取得 active/presence/profile/features；禁止各自從 legacy alias 手拼另一套 snapshot。
- **測試陷阱**：大量 `SimpleNamespace`／`object.__new__` 半初始化 fixture 會掩蓋必要依賴。owner 成為正式依賴後，應升級 fixture，而不是在 production 加「缺 Workspace 就退回舊欄位」的後門。
- **防錯測試**：鎖 mandatory box_body、remove→add stash restore、home 保留 stash、switch outgoing-save-before-begin-switch、compatibility property 不落 `__dict__`、Bridge production 不直接 mutate legacy backing，以及 export/diagnostics/query 都以 owner 為準。

### 48. 統一開孔編輯器把 Undo／取消／context snapshot 留在 Tk 巢狀函式，造成同一孔位有多套交易狀態
- **錯誤現象**：單一 `_open_unified_hole_editor()` 同時保存 `selected`、`active_snapshot`、`undo_history_ref`、`context_feature_lists`、`context_original_features`；插入、拖曳、旋轉、reference edit、圓孔排列又各自修改這些 list。尤其圓孔排列另有 `seed_snapshot`，會和既有 active edit 疊成第二套局部交易。
- **根本原因**：把「Tk callback 能直接改 feature list」誤當成方便。實際上 caller 必須知道何時 snapshot、何時 push Undo、何時 cancel transient、切 context 時要清什麼，交易 interface 等於散在 60 多個巢狀 callback。
- **正確做法**：以純 Python `Phase6HoleEditorSession` 擁有 context、selection、active before snapshot、Undo 與 Confirm/Cancel ordering。Tk/Canvas 只計算 candidate feature，再用封閉 `HoleEditorAction` 交給 Session；`feature_list` identity 保持原 caller list，禁止建立第二份 committed source。
- **active edit 規則**：用整個 context before snapshot 統一插入／拖曳／旋轉／基準／距離／round preview；Cancel 恢復 before，Commit 只有內容真的改變才 push Undo。
- **多 context 規則**：切換前 transient edit 必須取消；切換後 selection 與 Undo scope 重置。Cancel All 恢復每個已登錄 context 的 original；Confirm All 保留全部現況。
- **圓孔排列陷阱**：若 round dialog 開啟前已有未確認拖曳／旋轉，不能再直接建立另一份 `seed_snapshot` 當交易 owner。先把前一個 active edit 收斂，再由 Session preview transaction 管理排列預覽。
- **防錯測試**：鎖 insert→cancel、insert→commit→undo、replace→cancel、toggle/delete→undo、context switch cancel transient、Cancel/Confirm All、多 context 隔離、Undo 上限 50、round preview transaction；AST 再禁止 GUI 自建舊 state 或直接 mutation `feature_list`。

### 49. 開孔 redraw 與 hit-test 各自 resolve 一次，讓「看見的位置」與「點到的位置」可能分叉
- **錯誤現象**：統一開孔 editor 的 `redraw()` 自己建立 `CanvasTransform` 並 resolve features；mouse hit-test 又再次 `resolve_surface_features()`，並靠另一個 `transform_box` 做 canvas/world 轉換。只要顯示 viewport、extra bounds 或 feature resolver 演進不同步，就可能出現畫面孔在 A，但點擊命中仍按 B 的問題。
- **根本原因**：Canvas 顯示狀態沒有 owner。GUI callback 同時知道 transform、resolved geometry、hit tolerance、overlay placement，View interface 等於散在多個巢狀函式。
- **正確做法**：`Phase6HoleEditorCanvasView` 唯一保存最近 render 的 `CanvasTransform` 與 resolved cache；`render()` 更新它們，`canvas_to_world()` 與 `hit_test()` 只能讀這同一份 cache。GUI event 不得再次 resolve。
- **製造幾何邊界**：Door/Indicator manufacturing preview 仍由 domain/GUI adapter 算好再用 `draw_extra` 畫；View 不能 import `manufacturing_api`，也不能成為第二套製造幾何來源。
- **防錯測試**：AST 鎖住 `_open_unified_hole_editor()` 不再引用 `CanvasTransform / resolve_surface_features / hit_test_resolved_features`；真 Tk 直接驗證點孔、拖曳與 Cancel All roundtrip。

<!-- WHD_SECTION_ROLE role=HISTORICAL SUPERSEDED_BY_CERTIFIED_RELIEF_REGISTRY -->
> **[HISTORICAL/SUPERSEDED]** 本段 collision-first/backprojection ownership 是早期 discovery 架構 evidence。Registry HIT 的 current production authority 已改由 `個人AI檔案庫/第二層_專案與SOP/04_WHD鈑金展開幾何引擎規範.md` + Certified Registry 擁有；3D collision/backprojection 對 HIT 只做 shadow validation，MISS 才可 discovery/candidate。

### 50. 先用截角公式猜 Assembly Relief，沒有從真實 Collision Region 反推 CUTTING
- **錯誤現象**：面對箱身與封頭／封尾組裝干涉時，AI 直接先套 `0.5T / 1T / 2T` 或 CornerType 截角公式，試圖在 2D 端預先算出每個角要切多少；結果容易把「可能會撞」誤當成「真正撞到」，也可能多切未干涉材料或漏掉實際碰撞區。
- **根本原因**：把 Factory Policy 的經驗扣量當成 collision solver，跳過折後實體、板件角色與 ownership 判定；仍停留在「先寫公式再看圖」的舊架構。
- **正確做法**：先建立名義板件幾何與 resolved material，再做 SELF / Assembly 干涉檢查取得 `Collision Region`；接著依 ownership 判定誰保留、誰切除，將 collision 反投影成 `Relief Candidate`，最後更新 2D `CUTTING`、重建 `PartRenderData / FinalScene` 並再次驗證沒有殘留干涉。
- **第一版已固化範圍**：`Box Body ↔ EndCap / Tail`，箱身 `RETAIN`，封頭／封尾 `CUT`；以 Shapely 2.5D footprint 作為可驗證第一版，不宣稱已完成完整 3D solid CAD kernel。
- **防錯規則**：
  1. 不得先由零件名稱、變數名稱或 CornerType 公式猜 relief。
  2. 固定 T 倍數只能作為 clearance / policy 參數，不能取代 collision region。
  3. 若切除面積與真實 intersection 不一致，優先檢查是否 over-cut；例如 `10 × 30` 的碰撞只應先移除 300，再依明確 clearance 擴張。
  4. GUI / renderer 不得呼叫 solver；solver 留在 `ae_engine` manufacturing boundary，renderer 只消費完成後的 `PartRenderData`。

### 51. 底層有 Assembly mode，卻沒有讓使用者直接看得到「組合體」入口
- **錯誤現象**：程式已存在 `_phase6_3d_display_mode="assembly"`、render request 與 assembly scene，測試也能通過，但實際操作畫面只看到一個下拉控制或根本沒注意到「組合體」，使用者直接判定「沒看到組合體」。
- **根本原因**：把 state / API / source-level contract 當成 UI 完成條件，沒有把「可發現性與實際 layout」列入驗收。
- **當時修法（已廢止）**：曾改成 3D 置頂列固定顯示 `單件`、`組合體` 兩顆按鈕。此入口已由後續最新規格取代；現在 `組合體` 必須是左側 `板件選擇` 第一項，第一次進 3D 直接選中，禁止再恢復第二套模式按鈕。Assembly 第一階段仍只顯示箱身 + 封頭 + 封尾。
- **防錯驗證**：使用真 Tk 建立 Fold Designer，確認兩顆按鈕 `winfo_viewable()==1`；invoke `組合體` 後 mode 必須變 `assembly`。只 assert dict / label / Menubutton values 不算驗收。

### 52. ZIP 中文路徑被封裝成 literal `#Uxxxx`，AI 庫看似消失或整包像亂碼
- **錯誤現象**：原本應是 `新WHD/個人AI檔案庫/...` 的路徑，在交付 ZIP 內變成 `#U65b0WHD/#U500b#U4ebaAI...`；這不是使用者電腦字型問題，而是 ZIP entry 名稱已在打包前被錯誤 escape。
- **根本原因**：沿用會把 Unicode path 轉成 `#Uxxxx` literal 的封裝/中繼樹，再從錯誤樹打包；即使 Markdown 內容是 UTF-8，路徑本身已被破壞。
- **正確做法**：從保有真實 Unicode 檔名的來源樹打包，使用支援 UTF-8 filename flag 的 ZIP writer；不得從 `#Uxxxx` 中繼目錄反向猜名修復。
- **交付前硬性檢查**：
  1. ZIP entries 不得含字串 `#U`。
  2. 必須存在 `新WHD/個人AI檔案庫/README.md` 與中文 SOP 路徑。
  3. 實際解壓後逐項確認中文檔名保留。
  4. 新增/修改的 `.md/.py` 必須能以 UTF-8 strict decode；偵測到 Unicode replacement character（U+FFFD）即拒絕交付。

### 2026-08-27：只把組合體做成內部 state／隱藏模式，使用者實際找不到入口
- **錯誤現象**：程式有 `_phase6_3d_display_mode="assembly"`、renderer 也能組 mesh，但使用者在正式 3D Designer 看不到「組合體」，或入口藏在另一個控制列／下拉裡。
- **根本原因**：把「底層能力存在」誤當成「UI 功能已交付」，而且同時存在 `板件選擇` 與 `單件/組合體模式` 兩套導航。
- **正確做法**：`組合體` 直接成為 `板件選擇` 第一項；第一次進 3D 就選組合體。選實際板件自動回 single mode，不再保留第二套單件/組合體按鈕。
- **防錯測試**：真 Tk 驗證 menu 第 0 項、初始 `part_var`、assembly mode、Fold Editor/板件設定隱藏；選箱身後 single mode + Fold Editor 顯示。

### 2026-08-27：3D UI 控制散落在右側畫布上方，導致版面與使用者操作模型不一致

> **SUPERSEDED_BY_ISSUE163_LAYOUT**：本節的「最上列還含 3D 顯示／全螢幕／transaction」已由 #160/#163 最新使用者規格取代；僅保留為歷史事故背景，不得再當 current layout oracle。
- **錯誤現象**：`結構 / 組合方式 / 參數鎖定 / 3D模式` 被塞在右側畫布控制列，`文字大小` 又放在全域設定第三行；使用者指定的永久置頂兩行全域配置被破壞。
- **根本原因**：每加一個功能就就近塞 widget，沒有維持固定 layout ownership。
- **正確做法**：最上列只放檔案、3D 顯示視覺控制、全螢幕與 transaction；全域設定固定兩行；左側只負責板件/折彎；右側只負責解鎖後板件設定與 3D canvas。
- **防錯測試**：assert widget master + grid row，而不是只測文字存在；並 assert `right_control_bar is None`，避免舊控制列復活。

### 2026-08-27：UPDATE ZIP 多包一層專案目錄，導致使用者解壓後實際程式沒有被覆蓋
- **錯誤現象**：UPDATE 內路徑是 `新WHD/fold_designer_bridge.py`；使用者已經在 `...\新WHD` 目錄內解壓時，檔案變成 `...\新WHD\新WHD\fold_designer_bridge.py`，執行的仍是舊版。
- **根本原因**：FULL 與 UPDATE 使用同一 archive root 規則，沒有區分「完整包保留專案資料夾」與「更新包直接覆蓋專案根目錄」。
- **正確做法**：FULL 可保留最外層專案資料夾；UPDATE 必須以專案根目錄為 archive root，直接包含 `fold_designer_bridge.py / ae_engine/... / tests/... / 個人AI檔案庫/...`。
- **防錯驗證**：打包後列出 UPDATE 前幾個 entry，禁止所有檔案都以 `新WHD/` 開頭；實際解壓到空的模擬專案根目錄並 SHA256 比對。
### 52. 組合體只用 EndCap bbox／旋轉名稱定位，造成留肉與折邊接合語意錯誤
- **錯誤現象**：封頭／封尾雖被放到箱身上、下方，但留肉沒有真正貼在箱身接合面，或左右／下折邊跑到箱身外；曾把 Tail 做成 world-Y 180° 旋轉，導致 X 左右也被反掉。
- **根本原因**：把 assembly 當成純視覺旋轉，而沒有沿用既有 `組合方式 -> CornerType -> resolved Fold Profile` 語意；另外用 EndCap 整體 bbox 中點重設 local Z，破壞 `z=0` 接合基準。
- **正確做法（已由 2026-08-28 physical-sheet 規則補強）**：先由組合方式解析 Fold Profile topology。local `z=0` 是板厚中心面、local `+z` 代表真實折邊朝箱內。Head +Z 往 world-Y 下方；Tail 保持 native X/Y（不得再鏡射 local Y），+Z 往 world-Y 上方。實體接合面由 T 厚 physical sheet 的**內側 skin**提供：中心面向箱外偏移 T/2，使 inner skin 貼 box-body 上/下 mating plane。`OVERLAY` X 必須 flat；`INSERT / INSERT_OVERLAY` 才有左右 X 折邊。Viewer 與 collision 共用同一 helper。
- **防錯驗證**：用非對稱 EndCap mesh 明確 assert Tail X 不反轉、local Y 也不反轉、local `+z` 進箱內；Tail Fold Profile 已是 native orientation，assembly 禁止二次上下鏡射；再用 `build_endcap_xy_profiles()` 對 `INSERT / OVERLAY / INSERT_OVERLAY` 跑真 profile，確認留肉/core 平面接觸箱身且所有正 Z 折邊都落在箱身高度範圍內。
### 53. 專案內保留第二套可執行 GUI，更新正式程式後使用者仍看到舊畫面
- **錯誤現象**：根目錄 `gui.py / fold_designer_bridge.py` 已更新，但使用者啟動後版面完全沒變；專案內其實還存在 `基準檔/gui.py` 的完整舊 GUI 副本。
- **根本原因**：同一專案存在兩個可執行 Source of Truth，捷徑或工作目錄一旦落到 `基準檔` 就永遠跑舊碼。
- **正確做法**：`基準檔/gui.py` 只能作 compatibility launcher，先切到專案根目錄並以 `runpy.run_path()` 執行唯一 authoritative `gui.py`；禁止再保存第二套完整 GUI。
- **防錯驗證**：測試需確認 `基準檔/gui.py` 為短 redirect（<100 行），而不是數千行 GUI 副本。

### 54. 組合體 backing active_part 與真實選單切換混用，造成「組合體 → 箱身」切不過去
- **錯誤現象**：第一次進 3D 顯示組合體，使用者從 `板件選擇` 點 `箱身` 後選單文字變箱身，但左側 Fold Editor 仍隱藏，看起來完全切不過去。
- **根本原因**：組合體模式為了取得幾何，底層仍保留 `box_body` 作 backing `active_part`；Tk Menu radiobutton 又會先把 `part_var` 改成 `箱身` 才呼叫 `activate_part()`。舊程式看到 `active_part == box_body` 且文字已不是 `組合體` 就 early-return，漏掉 assembly -> single 的真正 mode transition。
- **正確做法**：進 `activate_part()` 第一時間先保存 `was_assembly`，再改 mode。只要 `was_assembly=True`，即使目標 key 等於 backing active part，也必須完整執行 single-part restore：顯示 Fold Editor、重建板件設定、刷新 3D。
- **防錯驗證**：真 Tk 測試必須先手動 `part_var.set("箱身")` 模擬 Menu radiobutton 的真實順序，再呼叫 `activate_part("box_body")`；驗證 mode=`single` 且 `fold_editor_host.winfo_manager()` 非空。

### 55. EndCap 組合體只畫零厚度中心皮，造成「成型外面消失／折邊像由內往外穿」
- **錯誤現象**：標準金庫型封頭／封尾的 Fold Profile 與 BEND 數量其實完整（INSERT / INSERT_OVERLAY 標準狀態為 X 2 折 + Y 3 折），但組合體看起來沒有真正成型的外側板面，左右／下折邊像從箱身裡面往外穿。
- **根本原因**：`folded_mesh_from_polygon()` 只產生零厚度 mid-surface；舊 assembly 又直接把 local `z=0` 中心皮貼在箱身 mating plane。`T` 沒有參與 EndCap 3D 實體化，因此不存在可區分的內側接觸面與外側成型面。
- **正確做法**：保留 Fold Profile / 2D / DXF 不動；先依 authoritative profile 折出 mid-surface，再用真實 `T` 建立 ±T/2 兩個 skin、材料外周側壁與非共面 fold-edge miter bridge。Head/Tail 的中心面向箱外偏移 T/2，使「內側 skin」貼箱身、外側 skin 留在箱外，所有 local +Z 折邊仍朝箱內。viewer 與 3D collision 必須共用這套 physical-sheet geometry。
- **防錯**：看到 EndCap 成型怪異時，先檢查 `Fold Profile/BEND count` 與 `physical sheet thickness` 兩層；不能因視覺像少折就擅自增刪 `ytop1/FW/ybottom1`。標準未修改金庫型仍必須保留完整 5 道 BEND。

### 56. EndCap 實體化後直接畫 closed-solid boundary，造成「孔消失／第一折與留肉折線看不到」
- **錯誤現象**：標準未修改金庫型的封頭／封尾在組合體中，底層 `material` 仍有 baseline CUTTING 孔、Fold Profile 仍有完整 X 2 + Y 3 = 5 道 BEND，但畫面看起來孔全部消失，`ytop1` 上面第一折與留肉附近的折彎稜線也像沒做。
- **根本原因**：EndCap physical-sheet 改成封閉 solid 後，viewer 仍只對 thickened solid 執行 open-boundary edge extraction。封閉實體的 through-hole tunnel 與折彎 crease 都不是 open boundary：孔邊界被側壁封閉，折彎稜線則是兩個面共享的內部邊，因此視覺線全部被吃掉。這是 renderer regression，不是孔資料、CUTTING、Fold Profile 或 BEND 數量消失。
- **正確做法**：physical solid 照舊渲染；另外必須從**加厚前、已依 final BEND guides 折好的 authoritative mid-surface**抽取可視特徵線：`edge adjacency == 1` 為外輪廓／through-hole 邊界；共享 edge 的相鄰三角面法向非共面時為真實 formed crease。共面 triangulation diagonal 必須排除。
- **禁止誤修**：看到孔／折線沒顯示，不得去重建孔、增加 BEND、恢復已刪 segment、改 CornerType 或改 assembly placement；先確認 `PartRenderData.material.interiors`、Fold Profile、folded mid-surface 是否仍正確。
- **永久驗證**：組合體 physical EndCap 測試必須同時鎖住：有孔 material 加厚後仍有 hole outline 可視線；有第一折的 folded surface 必須出現跨板面的非共面 crease，而不是只剩 T 厚度側邊。

### 57. 孔輪廓畫在 EndCap 中心面，實體加厚後仍「看不到孔」
- **錯誤現象**：`material.interiors` 明明存在、physical solid 也真的有 through-hole，但組合體上看不到孔；前一版甚至已從 folded mid-surface 抽 hole boundary，畫面仍像實心。
- **根本原因**：mid-surface 是板厚中心面，不是可視外皮。加厚後它位在 ±T/2 skin 之間，深度排序會被實體面遮住；EndCap 又貼在 BoxBody 上時，孔後方是另一片實體面，更容易看成沒有孔。
- **正確做法**：從 `thicken_triangle_surface()` 的 physical solid 抽 feature edges：共享 edge 的相鄰面法向非共面即為可視物理稜線，孔口會自然產生在兩個 skin 的 rim；共面 triangulation diagonal 排除。mid-surface crease 只能當 fallback，不能當孔口唯一線源。
- **折彎線規則**：3D `BEND` guide 與 physical fold feature edge 全部畫實線；不得再用虛線讓使用者誤判為參考線或被透明面吃掉。
- **防錯測試**：T=2 的有孔平板，hole rim 至少要在 z=+1/-1 skin 各有完整輪廓；`_draw_scene_bends()` 必須輸出 `linestyle='-'`。

### 58. 組合體參數解鎖被 assembly guard 吃掉
- **錯誤現象**：第一次進 3D 是組合體，按「參數鎖定」後 state 有切換但右側完全沒反應。
- **根本原因**：`_phase6_toggle_parameter_panel()` 舊邏輯明確禁止 assembly mode 顯示任何右側 panel。
- **正確做法**：組合體解鎖顯示獨立「組合體診斷」而不是箱身設定；切到實際板件才顯示該板件 settings。
- **防錯測試**：真 Tk assert assembly unlock 後 diagnosis frame = `pack`，切回箱身時 diagnosis frame 隱藏且板件設定重新顯示。

### 59. 固定截角診斷拿整片 EndCap 做碰撞，會把正常接合縫誤報成整圈干涉
- **錯誤現象**：標準金庫型補回固定截角後，早期版本回報 947 段紅色交線，紅線沿整個上緣、左右接合縫與正常插入位置跑；即使不補回固定截角，整片 production EndCap 仍可產生數百段假交線。
- **根本原因**：surface/triangle crossing 只能回答兩個 mesh 表面是否相交，無法自行理解「這條是設計上允許的 mating seam」。把整片 EndCap 當 target，就會把正常貼合／插入接觸也一起掃進來。這不是視覺顏色問題，而是 probe ownership 錯。
- **正確做法**：固定截角診斷 target 必須先做 `restored - production`，只折起並加厚這個 **relief delta**；再拿它與 BoxBody physical solid 求穿越。標準金庫型本測試環境因此由 947 段整圈假紅縮成 454 段局部交線（Head 227 + Tail 227），只集中在固定截角角落。
- **視覺規則**：因 target 已限制成 relief delta，可把真正命中的 delta triangles 畫成半透明紅面，再疊紅色實線 intersection segments；禁止把整片 EndCap 的 hit triangle 染紅。
- **關閉診斷**：未勾 `診斷時忽略固定截角` 時，不得退回整片 EndCap 求碰撞；停止固定截角 probe 並提示使用者先啟用該診斷。
- **ownership 防線**：renderer 不得直接 import `assembly_collision`；純幾何／delta helper 放既有 `assembly_geometry`，production relief solver 仍留在 `assembly_collision`。
- **交付防線**：AI 在交付碰撞視覺前必須自己至少檢查 Head、Tail 兩個視角；若紅區沿正常長接縫擴散，視為不合格，不得叫使用者代驗收。
- **防錯測試**：assert `restored_endcap_relief_delta` 只含補回材料；renderer collision target area 必須小於整片 EndCap；ignore=false 時 detector 不得被呼叫；delta hit triangles + solid intersection lines 可局部顯示。

### 60. 3D 干涉能畫紅區，不代表已得到可生產截角尺寸
- **錯誤現象**：只把 world-space 干涉線/紅區畫出來就宣稱截角完成；或直接拿舊固定截角尺寸、world bbox、Shapely buffer 當正式尺寸。
- **根本原因**：世界座標交線沒有 EndCap/Tail 展開座標語意；板厚兩側 skin 還可能產生多條近似交線。若不保留 flat UV 並回折驗證，數字看起來精確也可能是假精準。
- **正確做法**：folded triangle 保留 flat UV；3D crossing point 用 barycentric 回投 2D；依角落既有 topology band 取各級最大實際干涉深度；切除後重新折回 3D，只有剩餘 material interior 無穿透才 verified。
- **迭代防線**：第一輪 cut 可能露出更深一層干涉，必須 `cut → refold → project` 迭代到收斂；A=0 的 CUTTING 邊界接觸不是材料穿透。
- **淨空防線**：A 在收斂後做正交軸向精確擴張，不使用 polygon buffer 斜接；標準測件 A=5 應由 `39×38 + 14×4` 精確變成 `44×43 + 19×4`。
- **數值防線**：對稱件若左右 canonical shape 只差 <0.01~0.02 mm 級 tessellation noise，可在嚴格 Hausdorff 容差內取 union；不得把真正非對稱差異抹掉。
- **BEND 防線**：dynamic cut 比 legacy fixed cut 少切時，BEND 也必須依新 material 重 clip；本標準測件左 X BEND span_start 由 legacy `42` 恢復為 `38`，FW 水平 BEND 左端由 `16` 恢復為 `14`。CUTTING 對但 BEND 還舊，仍視為未完成。
- **Source of Truth 防線**：verified cut 進 `EndCapPartSpec`，Manufacturing API 統一供 2D/3D/DXF；GUI/renderer 只顯示，不可另算一套截角。參數/Fold Profile 改變時舊 cut 必須失效。

### 61. UPDATE 只更新 AssemblyScene caller、漏掉 dataclass contract，造成組合體整頁 3D 載入失敗
- **錯誤現象**：正式主 GUI 第一次進 `組合體`，3D 畫布顯示 `AssemblySceneRenderData.__init__() got an unexpected keyword argument 'show_interference'`。
- **實際重現**：`065113 FULL` 直接套 `130705 UPDATE` 可 100% 重現；130705 UPDATE 內有新的 `fold_designer_bridge.py`，但沒有 `phase6_final_scene_view.py`。
- **根本原因**：caller 新增 `show_interference / ignore_fixed_corner_relief` constructor kwargs，而舊 `AssemblySceneRenderData` 只有 `assembly_parts / warnings`。這是 UPDATE 原子性破壞，不是 Tk、Matplotlib 或使用者環境問題。
- **正確做法**：
  1. caller 與其 dataclass/interface owner 視為同一個更新原子；其中一側 contract 變更，UPDATE 必須帶另一側。
  2. `_phase6_make_assembly_scene_render_data()` 依 live constructor signature 過濾 optional kwargs，保留 mixed-version 相容底線。
  3. 交付前除乾淨 FULL 外，必須實際建立「舊 FULL + 新 UPDATE」疊版副本，由主 `gui.py` 打開 3D Designer，驗證 `cutting_mesh_error is None`。
- **禁止**：只跑當前工作樹測試就宣稱 UPDATE 可用；這抓不到 caller/contract 在使用者舊樹上的版本錯配。

### 62. 3D 反投影 solver 全角 restore 造成未求解角落長回 16×16 角片
- **錯誤現象**：組合體的封頭／封尾在非接合側兩角多出一片實體角料；標準金庫型可量到每片多出的角料各為 `16×16 = 256 mm²`。
- **根本原因**：`restore_unrelieved_endcap_material()` 為了 3D 探測先把整個 EndCap 外框四角全部補回矩形，但 solver 實際只對有干涉的兩個 mating corners 產生新 cut。最終若直接用 `restored - cut_polygon` 當 production material，另外兩個沒有被本輪求解的 legacy corner relief 也會被永久補回。
- **正確做法**：full restored blank 只能當 3D probe/reference。正式 `solved_material` 必須從 authoritative 原始 `endcap_render_data.material` 出發，只 union 回「本輪 `raw_cuts` 確實求解到的 corner delta components」，再 subtract verified dynamic cut；未求解角落保持原 material 不動。
- **標準金庫型證據**：修正前 solved-original 新增 `528 mm² = 2×256 + 2×8`；修正後只新增正確留肉 `16 mm² = 2×(2×4)`，兩個錯誤 `16×16` 角片消失。
- **防錯測試**：標準 Head/Tail dynamic relief 後，`solved.material.difference(original.material).area == 16 mm²`（A=0 regression），且新增材料 bounds 只能落在本輪兩個 mating corner bands，不能出現在對側 legacy corner。

### 63. 封頭尾有實線 BEND，但組合體箱身只畫 mesh 外框，造成箱身折彎線消失
- **錯誤現象**：單件箱身的 3D BEND 是實線，封頭／封尾組合體也能看到 crease，但組合體箱身看不到 authoritative 折彎線。
- **根本原因**：assembly render path 對 EndCap 有 physical-sheet feature/crease overlay，對 Box Body 卻只呼叫 `_add_mesh_boundary_lines()`，完全沒有把 `PartRenderData.scene` 的 BEND 映射到組合 world-space。
- **正確做法**：先用同一 Fold Profile 將 Box Body BEND 端點映成 local folded 3D，再以完整箱身 mesh 為 reference 呼叫共享 `place_assembly_points()`，最後以藍色實線疊到組合體。
- **禁止**：以 BEND 線自身 bbox 做 placement；這會因中心基準不同而把線畫到錯位位置。
- **防錯測試**：組合體 Box Body scene 含 BEND 時，`ax.lines` 必須至少存在一條 `color='#2563eb'` 且 `linestyle='-'`；真主 GUI 標準金庫型另需確認實際可見。

### 64. 參數解鎖 state 已切換，但右側面板 pack 在 expand canvas 後面而實際只有 1×1
- **錯誤現象**：第一次進組合體後按「參數鎖定」，button/state 已變成解鎖，`winfo_manager()` 也回報 `pack`，但右側設定／組合體診斷肉眼完全看不到。
- **根本原因**：3D Matplotlib canvas 已先用 `pack(fill=BOTH, expand=True)` 吃滿右側空間；設定 frame 後 pack 時雖有 manager，實際 geometry 可能只剩 1×1。只 assert `winfo_manager()=="pack"` 會產生假綠燈。
- **正確做法**：所有右側可切換 panel 統一走 `_phase6_pack_right_panel_above_canvas()`；若 canvas 已 pack 且同 parent，必須 `widget.pack(before=canvas_widget, side=TOP, fill=X, ...)`，保證 panel 排在 canvas 前面。組合體解鎖顯示 diagnostics；切實際板件後顯示 settings center。
- **防錯測試**：必須真的 `parameter_lock_button.invoke()`，再 `update_idletasks()/update()`；驗 `winfo_viewable()==1` 且 `winfo_height()>1`，不能只驗 manager。另鎖 `組合體解鎖 -> 箱身` 後 diagnostics 隱藏、settings center 真可見。
- **環境防線**：Tk/Matplotlib 自動驗證不以截圖或長時間 mainloop 作 completion gate；優先用 `invoke + geometry introspection`，避免 headless/虛擬顯示重繪阻塞。

### 65. 3D solver 與 2D replay 各自持有 material，造成「組合體組錯」的雙 Source of Truth
- **錯誤現象**：2D 看起來正確，但 3D 組合體的 Head/Tail 形狀、截角或組合狀態不同；實檔甚至可出現 project `assembly_type=INSERT_OVERLAY`，但保存 relief source 仍是舊 `INSERT`。
- **根本原因**：3D solver 直接顯示自己的 `solved_render_data`，主 2D/DXF 則從 saved relief cuts 另走 Manufacturing replay；兩條資料鏈可在不同時間點、不同 assembly semantic 下各自成立。
- **正確做法**：移除 3D 確定/取消 draft。3D solver 只產生 verified cut answer；production cut 必須回寫 canonical `assembly_relief_state`，再由同一 Manufacturing provider 重建 2D/3D/DXF。
- **防錯**：任何來源 fingerprint 不符就清 stale relief；真實檔案回歸必須比較 2D vs assembly material symmetric difference = 0。

### 66. Head/Tail relief 非原子更新造成半套新、半套舊組合
- **錯誤現象**：Head solver verified、Tail failed 時，舊程式先把 Head 新 material 畫進組合體，Tail 卻仍用舊 2D，形成不可能的機械狀態。
- **根本原因**：在逐片 solve loop 裡立即採用成功結果，而不是先收集兩片 verification 再提交。
- **正確做法**：先 collect Head/Tail solutions；required parts 全部 verified 才一次 publish cuts。任一失敗，兩片都重新 query 目前 canonical provider，只顯示診斷錯誤。
- **禁止**：把 `solution.solved_render_data` 當 production truth；它只允許作 solver verification/reference。

### 67. 「winfo_manager()==pack」或 state 已變，不代表 UI/資料真的同步
- **延伸教訓**：參數解鎖曾出現 frame 已 pack 但 1×1 不可見；2D/3D 同步也可能 state 欄位已更新但 geometry 仍是另一份。
- **正確驗收**：UI 用 `winfo_viewable + geometry`；幾何同步用 authoritative `PartRenderData.material` symmetric difference；狀態同步用 canonical snapshot/fingerprint。禁止只驗 callback 被呼叫或只驗畫面看起來差不多。

### 68. EndCap 真板厚兩張 skin 的外側交線被誤當 penetration，38 被算成 38.98→39
- **錯誤現象**：同一 `自訂(9)`，2D／組合圖顯示約 `39×27`，而使用者確認真正製造尺寸應為 `38×27`。
- **證據**：同一 mating corner 的兩側 physical skin 回投影約落在 `37.02` 與 `38.98`；真實折後接合邊界位於兩者中心 `38.00`。
- **根本原因**：solver 把板厚 skin 與箱身正常貼合的 contact band 納入 crossing envelope，並取外側 extrema 當 relief 邊界。這違反「面／線接觸不是實體穿透」。
- **正確做法**：單級 `INSERT` 排除 ±T/2 正常 contact 帶，以真實 mating boundary 求 primary relief；candidate 必須重新 refold，只有實際 penetration 為 0 才 verified。
- **禁止**：把 38.98 四捨五入成 39 再宣稱正確；也禁止直接 `-0.5T` 硬修成 38。38 必須從 mating geometry 自己推導出來。
- **防錯測試**：`test_deleted_fold_insert_relief_keeps_single_stage_topology_across_iterations` 要求 Head/Tail 兩角 `primary_u=38`、`primary_v=27`、無 secondary stage、`verified=True`。

### 69. 程式已修但文件未跟同版交付，導致下一輪 AI 仍讀到舊規則
- **錯誤現象**：`PHASE6_ENDCAP_RELIEF_38_SYNC_*_20260829_002730.zip` 已有程式與測試修正，但 `修改日誌`、Superpowers verification、AI/SOP、handoff/交付說明仍停在前一輪；使用者必須再提醒「該補的文件呢」。
- **根本原因**：把「測試通過 + ZIP 可解壓」誤當 completion gate，沒有執行 README 已明定的「程式修改即同步文件」規則。
- **正確做法**：出包前建立 documentation gate：至少檢查 `修改日誌/YYYYMMDD.md`、對應 verification、AI/SOP 規格、踩坑庫、handoff/交付說明是否反映本輪幾何與 UI 契約；再打 FULL/UPDATE。
- **禁止**：先交程式包、等使用者問了才補文件。文件與程式不是兩次交付，而是同一 atomic delivery。

### 70. 用已切完的 final material 畫碰撞診斷，UI 會假報「未偵測到碰撞」
- **錯誤現象**：solver 明明已產生 relief，組合圖卻顯示 0 段／未偵測到穿越。
- **根因**：renderer 對已套 relief 的 canonical final material 再跑 collision；原始干涉已經被自己切掉。
- **正確做法**：bundle 同時保存 pre-solve diagnostic probe 與 solved production part；紅色碰撞區只讀 pre-solve probe，正式 3D/2D/DXF 只讀 solved canonical material。
- **防錯**：registry GUI matrix 必須 assert `interference_probe_parts` 含 Head/Tail，並實際 render 後 `last_interference_diagnostic.has_interference=True` 且 segments > 0。

### 71. OVERLAY flat-X 跳過 topology normalization，triangle crossing 會長出假二級
- **錯誤現象**：合法單級角顯示 `25×11.332 + 24.231×0.15` 等微小第二級；左右甚至一邊 11.482、一邊 10.5。
- **根因**：曾因 OVERLAY 沒有 X 折彎而整片跳過 topology normalization；三角化 skin crossing 的小階梯直接變成 manufacturing cut。
- **正確做法**：assembly intent 決定合法 topology，3D 只決定尺寸；flat-X 也必須壓回 component topology。對真正鏡像對稱的 folded profiles/components，使用 mirrored collision evidence union 消除單側漏採樣。
- **禁止**：看到 residual 0.x mm 就直接提高全域 collision tolerance；只能在 topology boundary band + mid-surface clear 雙條件下把 crossing 分類為 contact。

### 72. 手工列 INSERT/OVERLAY/INSERT_OVERLAY 測試清單，新增組合仍會漏測
- **錯誤現象**：現有三種修好了，但下一個新 assembly intent 上線後沒有自動進回歸，仍要使用者親自試才知道能不能用。
- **根因**：測試 whitelist 與 production registry 分離。
- **正確做法**：所有組合驗收 parametrized `BOX_ASSEMBLY_TYPE_IDS`；新增 intent = 自動增加 solver matrix + GUI matrix。未通過不得交付。

### 73. [HISTORICAL/SUPERSEDED — 不可作 runtime oracle] OVERLAY v2 formed-FW 演進踩坑
- **症狀**：同一 `W=400/T=2/FW=25` 貼外型曾先得到 40/320，之後又被改成 25/350；兩次都沒有用實際組裝占位做最後驗證。
- **根因**：40 是把 nominal side=15 錯加進 flat-X；25 則是只看 EndCap nominal FW，忽略箱身 FW 折後成型占位。
- **正解**：EndCap `frame_width` 仍是 25；Box Body Fold Profile 的 FW 材料段 25 在兩相鄰真折彎、T=2 下 formed occupation=29。OVERLAY 上方每側 X CUT=29，中央342，單側 `29+371=W400`。Y relief 仍用 EndCap FW25，不可被 29 放大。
- **下方**：獨立 CROSS/EXTRA_CUT/WIDTH/1.5T，仍每側 3、中央394。
- **[HISTORICAL/SUPERSEDED — 不可作 runtime oracle]** 當時 `ENDCAP_TOP_OVERLAY_STANDARD_V1@2` 宣告 `BOX_BODY_FORMED_FW`；此段只保留演進/fixture 證據。
- **防錯**：禁止硬寫 29 或 `FW+2T`；formed occupation 必須從當前 Fold Profile + T 重新求。
- **[CURRENT 2026-09-02]** Active rule 是 `ENDCAP_TOP_OVERLAY_STANDARD_V1@3`：STANDARD + semantic delta，`primary_u=side_fold+FW`、`primary_v=ytop1+FW-T`、`secondary_u=side_fold`、`secondary_depth=T`；T2/side15/FW25/ytop1=16 fixture = `40×39 + 15×2`。
- **[CURRENT]** formed FW 只可作 3D shadow/collision evidence，**不得作 runtime oracle**；`40×23 + 16×4` 僅是 linked-FW INSERT_OVERLAY fixture。

## 2026-08-29：Phase6 UPDATE 不可用「上一包」做窄差異
- 症狀：FULL 看似正常，但 UPDATE 套到使用者既定底包後出現「缺東缺西」。
- 根因：把上一個 ChatGPT FULL 當 baseline，只打本輪幾個差異檔，漏掉使用者尚未取得的前序累積變更與 `個人AI檔案庫/**`。
- **[CURRENT 2026-09-03] 固定規則**：Phase6 UPDATE 唯一累積基準改為 `PHASE6_GUI_PERFORMANCE_KNOWLEDGE_FULL_20260903_124853.zip`；UPDATE = 相對此基準的全部真實差異 + mandatory files + `個人AI檔案庫/**` 全樹。2026-08-23 的 `PHASE6_FW_LINK_BUGFIX_FULL_20260823_212355(3).zip` 僅保留為歷史 release 紀錄，不再是現行 packaging gate。
- 禁止：`config.ini`、`BACKUP/**`、快取不得進 UPDATE。
- 驗證：FULL/UPDATE 必須同一 Asia/Taipei 時間戳；ZIP CRC、解壓後逐檔 SHA256、AI 全樹存在、`config.ini` 不存在全部通過才可交付。
- 修改功能時禁止無驗證地順手改無關路徑；若另一條資料鏈屬既定交付 gate（例如 Door/Base Plate 單板 3D canonical FinalScene），必須用 red/green 證據決定是否保留，不得只靠「看似無關」撤掉。

### 2026-09-02：把 Skill Preflight 當成完整開工 Preflight，導致踩坑庫仍可合法漏讀
- **錯誤現象**：`AGENTS.md` 雖要求先跑 `phase6_skill_preflight.py` 並讀完 required Skills，但沒有要求全域踩坑庫與領域 reference evidence；Agent 可以「Preflight 全過」後直接修改，仍重踩已知坑。
- **根本原因**：把 Skills、踩坑庫、canonical 規格誤當成同一層知識來源，只對 Skill 做 machine gate，沒有把完整開工知識載入建成單一 fail-closed Source of Truth。
- **防錯規則**：Phase6 開工一律執行 Knowledge Preflight。`REQUIRED SKILLS` 與 `REQUIRED REFERENCES` 都必須完成；全域踩坑庫永遠必讀，領域踩坑庫/canonical references 由 `.agents/skills/skill_registry.json:required_references` 自動加入。Reference evidence 必須使用 `READ_REFERENCE: <repo-relative-path>`，少任一項即 exit 1；Subagent 必須自行重跑並留下自己的 evidence，總控 evidence 不可代用。
- **回歸防線**：`tests/test_phase6_skill_preflight_gate.py` 必須驗證「無 route 仍要求全域踩坑庫」、「組合/OVERLAY route 自動要求領域踩坑庫」、「只有裸路徑不算 reference evidence」、「缺任一 reference fail closed」。

### 2026-09-02：Release 長回歸靠人工切批與對話記憶，外層 TIMEOUT 後一直重跑
- **錯誤現象**：Xvfb / pytest 本體其實已經 pass，但工具回合在 summary 前後被切掉；下一輪只能靠文字記憶「跑到第幾顆」，又從 25/50/100 顆手工切批。更糟時 timeout 留下孤兒 pytest/Xvfb 99% CPU，後續批次全部被拖慢，看起來像 production 一直卡住。
- **根本原因**：測試完成狀態沒有 durable Source of Truth；外層工具生命週期、pytest process、Xvfb process 與人工回報混在一起。人工 completed index 既不能驗 collection 版本，也不能保證 timeout 後 process tree 被清乾淨。
- **正確做法**：長回歸固定使用 `tools/phase6_release_test_runner.py`。每個成功 batch 立即 fsync 到 JSONL journal，另寫 state JSON；同一 journal 綁定 pytest collection SHA256/count。`exit 75` 代表本時間片安全結束、仍有 pending tests，下一輪直接用同一命令續跑，不得重頭來。
- **Timeout 規則**：每個 pytest batch 必須在獨立 process group；batch timeout 時 kill 整個 process group。timeout/failed batch 不算 complete；多顆 batch 自動二分縮批，直到定位單顆。只有單顆 failure/timeout 才算真正阻塞，回 root-cause/TDD。若 pytest 已印出完整成功 summary、只是 interpreter/GUI teardown 不退出，記為 `complete_teardown_timeout` 後 kill group 並繼續，不能把健康測試誤判成紅燈。
- **禁止**：不得把外層 TIMEOUT 當 pytest FAIL；不得拿 1270-test journal 套到 1275-test collection；不得只在對話中記「前 650 顆已過」而沒有 journal；Headless 與 Xvfb 必須使用不同 journal。

### 2026-09-02：runner 自管 Xvfb 仍只靠 finally，外層 SIGKILL 後留下 orphan display
- **錯誤現象**：batch timeout/process-group cleanup 都正常，但外層工具直接 hard-kill runner 後，pytest 已不在，`Xvfb :90` 卻被 PID 1 收養繼續存活；後續 GUI gate 可能撞 display／浪費 CPU。
- **根本原因**：`managed_xvfb()` 的 `finally` 只有 Python interpreter 有機會收尾時才會執行；`SIGKILL` 不可攔截。把 Xvfb 放進獨立 session 又沒有 parent-death contract，等於主動讓 child 脫離父程序生命週期。
- **正確做法**：Linux 啟動 Xvfb 時設定 kernel parent-death signal（`prctl(PR_SET_PDEATHSIG, SIGTERM)` 或等價），並處理 fork→prctl 之間父程序已死的 race；正常路徑仍保留 process-group TERM/KILL cleanup。
- **防錯測試**：真啟動 parent runner + Xvfb，讀出 Xvfb PID，對 parent 送 `SIGKILL`，確認 child 在短時間內消失或成 zombie。mock `finally` 不算驗證。

### 2026-09-02：live-canonical 已取消 Confirm/Cancel，舊實檔測試仍把 confirm callback 當 oracle並留下 Tk grab
- **錯誤現象**：`自訂.p6fold` 的 remove/add 本身已即時同步主 GUI，舊測試卻要求 `confirm_corner_transaction() is True`；失敗後直接 `root.destroy()` 又可能把 designer grab 留給下一顆測試，造成 `another application has grab` 假紅燈。`自訂(6).p6fold` 另把已成功替換成 CERTIFIED INSERT_OVERLAY relief 的 state 誤判成「應 disabled」。
- **根本原因**：測試 oracle 還停在已移除的 transaction/draft 架構，沒有跟第 65 條 live-canonical Source of Truth 一起遷移；cleanup 又繞過正式 Return-to-2D seam。
- **正確做法**：remove/add 直接驗主 GUI 即時狀態；離開 designer 走 `_phase6_return_to_2d_corner(...)` 的 flush/save/publish/close 路徑；stale relief 測試應驗舊 intent 被目前 certified registry 解**原子替換**，而不是無條件清空。
- **防錯**：真 `.p6fold` 回歸要合跑而非只單跑，確認前一顆不殘留 Tk grab；若單跑 PASS、接在某顆後才 fail，先做 prefix/order isolation，不得改幾何常數。

### 74. Family snapshot 混有字串 setting 時，用「非 bool 一律 float」會把尺寸 transaction 截成半套
- **錯誤現象**：切到受電箱後 snapshot 已是 `800/1600/350`，但 3D 輸入框、live settings、主 GUI 還是舊尺寸；畫面像是預設值偶爾失效。
- **根本原因**：同一 settings snapshot 不只有數值，還有 `ui_text_size="medium"` 這類 enum/string。通用 store path 把所有非 bool 都 `float(value)`，拋例外後又被外層 broad `except: pass` 吞掉，transaction 只完成前半段。
- **正確做法**：setting normalization 必須按 schema/key 分派；`ui_text_size` 走自己的 normalizer，bool/numeric 各自處理，並讓 snapshot/live settings 使用同一 normalized value。Family switch regression 必須同時驗 snapshot、settings、實際 Tk vars 與主 GUI，禁止只驗其中一層。

### 75. Cabinet Family 不得自動擁有 AssemblyJoint relation；WRAP 不得有第二顆 enable UI
- **錯誤現象**：只切「受電箱」就把 Head/Tail BOTTOM 變成 WRAP；3D 封頭尾同時又有「啟用外側包覆／啟用 WRAP」，導致 operator 不知道組合方式與 checkbox 哪個才是真值。
- **根本原因**：把 Receiving 的 geometry/reserve policy 誤升格成 Joint ownership，並讓 legacy `endcap_bottom_wrap.enabled` / Tk checkbox 可以回寫 canonical Joint Graph，形成雙 Source of Truth。
- **正確做法**：Cabinet Family 只提供 family geometry、structure、reserve defaults；mechanical relation 由 Assembly Intent → Resolved AssemblyJoint Graph 決定。正式 `包覆貼外` preset 才投影 `BOTTOM=WRAP`；Receiving family alone 不得猜 WRAP。3D 若 Joint 已是 WRAP，只能顯示 reserve X/Y editor，不能再提供 enable/disable relation 的第二入口。
- **防錯測試**：切 Receiving 後先 assert BOTTOM 保持目前 Intent（例如 INSERT_OVERLAY 的 BOTTOM=INSERT）；再選 `包覆貼外` assert Head/Tail BOTTOM=WRAP；全域 3D 列不存在獨立 WRAP Checkbutton；reserve editor 改值後 Joint relation fingerprint 不變。

### 76. 永久回歸不可依賴已不存在的 `/mnt/data/自訂*.p6fold` 外部實檔
- **錯誤現象**：完整 Xvfb suite 每次固定留下 conditional skip，只因測試硬編碼 `/mnt/data/自訂.p6fold`、`自訂(2).p6fold`、`自訂(6).p6fold`，但使用者已不再持有或提供這些檔案。
- **根本原因**：把一次性的使用者上傳檔案當成永久 regression fixture；用 `Path.exists() -> pytest.skip()` 掩蓋 fixture 已失效，導致 release 永遠帶著不可執行的測試。
- **正確做法**：永久 suite 不得依賴 ephemeral `/mnt/data` 使用者檔。仍有長期價值的案例要轉成 repo 內可版本化的 canonical/synthetic fixture；若原始實檔已不存在且沒有可保存的 fixture，就移除該外部實檔測試。
- **Release 防線**：tests 內不得重新出現上述 retired absolute paths；若刪除既有 test module，UPDATE policy 必須同步加入 cleanup path，避免舊基準覆蓋後殘留。

### 77. GUI ↔ 3D live-sync echo 會把單次輸入放大成重算風暴
- **錯誤現象**：只改一次 W/H/D，GUI 卻卡數秒；profiling 看到數十次 `update_calculations()`、FinalScene rebuild 與重複 render。
- **根本原因**：Main GUI 把 state 送入 3D 後，3D 又 publish 同一份 state 回 Main GUI；整包 `var.set()` 再觸發 Tk trace，形成 GUI → 3D → GUI echo loop。相同值 `StringVar.set()` 仍會觸發 trace，不能用「值沒變」當安全假設。
- **正確做法**：Scheduler 是唯一 calculation executor；Transaction Guard 只收 dirty/flush。同步 envelope 使用 `origin + revision + transaction_id + actual delta`；相同 state 不回送。批次套值使用 `set_var_if_changed`/canonical compare。
- **防錯驗證**：單一 geometry edit 應 `recalculation <= 1`、live-state echo=0、render<=1；不能只驗 callback 有被呼叫。

### 78. DXF source cache 與 derived geometry cache 混在一起，尺寸修改會反覆打網路磁碟
- **錯誤現象**：改一個尺寸就重新讀同一 DXF 數十次；檔案在 `Z:\` 時卡頓被網路 I/O 成倍放大。
- **根本原因**：live snapshot/geometry edit 無條件清 baseline cache，parsed DXF 與 W/H/D 衍生 geometry 沒有分層。
- **正確做法**：DXF source cache 使用 path + size + mtime_ns + parser/schema version + reload generation；W/H/D/FW 只 invalid derived geometry。Force Reload 必須可繞過 fingerprint。
- **網路失聯規則**：GUI preview 可暫用 last-known-good 並標記 `SOURCE_UNVERIFIED`；manufacturing / Export / DXF / NC 不得用 unverified source 冒充 fresh truth。

### 79. 3D initialization publish default/舊 revision，會把使用者剛輸入的新 state 蓋回去
- **錯誤現象**：主 GUI 剛改尺寸，同時開啟 3D 後數值又跳回舊值；或初始化時產生多輪 publish/rebuild。
- **根本原因**：初始化中間 state 與 Main GUI live state 沒有 revision 優先級；3D default 被誤當 authoritative。
- **正確做法**：`INITIALIZING` 期間只 ingest，不 publish intermediate/default。優先級固定為「使用者目前輸入 > authoritative application state > persisted state > 3D default」；初始化完成比對 current revision，一致則 publish=0，stale revision 必須 reject。

### 80. 長任務只在聊天或臨時工作樹記進度，下一回合就失去真正續跑點
- **錯誤現象**：已跑到 440/1291、940/1291 等進度，但容器/工作樹重置後只剩對話文字，無法證明 completed nodeids、collection SHA 或已套 patch，只能重跑或猜。
- **根本原因**：把聊天回報當 durable Source of Truth，沒有獨立 **durable checkpoint**。
- **CURRENT 做法**：WHD durable execution state 由 `WHD_EXECUTION_RECORD_V2` 擁有；authoring 固定 executor-local `WORKSPACE_DEFAULT` + fresh production baseline。Drive/shared-zero 已退役；有無 historical drift 都固定 WORKSPACE_DEFAULT，不得啟動 shared-zero fallback、merge/freeze 或 /推推 前置。 長 profiling/stress/release raw artifacts 只作 evidence；`/mnt/data` 只可作 transient materialization，不是 durable execution state。跨 runtime 先 fresh-read ExecutionRecord、baseline 與 exact run/artifact readback。
- **禁止**：下一回合不得從聊天文字猜「大概跑到哪」；先讀 durable state。

### 81. 用跑過 pytest 的目錄做 FULL vs UPDATE overlay 比對，會被 __pycache__/.pytest_cache 製造假 mismatch
- **錯誤現象**：UPDATE 覆蓋後共同檔案 SHA 全相同，但樹檔案數仍不一致，看起來像 UPDATE 漏檔。
- **根本原因**：FULL 驗證目錄先跑過 Python/pytest，新增 `__pycache__/.pytest_cache/.pyc` 等測試產物；overlay 目錄是 pristine，兩邊不是同一比較條件。
- **正確做法**：FULL/UPDATE overlay 最終逐檔比較必須使用兩個**pristine、從未執行 Python/pytest 的 fresh extraction**。測試目錄與封包完整性比較目錄分離。
- **防錯**：先驗 archive entry/CRC，再在 pristine extraction 做 missing/extra/hash mismatch；測試產物一律排除。

### 82. 1291 顆 regression 全過，不等於 GUI 真實連續操作一定順
- **錯誤現象**：單元/整合測試全綠，但使用者快速改尺寸、切板件、切 Family/Assembly Intent、連續操作 3D 時仍可能卡頓或事件暴增。
- **根本原因**：一般 regression 驗功能 oracle，未必覆蓋「短時間多事件」與 wall-time/call-count 行為。
- **正確做法**：GUI 效能修改另設**真 GUI 壓力** gate：連續 W/H/D/T burst、箱身/封頭/封尾快速切換、Family/Assembly Intent 切換、3D 開關/互動；逐步記 wall time、recalculation、DXF disk read、manufacturing resolve、render，並驗最終 state/scene 不 stale。
- **禁止**：只用 headless 或「1291 PASS」宣稱 GUI 不會卡。

### 83. release runner 只看到父程序先退出就 return，process group 子程序可能仍存活
- **錯誤現象**：timeout cleanup 後 pytest/Python parent 已退出，但 child process 偶發仍是 running；下一批被孤兒程序拖慢，測試又出現不穩定 timeout。
- **根本原因**：`_kill_process_group()` 在送 SIGTERM 後只等待 parent exit；父程序先退出就提前 return，沒有確認同一 process group 的 descendants 已全部消失。
- **正確做法**：process group cleanup 的完成條件是整個 group 消失，不是 parent `poll()!=None`。TERM 後仍需檢查 group，必要時 KILL；測試應驗 child tree 真正消失。
- **測試防線**：不要把「child PID 必須在 1 秒內建立」混成 kill-tree oracle；先確保 child 已啟動，再驗 timeout cleanup。flaky startup timing 與 process-group cleanup correctness 必須分開。

### 84. release runner `--reset` 先刪 journal 再搶 lock，會在「鎖拒絕」時仍破壞 durable evidence
- **錯誤現象**：舊 runner 正持有 journal lock 並正常續跑；第二個 runner 對同一 journal 執行 `--reset`，最後雖回報「journal already in use」，原 journal 的 collection header 卻已被刪掉。舊 runner 接著只會追加 batch 記錄，形成「有 completed nodeids、沒有 collection SHA/count」的無效 release evidence。
- **根本原因**：CLI reset 順序是 `unlink journal/state → acquire run lock`。run lock 只能阻止第二個 runner進入執行區，無法復原它在搶鎖之前已完成的破壞性檔案操作。
- **正確做法**：所有 reset/unlink 必須搬進 `journal_run_lock(...)` 之內：`acquire lock → 若 reset 則 unlink journal/state → 建立/驗證 collection header → 執行 suite`。持鎖失敗必須 fail closed，不能觸碰既有 journal/state bytes。
- **防錯測試**：真啟動一個持鎖 runner，再對同一 journal 執行第二個 `--reset`；第二個必須被拒絕，且前後 journal bytes/header 完全相同。只 mock lock helper 不算，因為這個坑就是 CLI ordering。

### 85. Scheduler 已成唯一 executor 後，legacy partial GUI fixture 缺 seam 不能靠 production fallback 救
- **錯誤現象**：完整 suite 只有舊 `SimpleNamespace` / `__new__` fixture 直接呼叫 GUI handler 時出現 `AttributeError: ... _request_phase6_update`；真 `BoxCalculatorGUI` 與正式 GUI 流程正常。若為了讓這顆舊測試過，在 handler 寫 `hasattr(...)` 後直接 `update_calculations()`，表面綠燈卻把 Scheduler 唯一執行權重新打破。
- **根本原因**：架構 seam 已升級，但 partial test double 還停在舊 handler interface；把 fixture 缺介面誤判成 production 相容性需求。
- **正確做法**：先確認真 production instance 一定擁有 Scheduler seam、且測試 oracle 並非在驗「沒有 Scheduler 時仍可運作」。若成立，更新 test fixture 使其提供 `_request_phase6_update(...)` 等正式 seam；禁止在 production 增加 direct calculation/do_update fallback。
- **防錯測試**：Scheduler ownership regression 必須繼續鎖住 direct executor bypass；legacy handler fixture 只 stub 正式 request seam。等價 part switch/display-only 操作應驗 `render=1、full calculation=0`，不要保留舊的 `update=1` oracle。
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

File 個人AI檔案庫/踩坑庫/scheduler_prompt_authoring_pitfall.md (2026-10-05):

---
whd_doc_role: REFERENCE
whd_contract: scheduler-prompt-authoring
whd_canonical: null
whd_schema: WHD_DOC_META_V1
---
# Scheduler Prompt Authoring / 排程「有醒但沒施工」踩坑

> **[HISTORICAL / SUPERSEDED EXECUTION MECHANICS — FLOW_V2_LEGACY_EXECUTION_HISTORY_FENCE_V1]**
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

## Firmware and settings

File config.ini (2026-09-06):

[DEFAULT_SIZES]
w = 400.0
h = 600.0
d = 250.0
t = 2.0
fw = 25.0

[BOX_BODY_Z]
zl1 = 15.0
zl2 = 20.0
zr1 = 15.0
zr2 = 20.0
z_comp = 2.0

[END_CAP_Y]
yl1 = 15.0
yr1 = 15.0
ytop1 = 16.0
ybottom1 = 15.0

[OUTPUT]
draw_stock = false

[UI]
text_size = medium

[HOLES]
hang_hole_radius = 3.2
hang_hole_x_offset = 35.5
hang_hole_y_from_top_bend = 6.0
square_hole_x_from_left = 3.0
square_hole_width = 4.0
square_hole_y_from_bottom = 18.0
square_hole_height = 4.0
bottom_hole_radius = 2.5
bottom_hole_y_from_bottom = 5.0

[NOTCH]
bottom_gap = 0.5
sub_x_half_t = 0.5
sub_y_factor = 2.0

[RELIEF]
top_secondary_x_factor = 0.5
top_secondary_depth_factor = 2.0
bottom_x_factor = 0.5
bottom_y_factor = 0.5

[DOOR]
door_gap_w = 3.5
door_gap_h = 3.5
door_fold_left = 19.0
door_fold_right = 15.0
door_fold_top = 15.0
door_fold_bottom = 15.0

[INDICATOR_BOX]
fold = 49.0
shared_baseline_model = 

[BASE_PLATE]
shrink = 55.0
bend = 15.0

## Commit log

2026-09-28 fix(#902): add isolated work-slot request branches
2026-09-28 governance(#902): isolate scheduler and work-slot transaction lanes
2026-09-28 governance: auto-increment /工作0 to first free slot
2026-09-28 governance: define /工作0 first-free routing
2026-09-28 governance: route default interactive work to first free slot
2026-09-28 flow-v2: add first-free work-slot selector
2026-09-28 test: lock /工作0 first-free routing
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2026-09-28 governance(#927): restore existing liveness owners into Flow v2 observer
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2026-09-28 fix(928): rewire assembly FinalScene provider and durable render log
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2026-09-28 ci: cover Flow v2 control transaction and exit gate
2026-09-28 fix(933): project terminal Flow v2 records as monitor EXIT
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2026-09-28 flow-v2: classify scheduler host exit without progress as failure
2026-09-28 governance(#940): bind Skill writes to current Flow v2 hard gates
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2026-09-28 governance(#940): allow only scope-bound sequential CAS mutation chain
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2026-09-28 governance(#940): bind Flow v2 mutation to fresh startup evidence
2026-09-28 reconcile(#945): layer watchdog onto latest Flow v2 contract
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2026-09-28 fix(#948): mirror .agents/skills/engineering/flow-v2-execution/SKILL.md to main
2026-09-28 fix(#948): mirror .agents/skills/engineering/排程模擬/SKILL.md to main
2026-09-28 governance(#961): wire work-root gate into Flow v2 startup
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2026-09-28 fix(#952): restore control-plane path filter entry
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2026-09-28 fix(#952): preserve current cleanup tree during base refresh
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2026-09-28 test(#975): lock systemic Flow v2 closure stability
2026-09-28 docs(#975): make closure stability systemic in Flow v2
2026-09-28 test(#975): wire closure stability into control-plane regression
2026-09-28 mirror(#975): sync Flow v2 closure stability governance to main
2026-09-28 mirror(#975): trust GitHub closed_at for Flow v2 release timestamp
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2026-09-28 flow-v2: bind SYNC_TARGET to PR and target identity
2026-09-28 flow-v2: enforce merge precheck and trusted target sync
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2026-09-28 test: cover trusted Flow v2 target sync transport
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2026-09-28 flow-v2: require live merge precheck and target sync
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2026-09-28 test: align atomic regressions with current finalize and exit contracts
2026-09-28 test: align Flow v2 fixtures with current finalize and exit gates
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2026-09-28 governance: mirror Flow v2 merge precheck and target sync
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2026-09-29 Issue #996: layer workspace/test-profile gate onto latest Flow v2
2026-09-29 fix(flow-v2): drain FINALIZE terminal tail on cleanup authority
2026-09-29 issue1025: reduce Flow v2 transaction round trips
2026-09-29 issue #1022: document connector mutation rejection recovery
2026-09-29 issue #1022: preserve retryable Flow v2 conflicts
2026-09-29 issue #1022: require slot identity in scheduler authoring
2026-09-29 issue #1022: require slot identity in scheduler reports
2026-09-29 issue #1022: require exact work-slot identity in reports
2026-09-29 issue #1022: harden root-local-first receipt and connector recovery
2026-09-29 issue #1022: enforce handler slot identity regression
2026-09-29 issue #1022: merge test receipt with current root gate contract
2026-09-29 issue #1022: merge receipt and connector recovery into current root-local-first skill
2026-09-29 issue #1022: preserve current root gate tests and enforce test receipt
2026-09-29 issue #1022: preserve pitfall history and append connector rejection rule
2026-09-29 issue1032: cut over Flow v2 semantic docs
2026-09-29 issue1037: fix root-local CURRENT Drive pointer identity
2026-09-29 test: advance root-local CURRENT pointer to v4 fast-path gate
2026-09-29 issue1040: rewrite scheduler reference onto Flow v2 semantics
2026-09-29 issue1040: reconcile authority-map roles with Flow v2 mirrors
2026-09-29 issue1040: stop current routing from auto-loading legacy execution owners
2026-09-29 issue1040: demote legacy continuity reference to Flow v2 history
2026-09-30 issue1043: turn legacy continuity routing test into Flow v2 anti-regrowth
2026-09-30 issue1043: normalize continuity authority test to Flow v2
2026-09-30 issue1043: update authority-map normalization test for Flow v2 mirrors
2026-09-30 issue1043: enforce narrow Flow v2 MIRROR bridge semantics
2026-09-30 issue1043: add chunk-local Flow v2 fences to continuity history
2026-09-30 issue1043: add chunk-local Flow v2 fences to claim history
2026-09-30 issue1043: add chunk-local Flow v2 fences to closure history
2026-09-30 issue1043: allow explicit Flow v2 MIRROR bridges in strict validation
2026-09-30 issue1043: align legacy authority resolver tests with Flow v2 mirrors
2026-09-30 issue1046: make AGENTS dispatch projection-only under Flow v2
2026-09-30 issue1046: force Flow v2 first for mirror exact-skill routes
2026-09-30 issue1046: invert checkpoint tests to Flow v2 anti-regrowth
2026-09-30 issue1046: replace legacy checkpoint contract with Flow v2 projection rules
2026-09-30 issue1046: run residual Flow v2 anti-regrowth tests in control plane
2026-09-30 issue1046: watch residual Flow v2 anti-regrowth tests
2026-09-30 issue1046: add Flow v2 residual anti-regrowth v2 contract
2026-09-30 issue1049: track Drive root-local canonical payload
2026-09-30 issue1049: track Drive work-root canonical payload
2026-09-30 issue1049: require Flow v2 whenever remote-QA mirror routes
2026-09-30 issue1049: continue repository-content cycle after Flow v2 DONE
2026-09-30 issue1049: forbid connector ref advancement on production targets
2026-09-30 issue1049: remove connector production-update fallback
2026-09-30 issue1049: watch Flow v2 anti-regrowth v3
2026-09-30 issue1049: run Flow v2 anti-regrowth v3
2026-09-30 issue1049: lock root-local test to current Drive canonical hash
2026-09-30 issue1049: lock work-root test to current Drive canonical hash
2026-09-30 issue1049: add Flow v2 anti-regrowth v3 coverage
2026-09-30 issue1049: guard connector-merge durability trigger
2026-09-30 issue1049: document connector-merge export transport
2026-09-30 issue1056: harden Flow v2 anti-regrowth v4 surfaces (1/2)
2026-09-30 issue1056: harden Flow v2 anti-regrowth v4 surfaces (2/2)
2026-09-30 issue1059: Flow v2 anti-regrowth v5 process-test cutover
2026-09-30 fix(receiving): mark inner-door joints on receiver mother plates (#1050)
2026-10-01 fix(scope): keep current task sticky (.agents/contracts/WHD_ROOT_LOCAL_FIRST_ENTRY_HARD_GATE_V1.json)
2026-10-01 fix(scope): keep current task sticky (.agents/skills/engineering/root-local-first/SKILL.md)
2026-10-01 fix(scope): keep current task sticky (tools/root_local_first_gate.py)
2026-10-01 fix(scope): keep current task sticky (tests/process/test_root_local_first_entry_hard_gate.py)
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2026-10-02 feat(receiving): resolve certified multi-Bay side-lock joints (#1113)
2026-10-02 fix(#1113): wire acceptance test into product CI
2026-10-02 fix(flow-v2): ignore stale released residue in owner stickiness (#1133)
2026-10-02 test(#1113): compare width invariance in certified unfolded frame
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2026-10-02 fix(#1113): canonicalize Joint coordinates after transform
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2026-10-03 flow-v2: add trusted stale work-branch deletion transport
    Keep stale branch absence as a hard gate while giving RELEASE_PATHS a trusted GitHub-side delete/readback transport. Unblocks #1062 without direct coord rewrites or connector branch-delete bypass.
2026-10-03 Flow v2: stale record live-target reconcile bridge (#1161)
    Deliver WHD #1159 docs/0 generation 23 frozen governance patch.
    Preserve /Google Drive/WHD canonical root and Flow v2 governance. The ingress bridge is limited to explicit RECONCILE stale-record closure recovery with fresh live target read and stale source/target ancestry proof; normal STARTUP_TRANSITION_STALE_IDENTITY remains fail-closed.
2026-10-04 Flow v2: mint trusted GitHub Actions invocation provenance (#1164)
    Complete #1162 using docs/0 generation 24. Bind an explicit sentinel to immutable GitHub Actions runtime provenance before startup validation; keep ordinary explicit identity paths fail-closed.
2026-10-04 receiving: finalize OPEN-02 pairing inset at 5 mm
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2026-10-04 docs: cut final turn-exit reference to retired gate
2026-10-04 docs: remove retired continuity path from CURRENT startup surface
2026-10-04 test: drop retired dispatch wrapper from current-surface assertion
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2026-10-04 test: account for retired Flow v2 bridge shims
2026-10-04 test: lock retired execution identities to Flow v2 aliases
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2026-10-04 test: guard deleted Flow v2 migration tests against regrowth
2026-10-04 test: retire final Flow v2 migration-only regression files
2026-10-04 purge: remove legacy scheduled-resume runtime from current regression routing
2026-10-04 test: treat retired execution identities as Flow v2 aliases not bridges
2026-10-04 test: preserve T6 freeze while permitting CURRENT retirement
2026-10-04 test: materialize retired frozen paths only inside historical migration fixture
2026-10-04 flow-v2: project scheduler stuck-work takeover candidates
2026-10-04 flow-v2: wire scheduler takeover decision into wake order
2026-10-04 flow-v2: tighten scheduler takeover eligibility
2026-10-04 docs: align 推推 delivery tail with Flow v2 and durability V2
2026-10-04 governance: bind push delivery tail to Flow v2 DONE
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2026-10-04 test: include 推推 shared-unpushed contracts in control-plane gate
2026-10-04 test: lock 推推 scope regression to immutable fileset lock
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2026-10-04 test: admit scheduler Phase6 push workflow as CURRENT surface
2026-10-04 flow-v2: add trusted scheduler Phase6 receipt rebind contract
2026-10-04 flow-v2: bind scheduler lane and source invocation into Phase6 receipt
2026-10-04 flow-v2: resolve scheduler Preflight GREEN from trusted bot receipt
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2026-10-04 flow-v2: reject scheduler Preflight continuation after live HEAD drift
2026-10-04 push: bridge ChatGPT cloud mount into Codex workspace
2026-10-04 root: separate canonical authority from Codex mount visibility
2026-10-04 governance: classify Codex cloud-mount invisibility as staging transport
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2026-10-04 root-entry: bind default flow to executor-local workspace policy
2026-10-04 agents: cut over to executor-local workspace-first content flow
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2026-10-04 test: cut work-root gate over to executor-local workspace
2026-10-04 test: prevent shared-zero sync from regrowing as default workspace flow
2026-10-04 test: align anti-regrowth reservation assertions with workspace-first flow
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2026-10-04 agents: keep remote authority non-propagation under workspace-first flow
2026-10-04 test: cut issue1032 semantic guard to workspace-first current flow
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2026-10-04 test: align canonical root-local order with workspace-first flow
2026-10-04 fix(scheduler): repair host task generation rollover (#1198)
    * fix(scheduler): allow WAKE task generation rollover
    * fix(scheduler): track active A00 and B15 hosts
    * test(scheduler): lock host lifecycle gap regression
    * test(control-plane): include issue1196 scheduler regression
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2026-10-05 governance: align Flow v2 with workspace-first content routing
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2026-10-05 governance: preserve remote control-plane boundary without Drive-root coupling
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2026-10-05 flow-v2: add trusted missing-record recovery writer
2026-10-05 flow-v2: route missing records through trusted post-delivery recovery
2026-10-05 flow-v2: preserve exact PR merge anchor across target advance
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2026-10-05 flow-v2: reconcile merged PRs to exact merge commit anchor
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2026-10-05 flow-v2: auto-drain open sibling issues from merged delivery
2026-10-05 #1221 wire Registry panel directly to presentation owner
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2026-10-05 issue1212: port Codex liveness fix (.agents/skills/engineering/flow-v2-execution/SKILL.md)
2026-10-05 issue1212: port Codex liveness fix (.agents/skills/engineering/排程模擬/SKILL.md)
2026-10-05 issue1212: port Codex liveness fix (.agents/skills/engineering/寫技能/SKILL.md)
2026-10-05 issue1212: port Codex liveness fix (個人AI檔案庫/第二層_專案與SOP/08_WHD技能建立與修改規則.md)
2026-10-05 issue1237 r3: port Codex liveness (.agents/skills/engineering/執行開發任務/SKILL.md)
2026-10-05 issue1237 r3: port Codex liveness (.agents/skills/engineering/派工/SKILL.md)
2026-10-05 issue1237 r3: port Codex liveness (.agents/skills/engineering/工作槽/SKILL.md)
2026-10-05 issue1237 r3: port Codex liveness (.agents/skills/engineering/強制接手/SKILL.md)
2026-10-05 issue1237 r3: port Codex liveness (.agents/skills/engineering/寫排程/SKILL.md)
2026-10-05 issue1237 r3: port Codex liveness (.agents/skills/engineering/拆解任務工單/SKILL.md)
2026-10-05 issue1250: cut scheduler reference over to workspace-first
2026-10-05 issue1250: align pitfall library with workspace-first CURRENT
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2026-10-05 #1257 refresh Assembly-type selection patch onto latest X
2026-10-05 #1257 restore narrow Assembly-type selection delegate on latest X
2026-10-05 #1257 restore Assembly-type selection ownership guard on latest X
2026-10-05 issue1265: make Git connector pitfall workspace-first
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2026-10-05 issue1250: remove Drive-first scheduler CURRENT rule
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2026-10-05 fix: stabilize baseline switching and render Receiving 3D preview (#1290)
    * fix: replay issue 1285 fold_designer_adapter.py
    * fix: replay issue 1285 fold_designer_settings_coordinator.py
    * fix: replay issue 1285 receiving_set_bay_controls.py
    * fix: replay issue 1285 phase6_settings_transitions.py
    * fix: replay issue 1285 test_issue498_settings_application_coordinator.py
    * fix: replay issue 1285 test_issue517_receiving_live_switch_ui_export_marking.py
    * test: replay issue 1285 test_phase6_t11_family_preset_switching.py
    * test: replay issue 1285 test_receiving_layer_ui_regression.py
2026-10-05 fix: clean Receiving/Vault round-trip and complete layer preview (#1294)
    * fix: keep BoxBody child tabs out of assembly modes
    * fix: add layer removal and clean 3D preview surfaces
    * fix: support tail-only Receiving layer removal
    * fix: rebuild family topology and preview complete assembly geometry
    * fix: wire Receiving layer removal control
    * test: cover clean complete preview and layer removal
    * test: enforce reverse 3D switch, full preview, and layer removal
    * fix: reset all known-family profiles on baseline switch
    * test: known family switch resets every profile
    * test: expose per-part signatures on family round-trip failure
    * fix: clear Receiving topology when leaving Receivin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
2026-10-05 fix: align Receiving preview and Base Plate placement (#1300)
    * fix: mate Base Plate to rear inner cabinet plane
    * fix: render BoxBody back panel without overlay lines
    * fix: build Receiving preview through FinalScene render request
    * fix: reuse FinalScene palette in Receiving preview
    * test: preview must reuse FinalScene palette
    * test: preview repeats FinalScene assembly with shared palette
    * test: Base Plate mates to rear inner datum
    * test: Receiving Base Plate keeps cell XY at rear plane
    * test: back panel keeps solid geometry without overlay lines
    * test: Base Plate rear datum follows D T and bend
2026-10-05 governance: remove Drive fallback from Flow v2 routing
2026-10-05 fix: keep push skill CURRENT metadata valid
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2026-10-05 fix: Receiving preview controls and physical hole visibility (#1307)
    * fix(#1301): replay accepted Receiving patch on current X
    * fix(#1301): replay accepted Receiving patch on current X
    * fix(#1301): replay accepted Receiving patch on current X
    * fix(#1301): replay accepted Receiving patch on current X
    * fix(#1301): replay accepted Receiving patch on current X
    * fix(#1301): replay accepted Receiving patch on current X
    * fix(#1301): replay accepted Receiving patch on current X
    * test(#1301): replay Receiving acceptance on current X
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2026-10-05 test: make Flow v2 terminal independent of Drive durability
2026-10-05 governance: remove retired shared-zero keys from CURRENT root contract
2026-10-05 governance: stop carrying retired shared-zero keys in CURRENT validator
2026-10-05 fix: keep neutral exact delivery-lock utilities current
2026-10-05 test: keep exact delivery lock current and mark zero cleanup historical
2026-10-05 test: align v3 anti-regrowth with workspace-only terminal flow
2026-10-05 docs: remove retired shared-zero token from Flow v2
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
